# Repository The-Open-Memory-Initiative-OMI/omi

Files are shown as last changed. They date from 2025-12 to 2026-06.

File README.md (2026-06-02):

<!-- SPDX-License-Identifier: CC-BY-SA-4.0 -->

# The Open Memory Initiative (OMI)

The **Open Memory Initiative (OMI)** is a place to take memory hardware apart and rebuild it in the open - the kind of end-to-end reference work usually locked behind paywalled JEDEC raw cards and vendor NDAs. Every design decision is documented, every artifact is reproducible, and claims match reality: work is described at exactly the stage it has reached (schematic, validated, …), never more.

OMI treats memory as a *first-class architectural system*, not a black box.
The project emphasizes **documentation-first design**, explicit constraints, and reproducible validation - starting with mature PC DDR technologies.

This is an **engineering-first, correctness-oriented effort**, not a product launch.

---

## New here?

📄 **[START_HERE.md](./START_HERE.md)** — Beginner-friendly onboarding guide with contribution tracks, starter tasks, and a full repository map.

---

## Why OMI Exists

Open CPUs, SoCs, and accelerators are now common. System memory is not.

Despite being fundamental to computation, modern DRAM modules remain opaque, proprietary, and difficult to study or reproduce outside closed industrial contexts.

OMI exists to close this gap by providing:

- An open, reference-quality memory design target
- A transparent engineering methodology
- Documentation that explains *why* decisions were made, not just *what* was built

---

## Project Status

OMI v1 is a **reviewable DDR4 UDIMM reference design**: 8 GB, single rank (1R), x8 DRAM devices, non-ECC (64-bit bus). **The schematic stage is complete.**

### ✅ Schematic capture — complete, ERC-clean, and netlisted

The OMI v1 schematic is captured in KiCad and **passes Electrical Rule Check with 0 violations — no exclusions, no waivers**:

- A real **288-pin DDR4 UDIMM card-edge connector (`J1`)**, pin-mapped from the JEDEC keystone pin map. The placeholder host connectors used during early capture have been **removed** — `J1` is the genuine module edge.
- **18 / 18 real components footprinted**: `J1` (288-pad card edge), 8× DDR4 SDRAM (FBGA-78), one SPD EEPROM (UDFN-8), and 8× ZQ calibration resistors (R1–R8, 240 Ω).
- ERC reaches 0 through **real connections** — datasheet-genuine no-connect flags on truly-NC balls, VSS ties on `TEN`/`PAR`, the eight mandatory ZQ resistors, and `PWR_FLAG`s on host-supplied rails — **not** through exclusions or waivers.
- A **generated netlist** (KiCad XML + s-expression), **BOM** (CSV), and **5-page schematic PDF** are checked in under [`exports/`](./exports/), produced by an export step **gated on the clean ERC**.

**Evidence (reproducible):** [`exports/`](./exports/) holds the netlist, BOM, PDF, and `erc.json` (0 violations); [`exports/MANIFEST.txt`](./exports/MANIFEST.txt) records the source commit, `kicad-cli` version, and a SHA-256 for every artifact. The KiCad source is at [`design/power/omi_v1_power/`](./design/power/omi_v1_power/). The step-by-step engineering record is in [`docs/implementations/`](./docs/implementations/).

### What "validated" means here — and what it does not

OMI v1 is a **schematic-stage** study. At this stage, "validation" means three real, reproducible things:

- **L0 — artifact integrity:** the 288/288 edge pin map and net naming pass automated checks ([`validation/evidence/l0_summary.md`](./validation/evidence/l0_summary.md)).
- **ERC-clean:** the electrical rule check passes with 0 violations ([`exports/erc.json`](./exports/erc.json)).
- **Export provenance:** every exported artifact is hashed and traceable to a commit ([`exports/MANIFEST.txt`](./exports/MANIFEST.txt)).

**No hardware has been built, populated, or measured.** The physical bench-validation levels (**L1–L4**) are **defined as procedures but not executed** — there is no board, and there are no measurements. Any "PASS" in the bench-validation *framework* is a tooling/procedure dry-run over a blank template, **not** a hardware result (see [`validation/evidence/l1_summary.md`](./validation/evidence/l1_summary.md)).

### Scope boundary — what is *not* here (the wall)

OMI v1 stops at a complete, ERC-clean schematic. The following are **out of scope and do not exist** in this repository:

- **PCB layout, Gerbers, and stack-up** — none produced.
- **Signal-integrity / power-integrity (SI/PI) simulation** — none performed.
- **A fabricated or bench-tested board** — none built; no measurements taken.

Two caveats **scope** (they do not negate) the completed schematic:

- **`J1` models the 288 numbered pads only.** Exact JEDEC notch position, card-edge outline, and pad-mechanical geometry are a layout/mechanical concern and are **unproven** here.
- **Label-on-pin connectivity.** Global net labels are anchored directly on `J1` pins. This is ERC-clean and correct, but it is a known KiCad structural quirk (it prevented directional pin retyping) and is flagged for future cleanup.

### How the schematic was reached — documentation stages

The completed schematic above was produced through OMI's staged, documentation-first method:

- **Stage 5 — Architecture Decisions** — OMI v1 direction locked (DDR4 UDIMM baseline).
- **Stage 6 — Block Decomposition** — power, CA/CLK, DQ/DQS, SPD, and mechanical blocks documented.
- **Stage 7 — Schematic Capture — complete** — design intent (7.1 power/PDN, 7.2 CA/CLK, 7.3 DQ/DQS byte-lanes, 7.4 SPD, 7.5 288/288 edge pin map, 7.6 interface summary, 7.7 closure) **realized** as the ERC-clean, footprint-complete, netlisted KiCad design described above.
- **Stage 8 — Validation & Bring-Up Strategy — documentation complete** — the L0–L4 ladder, platform strategy, bring-up procedure, test-point/DFT plan, failure-mode catalog, and review checklists are written. **L0 and ERC are satisfied today; physical L1–L4 execution awaits a fabricated board.**

### Beyond the wall — not started

- **Stage 9 — Minimal Reference Schematic refinements** (e.g. SPD hex image / EEPROM content) and **Stage 10 — Layout & SI/PI Guidelines** (PCB layout, impedance, stack-up, signal/power integrity). These are the stages that stand between this schematic and verifiable hardware, and they are **not started**.

OMI prioritizes **structural correctness and reproducibility** over speed.

---

## Repository Navigation

OMI is organized by engineering stages:

```
design/power/omi_v1_power/            ← KiCad schematic — the actual capture (J1 edge, DRAM, SPD, ZQ),
                                          omi.kicad_sym library, and the J1 card-edge footprint
exports/                              ← Generated netlist, BOM, schematic PDF, erc.json (0 violations), MANIFEST.txt
docs/05_power_delivery_and_pdn/       ← Power delivery & PDN assumptions
docs/06_signal_topology_and_routing/  ← Signal topology: CA/CLK, DQ/DQS, routing philosophy
docs/07_schematic_capture/            ← Stage 7: schematic-level intent and design rationale
docs/08_validation_and_review/        ← Stage 8: validation framework, procedures, checklists
docs/implementations/                 ← Phase-by-phase record of how the schematic was completed
docs/v1/                              ← OMI v1 decision docs (form factor, capacity, etc.)
design/connector/                     ← 288-pin UDIMM edge connector CSV pin map
validation/evidence/                  ← L0 artifact-integrity evidence (real) + L1 framework dry-run (not measurements)
validation/runs/                      ← Bench run logs (empty until a board is fabricated)
```

If you're new: start with the engineering method doc below, then skim the Stage 5–6 design docs, then read the completed schematic and its evidence in [`exports/`](./exports/).

---

## How OMI Is Engineered

OMI follows a documentation-first, staged engineering methodology designed to preserve correctness, clarity, and reproducibility from architecture through implementation.

📄 **[How OMI Is Engineered](./docs/how_omi_is_engineered.md)** — the canonical reference for contributors. It explains the staged process, architectural constraints, validation philosophy, and what "success" means for OMI.

New contributors are strongly encouraged to read it first.

---

## Project Charter

OMI operates under a published charter that defines its purpose, scope, governance, and non-negotiable principles.

📄 **[CHARTER.md](./CHARTER.md)**

The charter protects openness, long-term maintainability, and technical integrity.

---

## Contributing

Contributions are welcome, but **discipline matters**.

Before contributing, please read:

- 📄 **[START_HERE.md](./START_HERE.md)** — onboarding, tracks, and starter tasks
- 📄 **[CHARTER.md](./CHARTER.md)** — purpose, scope, governance
- 📄 **[CONTRIBUTING.md](./CONTRIBUTING.md)** — how to participate and what is expected
- 📄 **[CODE_OF_CONDUCT.md](./CODE_OF_CONDUCT.md)** — the conduct expected of everyone who participates

Good ways to engage:

- Review Stage 5–7 documents and challenge assumptions
- Ask critical questions in GitHub Discussions
- Open issues for concrete, actionable topics (with clear acceptance criteria)
- Pick a contribution track (developer, reviewer, or tester) from [START_HERE.md](./START_HERE.md)

OMI values **careful review and precise feedback** more than rapid iteration.

---

## What OMI Is (and Is Not)

### OMI is:

- An open, community-driven engineering initiative
- Focused on real, buildable memory designs
- Documentation-heavy and charter-first
- Incremental and scope-disciplined

### OMI is not:

- A commercial product
- A vendor-specific effort
- A marketing project
- A shortcut to production hardware
- An NDA-gated or closed initiative

---

## Background & Motivation

The original motivation for OMI is described in these essays:

- [Open Memory Is Not a Luxury — Introducing the Open Memory Initiative (OMI)](https://medium.com/@mefe.sensoy/open-memory-is-not-a-luxury-introducing-the-open-memory-initiative-omi-77d189299f6d)
- [The Open Memory Initiative (OMI): Toward an Open, Reproducible DDR Memory Module](https://www.linkedin.com/pulse/open-memory-initiative-omi-toward-reproducible-ddr-module-%C5%9Fensoy-8aqee/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)

These provide historical and ecosystem context. The repository documents the engineering reality.

---

## Governance

Technical direction is guided by transparency, documentation quality, reproducibility, and long-term sustainability. Decisions are expected to be explainable and reviewable.

See [CHARTER.md](./CHARTER.md) for the full governance model.

---

## Licensing

This project uses a multi-license approach to properly cover all content types.
Each license maps to a specific part of the repository:

| Content type | Applies to | License | File |
|---|---|---|---|
| Hardware design | `design/**` — schematics, PCB layouts, connector data, design artifacts | CERN Open Hardware Licence v2 — Strongly Reciprocal (CERN-OHL-S-2.0) | [`LICENSE`](LICENSE) |
| Documentation | `docs/**` and the root prose docs — charter, scope, methodology, learning materials | Creative Commons Attribution-ShareAlike 4.0 International (CC BY-SA 4.0) | [`LICENSE-docs`](LICENSE-docs) |
| Software / code | `docs/08_validation_and_review/scripts/**` — validation scripts, test tooling, automation | Apache License 2.0 | [`LICENSE-software`](LICENSE-software) |

All contributions must comply with these licenses and with the openness and
redistribution principles defined in [CHARTER.md](CHARTER.md).

## Publications

- [OMI Enters Stage 8: Turning a DDR4 UDIMM Schematic into Verifiable Hardware](https://medium.com/@mefe.sensoy/omi-enters-stage-8-turning-a-ddr4-udimm-schematic-into-verifiable-hardware-c6d252b0e1d3)

  *Scope note:* this essay frames the project's **direction**. What this repository contains **today** is a complete, ERC-clean DDR4 UDIMM **schematic** with a generated netlist, BOM, and PDF — **not** fabricated or bench-verified hardware. Turning the schematic into *verifiable hardware* (layout, fabrication, bring-up) remains future work, beyond the current scope (see **Project Status → Scope boundary**, above).

---

## Questions & Discussion

- **[GitHub Issues](https://github.com/The-Open-Memory-Initiative-OMI/omi/issues)** → concrete, actionable topics
- **[GitHub Discussions](https://github.com/The-Open-Memory-Initiative-OMI/omi/discussions)** → open-ended or architectural conversations

Clear questions help build a clear project.

---

> OMI values careful, transparent engineering over speed.
> Correctness first. Reproducibility always.

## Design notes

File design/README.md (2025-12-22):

# Stage 5 — Design Translation

This directory contains the **design translation layer** of the Open Memory Initiative (OMI).

Stage 5 is where the knowledge built in earlier stages is translated into **explicit architectural decisions** that define the shape of the DIMM before any schematic or PCB layout work begins.

This stage exists to prevent ambiguity, rework, and hidden assumptions.

---

## What Stage 5 Is

Stage 5 is **architectural design**, not implementation.

It answers questions such as:

- What signals exist in this design?
- How are they grouped and related?
- What topologies are used, and why?
- What constraints must be respected?
- What power structure is assumed?

All answers in this stage must be:

- Explicit
- Documented
- Justified by earlier stages

---

## What Stage 5 Is NOT

Stage 5 does **not** include:

- PCB routing
- Schematic capture
- Component selection
- Performance tuning
- Vendor-specific optimizations
- Simulation or measurement results

Those belong to later stages.

If a document requires CAD tools or part numbers, it does not belong here.

---

## Why This Stage Exists

Memory systems fail when:

- Design intent is implicit
- Knowledge is scattered
- Constraints are undocumented
- Decisions are made ad hoc during layout

Stage 5 exists to:

- Lock architectural intent
- Make design decisions reviewable
- Enable reproducibility
- Support collaboration
- Reduce downstream risk

This stage is a **contract** between understanding and implementation.

---

## How This Stage Builds on Earlier Work

Stage 5 depends directly on:

- **System context**  
  What the CPU assumes and what must never fail

- **DRAM fundamentals**  
  Why margins are narrow and restoration is fragile

- **DDR protocol**  
  What commands, timings, and bursts require

- **DIMM anatomy**  
  What physical subsystems exist and why

- **Signal integrity**  
  How geometry, noise, and topology affect correctness

No design decision in this stage should contradict those foundations.

---

## Directory Structure

Stage 5 is organized by **type of decision**, not by implementation order.

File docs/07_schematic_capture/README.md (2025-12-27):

# 07 — Schematic Capture

## Purpose

This directory contains the **schematic implementation** of **OMI v1**.

Stage 7 exists to **translate the fully locked architectural intent of Stage 6 into a complete, reviewable electrical schematic**.  
No new architecture, features, or assumptions are introduced here.

This is an **execution stage**, not a design exploration stage.

---

## Entry Conditions (Hard Gate)

Work in this directory may begin **only if**:

- Stage 5 (scope locking) is complete  
- Stage 6.1–6.7 (technical decomposition) is complete  
- Stage 6 closure has been explicitly declared  
- No open architectural or scope questions remain  

If any assumption is unclear, work must pause and documentation must be updated **before continuing**.

---

## Scope

This directory covers **schematic capture only**.

### Included
- Electrical schematics implementing all Stage 6 blocks  
- Explicit connectivity for power, signals, configuration, and connector  
- Clear signal naming, grouping, and documentation  
- Reviewable schematic artifacts (native files and PDFs)  

### Explicitly Excluded
- PCB layout or routing  
- Signal integrity or power integrity simulation  
- BOM cost optimization  
- Validation execution or testing  

Those belong to later stages.

---

## Design Philosophy

Schematic capture in OMI v1 follows these principles:

- **Fidelity over creativity**  
- **Completeness over speed**  
- **Clarity over compactness**  
- **Explicit behavior over implicit assumptions**  

A schematic that "probably works" but cannot be explained is considered incorrect.

---

## Rules of Engagement (Non-Negotiable)

While working in Stage 7:

- No new features may be added  
- No topology changes may be introduced  
- No assumptions may remain undocumented  
- No "just in case" circuitry is allowed  
- No optimization for performance is permitted  

If a schematic decision requires creativity, **stop** and revisit documentation.

Stage 7 implements decisions — it does not make them.

---

## Required Schematic Structure

Schematic pages **must mirror Stage 6 blocks**.

The expected page structure is:

1. **Power & PDN**
2. **Address / Command / Clock**
3. **Data Byte-Lane (template)**
4. **Data Byte-Lane Replication**
5. **SPD & I²C**
6. **Connector / Edge Interface**
7. **Notes & References**

Mixing unrelated concerns on the same page is not allowed.

---

## Review Philosophy

Schematic review focuses on:

- Conformance to Stage 6 documentation  
- Internal consistency and completeness  
- Signal traceability end-to-end  
- Power-up and reset behavior clarity  
- Debuggability and observability  

Performance, cost, or optimization are **not** review criteria at this stage.

A schematic passes review only if a reviewer can explain its behavior **without oral context**.

---

## Change Management

Once a schematic page is reviewed and accepted:

- It is considered **frozen**
- Changes require:
  - A documented reason
  - Identification of impacted Stage 6 assumptions
  - Explicit reviewer acknowledgment

Silent fixes are not allowed.

---

## Expected Outputs

Stage 7 produces:

- Complete schematic files
- PDF exports for review
- Review notes and resolutions
- A frozen, copper-ready schematic package

These outputs authorize progression to **Stage 8 — Validation & Bring-Up Execution**.

---

## Common Failure Modes (Avoid These)

- Starting with data lanes before power is defined  
- Relying on layout to "fix" schematic ambiguity  
- Leaving pins floating without explanation  
- Assuming controller behavior without documentation  
- Treating schematics as art instead of proof  

---

## Completion Criteria

Stage 7 is complete only when:

- Every Stage 6 block is traceable in the schematic  
- No undocumented assumptions remain  
- At least one structured schematic review is passed  
- The schematic is frozen for layout  

---

## One-Sentence Anchor

> **Stage 7 is where ambiguity is eliminated, not deferred.**

---

*This directory marks the transition from architectural intent to physical reality.*

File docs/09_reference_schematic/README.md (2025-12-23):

# Stage 9 — Minimal Reference Schematic

Stage 9 defines the **Minimal Reference Schematic** for the OMI v1 DIMM design.

This schematic is:
- Intentionally minimal
- Architecturally faithful
- Correctness-first
- Fully reviewable using Stage 8 validation rules

Its purpose is not to be production-ready, but to be **unambiguously correct**.

---

## Purpose of the Minimal Reference Schematic

The Minimal Reference Schematic exists to:

- Prove that the architecture can be implemented cleanly
- Demonstrate correct signal grouping and topology
- Make all constraints visible in a real schematic
- Serve as a canonical reference for contributors

If this schematic is correct, more complex versions can be derived safely.

---

## What "Minimal" Means (Very Important)

Minimal does **not** mean incomplete.

Minimal means:
- No optional features
- No optimizations
- No speculative enhancements
- No performance-driven complexity

Everything present must exist **because the architecture requires it**, not because it might be useful later.

---

## What the Reference Schematic Includes

The Minimal Reference Schematic includes:

- One DIMM connector (conceptual or standard-aligned)
- One rank of DRAM devices
- The minimum number of byte lanes required by the chosen DDR width
- One SPD device
- Explicit power rails
- Explicit decoupling placeholders
- Explicit clock, command, and data grouping

Nothing more.

---

## What the Reference Schematic Explicitly Excludes

The schematic must **not** include:

- Multiple ranks
- Optional ECC (unless explicitly scoped)
- Register or buffer logic
- Power regulation circuitry
- Performance tuning components
- Vendor-specific enhancements

Exclusions are intentional and must remain so.

---

## Required Schematic Sheet Structure

The reference schematic must follow the Stage 7 guide exactly.

Recommended sheet set:

01_dimm_connector.sch
02_power_distribution.sch
03_dram_array_overview.sch
04_byte_lane_0.sch
05_byte_lane_1.sch
...
NN_spd_and_aux.sch

Each sheet must have a single, clear responsibility.

---

## DRAM Devices in the Reference Schematic

Rules:

- Use generic DRAM symbols
- Do not assume a specific vendor
- Show only architecturally relevant pins
- Power, ground, DQ, DQS, address, command, clock only

Unused pins must be:
- Explicitly marked
- Justified

No hidden behavior is allowed.

---

## Data Path Requirements

For each byte lane:

- Exactly one DQ bundle
- Exactly one DQS (and complement if applicable)
- Clear point-to-point connectivity
- No stubs
- No shared nets between lanes

Each lane must be independently traceable.

---

## Address, Command, and Clock Requirements

- Address and command must appear as shared buses
- Clock must appear as a shared differential pair
- Rank select must be explicit (even if only one rank)
- No local buffering or regeneration

Topology must be obvious from the schematic alone.

---

## Power and Decoupling Requirements

- VDD, VDDQ, Vref, VTT, and auxiliary rails must be separate
- Decoupling placeholders must exist per rail
- Decoupling must be rail-specific (not generic)
- Vref must not power logic
- VTT must only serve termination-related pins

Power intent must be visible, not implied.

---

## SPD and Auxiliary Logic Requirements

- SPD must be powered only from auxiliary/standby rail
- SPD must connect only to the low-speed management bus
- No DDR signals allowed on the SPD sheet
- Clear isolation from high-speed domains

SPD failure must not electrically affect DRAM operation.

---

## Validation Requirements

The reference schematic must pass **all Stage 8 validation layers**:

- Architecture compliance
- Schematic structure review
- Constraint adherence
- Power integrity sanity
- Failure containment

If any checklist item fails, the schematic is not acceptable.

---

## What Makes This a "Reference"

This schematic is a reference because:

- It is readable without tribal knowledge
- It encodes architectural intent structurally
- It can be reviewed by independent engineers
- It can be reimplemented consistently

A reference schematic teaches by example.

---

## How Contributors Should Use This Schematic

Contributors may:
- Extend it cautiously
- Optimize it knowingly
- Specialize it for platforms

But they must:
- Preserve architectural intent
- Revalidate using Stage 8
- Document deviations explicitly

The reference is a baseline, not a ceiling.

---

## Takeaway

Stage 9 turns intent into reality — carefully.

The Minimal Reference Schematic proves that:
- The architecture is implementable
- The constraints are enforceable
- The design is reviewable
- The project is real

Complexity can come later.
Correctness must come first.

---

Next stages:
- Stage 10 — Layout Guidelines
- Stage 10 — Signal Integrity Validation
- Stage 10 — Power Integrity Validation

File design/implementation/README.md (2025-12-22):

# Stage 6 — Implementation Translation

Stage 6 is where the architectural decisions defined in Stage 5 are translated into **implementation-ready artifacts**.

This stage does not yet produce a finished schematic or PCB.
It produces **structures that make correct implementation inevitable**.

The purpose of Stage 6 is to bridge the gap between design intent and physical realization without losing correctness.

---

## What Stage 6 Is

Stage 6 is about **translation**, not invention.

It takes:

- Signals
- Topology
- Constraints
- Power architecture
- Assumptions

and converts them into:

- Block-level schematic structure
- Clear interface boundaries
- Implementation-safe groupings
- Layout-ready intent

Every artifact in this stage must trace directly back to Stage 5.

---

## What Stage 6 Is NOT

Stage 6 does **not** include:

- Final schematics
- PCB routing
- Component selection
- Value tuning
- Signal simulation
- Optimization or cost reduction

If a decision introduces *new architectural behavior*, it does not belong here.

---

## Why Stage 6 Exists

Without Stage 6:

- Schematics become ambiguous
- Layout decisions encode hidden assumptions
- Constraints are interpreted inconsistently
- Reviews become subjective

Stage 6 exists to:

- Make implementation reviewable
- Preserve architectural intent
- Reduce rework
- Enable collaboration

This stage ensures that **the PCB cannot accidentally violate the design**.

---

## Inputs to Stage 6

Stage 6 depends on the following completed work:

- Signal maps (Stage 5)
- Topology decisions (Stage 5)
- Length matching and skew constraints
- Power rails and decoupling strategy
- Explicit design assumptions

No document in Stage 6 may contradict these inputs.

---

## Outputs of Stage 6

Stage 6 produces **implementation guidance**, not hardware.

Typical outputs include:

- Block-level schematic diagrams
- Functional grouping of pins and nets
- Connector interface definitions
- Power distribution structure
- Constraint translation notes

These outputs are precise enough that:

> Two independent engineers would implement **functionally equivalent designs**.

---

## Rules for Stage 6 Documents

All Stage 6 documents must:

- Reference Stage 5 decisions explicitly
- Avoid numerical tuning unless unavoidable
- Avoid layout-specific language
- Avoid vendor-specific parts
- Be readable without CAD tools

If a document requires a schematic editor to understand, it is too late-stage.

---

## How to Read Stage 6

The recommended reading order is:

1. `blocks/`  
   Understand functional partitioning

2. `interfaces/`  
   Understand boundaries and ownership

3. `pin_grouping/`  
   Understand how signals are organized physically

4. `constraint_translation.md`  
   Understand how architecture constrains implementation

Skipping steps risks misinterpretation.

---

## Design Philosophy at This Stage

Stage 6 follows these principles:

- Architecture is already decided
- Implementation must obey, not reinterpret
- Ambiguity is a bug
- Simplicity beats cleverness
- Reproducibility beats optimization

If something feels like a "design choice" here, it probably belongs in Stage 5 instead.

---

## Completion Criteria for Stage 6

Stage 6 is complete when:

- All functional blocks are defined
- All interfaces are documented
- Pin groupings reflect signal intent
- Constraints are implementation-visible
- No architectural decisions remain implicit

Only after this stage should:

- Schematic capture begin
- Layout work begin
- Component selection occur

---

## Takeaway

Stage 6 ensures that:

- Architecture survives contact with reality
- Implementation is disciplined
- Mistakes are hard to make silently

Stage 5 defined **what must be true**.  
Stage 6 ensures it **stays true**.

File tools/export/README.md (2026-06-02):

<!-- SPDX-License-Identifier: Apache-2.0 -->
# `tools/export` — OMI v1 schematic-side export pipeline

`export.ps1` regenerates the in-repo export set (`exports/`) from the schematic, **gated on a
clean ERC**. It is a Windows PowerShell (`powershell.exe`) script. This is a *usage* note; for the
design rationale see `docs/implementations/2026-06-02-phase6-exports.md`.

## What it produces

Into `exports/` (repo-relative by default):

| File | What it is |
|---|---|
| `erc.json` | ERC report (the gate's evidence; 0 violations) |
| `omi_v1.netlist.xml` | Netlist, KiCad XML format |
| `omi_v1.net` | Netlist, KiCad S-expression format |
| `omi_v1.bom.csv` | BOM (grouped by Value+Footprint), with a `Procurement_Note` column |
| `omi_v1.schematic.pdf` | Combined schematic PDF, all sheets |
| `MANIFEST.txt` | Export-provenance manifest: UTC time, git HEAD, kicad-cli version, ERC-clean confirmation, SHA-256 of every artifact above |

## The ERC-0 gate

ERC runs **first**. If the schematic has **any** ERC violation, the script prints an error and
**exits non-zero without producing any export** — exports only ever come from a verified-clean
design. A fully clean run exits `0`.

## Requirements

- **KiCad 9.0** `kicad-cli` (file format `20250114`) — **not** 10.x, which the script rejects.
  Auto-detected under `%LOCALAPPDATA%\Programs\KiCad\9.0\bin`, `Program Files\KiCad\9.0\bin`, or
  `PATH`; otherwise pass `-KicadBin`.
- `git` on `PATH` (for the manifest's HEAD; the script still runs without it, recording the HEAD
  as unavailable).

## Run

```powershell
# from the repo root
powershell.exe -ExecutionPolicy Bypass -File tools\export\export.ps1

# explicit kicad-cli path / custom output dir
powershell.exe -ExecutionPolicy Bypass -File tools\export\export.ps1 `
  -KicadBin "C:\Users\me\AppData\Local\Programs\KiCad\9.0\bin\kicad-cli.exe" `
  -OutDir exports
```

The script is **idempotent**: each run clears and regenerates the artifacts (the manifest's UTC
timestamp and hashes change accordingly).

## Scope note

The manifest is an **export-provenance** record (how/when/from-what-commit the files were
generated, and that ERC was clean) — **not** a validation, verification, bench, or hardware-test
record. OMI v1 is a schematic-stage reference-design study; PCB layout, Gerbers, and SI/PI remain
out of scope. In the BOM, **`J1` is the PCB card edge** (board copper fingers), annotated as *not a
purchased part*; the DRAM, SPD, and ZQ resistors are real, purchasable lines.

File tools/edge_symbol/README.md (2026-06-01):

# `gen_edge_symbol.py` — 288-pin DDR4 UDIMM edge-connector generator

`gen_edge_symbol.py` turns the keystone pinmap into the KiCad artifacts for the UDIMM
edge connector. It is **standard-library-only Python 3** (no pip dependencies) and is
fully deterministic: the same CSV always produces byte-identical output.

## What it reads

```
design/connector/ddr4_udimm_288_pinmap.csv     # header: pin,symbol,omi_net,group,notes
```

This CSV is the **single source of truth** and is never modified by the generator.

## What it writes

| Output | Path (default) | Notes |
| --- | --- | --- |
| Symbol library | `design/power/omi_v1_power/omi.kicad_sym` | one symbol, `DDR4_UDIMM_288_Edge`, 288 pins |
| Populated edge sheet | `design/power/omi_v1_power/udimm-edge-interface.kicad_sch` | one `J1` instance + `global_label` per non-NC pin |

The library is registered in `design/power/omi_v1_power/sym-lib-table` under the nickname
`omi`, so the symbol's `lib_id` is `omi:DDR4_UDIMM_288_Edge`.

## CSV → symbol mapping

* **pin number** ← CSV `pin`
* **pin name** ← CSV `symbol` (the JEDEC / functional name shown on the body)
* **electrical type**:
  * `no_connect` when `omi_net == "NC"` (ECC/CB lanes, 2nd-rank, reserved — kept out of the
    ERC "unconnected" tally by design);
  * `passive` otherwise — **including power/ground by default**. Power pins can be promoted to
    `power_in` with `--power-type power_in`, but that requires PWR_FLAGs to satisfy ERC and is a
    Phase-5 decision, so `passive` is the default to keep this additive phase ERC-neutral.

Net labels use **`global_label`**, the dominant label type in this design, so the `omi_net`
names merge across sheets automatically. NC pins are left unconnected (their `no_connect`
type makes that ERC-clean); they are never labelled with a signal net.

## Regenerate

```powershell
python tools\edge_symbol\gen_edge_symbol.py
```

Useful flags:

| Flag | Effect |
| --- | --- |
| `--no-sheet` | emit only the symbol library (defer placement) |
| `--power-type power_in` | type POWER-group pins `power_in` instead of `passive` (needs PWR_FLAGs; Phase 5) |
| `--verify` | re-parse `omi.kicad_sym` and assert 288 pins whose number+name+type match the CSV exactly |
| `--csv / --out-sym / --out-sheet` | override input/output paths |

## Validate (KiCad 9.0 `kicad-cli`)

```powershell
$bin = "$env:LOCALAPPDATA\Programs\KiCad\9.0\bin\kicad-cli.exe"
& $bin sym upgrade -o build\p2\omi_upgraded.kicad_sym design\power\omi_v1_power\omi.kicad_sym
& $bin sym export svg -o build\p2 design\power\omi_v1_power\omi.kicad_sym
python tools\edge_symbol\gen_edge_symbol.py --verify
& $bin sch erc --severity-all --format json -o build\p2\erc_after.json design\power\omi_v1_power\omi_v1_power.kicad_sch
& $bin sch export netlist --format kicadxml -o build\p2\netlist_after.xml design\power\omi_v1_power\omi_v1_power.kicad_sch
```

Use the **KiCad 9.0** `kicad-cli` (schematic format `20250114`), not 10.x.

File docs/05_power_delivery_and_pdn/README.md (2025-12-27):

# 05 — Power Delivery & PDN

## Purpose

This directory defines the **power delivery and power distribution network (PDN) assumptions** for **OMI v1**.

It documents **what power rails exist, how they are sourced, and what constraints apply**, before any schematic capture or layout work begins.

Power delivery is treated as a **first-class architectural block**, because mistakes or ambiguity at this level propagate into signal integrity, training behavior, validation complexity, and bring-up risk.

---

## Scope

The content in this directory focuses on **definition and intent**, not implementation.

Included:

- Required DDR4 power rails for an OMI v1 UDIMM  
- Nominal voltages and JEDEC-aligned tolerances  
- Rail sourcing assumptions (host-supplied vs on-DIMM)  
- Conceptual PDN and decoupling philosophy  
- Power-up, sequencing, and dependency assumptions  
- Observability and validation considerations  

Explicitly excluded:

- Regulator or LDO part selection  
- Capacitor values, footprints, or placement  
- PCB routing or schematic symbols  
- Performance or cost optimization  

Implementation details belong to **Stage 7 — Schematic Capture**.

---

## Files in This Directory

### `power-delivery.md`

The primary **Stage 6.1 block definition** for power delivery.

This document specifies:
- Required power rails (VDD, VDDQ, VPP, VREF, GND)  
- Voltage assumptions and tolerances  
- PDN philosophy and non-goals  
- Expected failure modes and validation observability  

All downstream design work must conform to the assumptions defined here.

---

## Relationship to Other Stages

This directory sits at the boundary between **scope locking (Stage 5)** and **schematic capture (Stage 7)**.

It directly informs:

- `06_signal_topology_and_routing` — signal integrity and routing constraints  
- `07_schematic_capture` — actual circuit implementation  
- `08_validation_and_review` — bring-up and power-related failure analysis  

No schematic or layout work should begin until the assumptions in this directory are understood and accepted.

---

## Design Philosophy

Power delivery in OMI v1 follows these principles:

- Conservative, margin-first design  
- JEDEC-compliant behavior only  
- Explicit assumptions, no implicit platform behavior  
- Failure treated as engineering data  
- Observability over optimization  

This directory exists to ensure those principles are enforced consistently.

---

## Contribution Guidelines

Contributions to this directory should:

- Improve clarity of assumptions  
- Identify risks, ambiguities, or missing constraints  
- Propose documentation improvements (not implementation shortcuts)  

Contributions that introduce schematic-level detail or vendor-specific behavior will be deferred to later stages.

---

## Status

- Stage: **6.1 — Power Delivery Block**
- Maturity: **Definition complete / implementation pending**
- Scope: **OMI v1 only**

---

*Power delivery defines the electrical floor every other block stands on.*

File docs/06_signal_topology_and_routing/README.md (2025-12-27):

# 06 — Signal Topology & Routing

## Purpose

This directory defines the **signal topology, loading assumptions, and routing philosophy** for the OMI v1 DDR4 UDIMM.

It captures **how signals are conceptually organized and expected to behave**, before any schematic capture or PCB routing begins. The intent is to eliminate hidden assumptions and ensure that all signal-related design work proceeds from a shared, documented understanding.

This directory exists to bridge **architectural intent (Stage 6)** and **implementation (Stage 7)**.

---

## Scope

The content in this directory focuses on **signal definition and topology**, not implementation.

Included:

- Address, command, and control signal definitions  
- Clocking assumptions and topology  
- Data byte-lane and DQS group concepts  
- Loading and rank assumptions  
- Conceptual termination and margin philosophy  
- Timing sensitivity and training interactions  
- Observability and validation considerations  

Explicitly excluded:

- Pin-level schematic decisions  
- Trace length targets or routing rules  
- Impedance calculations or stack-up specifics  
- Resistor values, placement, or component footprints  
- Vendor- or platform-specific tuning  

Implementation details belong to **Stage 7 — Schematic Capture** and **Stage 10 — Layout, SI & PI Guidelines**.

---

## Files in This Directory

### `address-command-clock.md`

Defines the **Address / Command / Clock (CA) block** for OMI v1.

This document specifies:
- CA and control signal groups  
- Clocking model and topology assumptions  
- Rank and loading behavior  
- Termination philosophy  
- Timing sensitivity and training interactions  
- Expected failure modes and validation observability  

This file establishes how the memory controller communicates with the DRAM devices at a conceptual level.

---

### *(Future)* `data-byte-lanes-and-dqs.md`

Will define the **data path block**, including:
- DQ, DQS, and DM signal grouping  
- Byte-lane organization for x8 devices  
- Symmetry and matching philosophy  
- Data-related timing sensitivities  
- Failure modes related to read/write training  

---

## Relationship to Other Stages

This directory directly depends on:

- `05_power_delivery_and_pdn` — rail stability and reference assumptions  

And directly informs:

- `07_schematic_capture` — pin-level and circuit implementation  
- `08_validation_and_review` — bring-up and training analysis  
- `10_layout_si_pi_guidelines` — detailed routing constraints  

No schematic or routing work should begin until the assumptions in this directory are understood and accepted.

---

## Design Philosophy

Signal topology decisions in OMI v1 are guided by:

- JEDEC-compliant behavior only  
- Single-rank simplicity  
- Margin-first assumptions  
- Explicit loading and topology documentation  
- Failure treated as engineering data  

This directory prioritizes **clarity and diagnosability** over performance optimization.

---

## Contribution Guidelines

Contributions to this directory should:

- Clarify assumptions or signal roles  
- Identify risks, ambiguities, or missing constraints  
- Improve documentation precision  

Contributions that introduce schematic-level detail, routing rules, or platform-specific tuning will be deferred to later stages.

---

## Status

- Stage: **6 — Technical Decomposition**
- Current focus: **6.2 Address / Command / Clock Block**
- Maturity: **Definition in progress**
- Scope: **OMI v1 only**

---

*Signal topology defines how intent becomes connectivity. Clarity here prevents silent failure later.*

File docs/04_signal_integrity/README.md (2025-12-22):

# Stage 4 — Signal Integrity

Stage 4 explains **why high-speed memory signals behave the way they do**, and how physical design choices translate directly into timing margins, data corruption, or reliability.

This stage is intentionally **analytical**.

It does not focus on layout rules first.
It focuses on understanding the *physics* that make those rules necessary.

---

## Why Signal Integrity Deserves Its Own Stage

At DDR speeds, signal integrity is not an optimization topic.
It is a **correctness topic**.

If signal integrity fails:

- Timing parameters are violated
- Setup and hold margins collapse
- Data is sampled incorrectly
- Errors appear silent and intermittent

No amount of protocol correctness can compensate for poor signal integrity.

---

## What Signal Integrity Actually Means

In the context of DDR memory, signal integrity means:

- Signals arrive when they are expected
- Signals settle to valid logic levels before sampling
- Noise does not cross decision thresholds
- Timing skew remains within margins
- Behavior is predictable across temperature and load

Signal integrity is not about "clean-looking waveforms".
It is about **preserving timing and voltage margins**.

---

## How This Stage Builds on Earlier Stages

Stage 4 depends directly on:

- **Stage 1 — DRAM Fundamentals**  
  (fragile sensing, destructive reads)

- **Stage 2 — DDR Protocol**  
  (tight timing contracts, burst behavior, bank groups)

- **Stage 3 — DIMM Anatomy**  
  (termination, topology, power rails, PCB effects)

Signal integrity explains *why those constraints exist physically*.

---

## Core Questions This Stage Answers

After completing Stage 4, a contributor should be able to answer:

- Why does a trace behave like a transmission line?
- Why do reflections shrink timing margins?
- Why does length mismatch cause data errors?
- Why does termination placement matter?
- Why does noise look pattern-dependent?
- Why do problems appear only at speed or under load?

If these questions feel intuitive, Stage 4 has succeeded.

---

## Documents in This Stage

The documents in Stage 4 should be read **in order**.

### 1. Transmission Lines
**`transmission_lines.md`**

Explains:

- When a wire becomes a transmission line
- Propagation delay
- Characteristic impedance
- Why "short traces" stop being short

This is the foundation of all signal integrity.

---

### 2. Reflections and Impedance Mismatch
**`reflections_and_matching.md`**

Explains:

- Why reflections occur
- How impedance mismatch creates ringing
- How reflections distort timing
- Why matching is about margins, not perfection

---

### 3. Length Matching and Skew
**`length_matching.md`**

Explains:

- How skew accumulates
- Why DDR timing windows are small
- Why byte lanes are matched
- Why address skew matters differently than data skew

---

### 4. Crosstalk and Noise Coupling
**`crosstalk_and_noise.md`**

Explains:

- Capacitive and inductive coupling
- Why adjacent signals interfere
- Why simultaneous switching noise matters
- Why activity-dependent failures occur

---

### 5. Eye Diagrams and Margins
**`eye_diagrams_and_margins.md`**

Explains:

- What an eye diagram represents
- How timing and voltage margins are visualized
- Why "passing" is not binary
- How margins disappear before failure

---

## What This Stage Does NOT Cover (Yet)

Stage 4 does not yet focus on:

- Specific PCB layout rules
- CAD tool workflows
- Vendor-specific constraints

Those come later, once intuition is built.

This stage teaches **why the rules exist**, not how to follow them blindly.

---

## Why OMI Emphasizes Signal Integrity

Many memory designs fail not because:

- The protocol was wrong
- The timings were incorrect
- The schematic was incomplete

But because:

- Physical effects were underestimated
- Margins were assumed instead of measured
- Layout choices were treated as cosmetic

OMI treats signal integrity as **core engineering knowledge**, not tribal expertise.

---

## Takeaway

At DDR speeds:

- Bits are waves
- Timing is geometry
- Noise is data-dependent
- Margins are fragile

Signal integrity is how we keep memory honest.

Stage 4 exists to make that understanding explicit.

---

Proceed to:
➡️ `transmission_lines.md`

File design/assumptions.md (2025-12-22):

# Design Assumptions and Non-Goals

This document defines the **explicit assumptions, constraints, and non-goals** for the OMI v1 DIMM design.

Its purpose is to:

- Prevent scope creep
- Make design intent unambiguous
- Clarify what the design does *not* attempt to solve
- Enable fair technical review

Any design decision must be interpreted in the context of these assumptions.

---

## Scope Definition

OMI v1 is a **reference-grade, correctness-first DIMM design**.

It is intended to:

- Demonstrate a complete, understandable DDR memory module architecture
- Prioritize correctness, margin, and reproducibility
- Serve as an educational and foundational open design

It is **not** intended to be a competitive commercial product.

---

## Assumptions About the Target System

The OMI v1 DIMM assumes:

- A standards-compliant DDR memory controller
- A single, known DDR generation (defined elsewhere)
- Controller-managed training and calibration
- Conservative operating conditions

The design does not attempt to compensate for:

- Non-compliant controllers
- Undefined platform behavior
- Broken training algorithms

Correctness is a shared contract.

---

## Performance Assumptions

OMI v1 assumes:

- JEDEC-compliant operating speeds
- No overclocking
- No aggressive timing margins
- No performance binning

The design explicitly avoids:

- Extreme frequency targets
- Margin-free operation
- Performance-driven tradeoffs

Performance is secondary to stability.

---

## Signal Integrity Assumptions

The design assumes:

- Proper PCB stack-up selection
- Continuous reference planes
- Controlled impedance routing
- Respect for documented constraints

OMI v1 does not attempt to:

- Compensate for poor layout
- Mask signal integrity violations
- Rely on calibration to fix physical mistakes

Physics is not optional.

---

## Power Integrity Assumptions

OMI v1 assumes:

- Proper external power regulation
- Adequate upstream supply stability
- Clean power delivery to the DIMM connector

The design does not attempt to:

- Fix unstable system power
- Replace platform-level regulation
- Operate under marginal power conditions

Power integrity is a system-level responsibility.

---

## Environmental Assumptions

The design assumes:

- Operation within standard temperature ranges
- Reasonable airflow and cooling
- Normal aging behavior

OMI v1 does not attempt to:

- Guarantee operation under extreme environments
- Compensate for thermal abuse
- Optimize for extended lifetime beyond standards

Environmental stress testing is out of scope.

---

## Manufacturing Assumptions

OMI v1 assumes:

- Standard PCB manufacturing tolerances
- Typical assembly quality
- No exotic fabrication techniques

The design avoids:

- Unmanufacturable geometries
- Ultra-tight tolerances
- Vendor-specific tricks

Reproducibility matters more than novelty.

---

## Validation Assumptions

OMI v1 assumes validation will include:

- Bring-up testing
- Basic functional testing
- Margin-aware evaluation

The design does not claim:

- Zero-defect operation
- Exhaustive corner-case coverage
- Field-ready qualification

OMI v1 is a **reference**, not a certified product.

---

## Explicit Non-Goals

OMI v1 explicitly does **not** attempt to:

- Maximize bandwidth
- Minimize cost
- Minimize PCB area
- Compete with commercial DIMMs
- Support every platform
- Hide design tradeoffs

These goals may exist in future versions, but not here.

---

## Why These Assumptions Matter

Without explicit assumptions:

- Designs become unreviewable
- Failures become ambiguous
- Responsibility becomes unclear

OMI documents assumptions so that:

- Success is measurable
- Failure is explainable
- Improvements are intentional

---

## Takeaway

OMI v1 is designed to be:

- Correct
- Understandable
- Reproducible
- Conservative

It is not designed to be everything.

These assumptions are not limitations.
They are **design boundaries**.

---

This document closes Stage 5.

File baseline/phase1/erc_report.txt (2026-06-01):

ERC report (2026-06-01T11:24:14+0300, Encoding UTF8)
Report includes: Errors, Warnings, Exclusions

***** Sheet /
[label_dangling]: Label not connected to anything
    ; error
    @(166.37 mm, 97.79 mm): Label 'VDDQ'
[label_dangling]: Label not connected to anything
    ; error
    @(166.37 mm, 102.87 mm): Label 'VREF'
[power_pin_not_driven]: Input Power pin not driven by any Output Power pins
    ; error
    @(171.45 mm, 105.41 mm): Symbol #PWR06 Pin 1 [Power input, Line]

***** Sheet /address-command-clock/
[pin_not_connected]: Pin not connected
    ; error
    @(31.75 mm, 29.21 mm): Symbol J_HOST Pin 40 [Pin_40, Passive, Line]
[pin_not_connected]: Pin not connected
    ; error
    @(34.29 mm, 29.21 mm): Symbol J_HOST Pin 39 [Pin_39, Passive, Line]
[pin_not_connected]: Pin not connected
    ; error
    @(36.83 mm, 29.21 mm): Symbol J_HOST Pin 38 [Pin_38, Passive, Line]
[pin_not_connected]: Pin not connected
    ; error
    @(39.37 mm, 29.21 mm): Symbol J_HOST Pin 37 [Pin_37, Passive, Line]
[pin_not_connected]: Pin not connected
    ; error
    @(41.91 mm, 29.21 mm): Symbol J_HOST Pin 36 [Pin_36, Passive, Line]
[pin_not_connected]: Pin not connected
    ; error
    @(44.45 mm, 29.21 mm): Symbol J_HOST Pin 35 [Pin_35, Passive, Line]
[pin_not_connected]: Pin not connected
    ; error
    @(46.99 mm, 29.21 mm): Symbol J_HOST Pin 34 [Pin_34, Passive, Line]
[pin_not_connected]: Pin not connected
    ; error
    @(49.53 mm, 29.21 mm): Symbol J_HOST Pin 33 [Pin_33, Passive, Line]
[pin_not_connected]: Pin not connected
    ; error
    @(52.07 mm, 29.21 mm): Symbol J_HOST Pin 32 [Pin_32, Passive, Line]
[pin_not_connected]: Pin not connected
    ; error
    @(54.61 mm, 29.21 mm): Symbol J_HOST Pin 31 [Pin_31, Passive, Line]
[pin_not_connected]: Pin not connected
    ; error
    @(57.15 mm, 29.21 mm): Symbol J_HOST Pin 30 [Pin_30, Passive, Line]
[power_pin_not_driven]: Input Power pin not driven by any Output Power pins
    ; error
    @(62.23 mm, 55.88 mm): Symbol U_DRAM0 Pin B2 [VDDQ, Power input, Line]
[power_pin_not_driven]: Input Power pin not driven by any Output Power pins
    ; error
    @(67.31 mm, 55.88 mm): Symbol #PWR03 Pin 1 [Power input, Line]
[pin_not_connected]: Pin not connected
    ; error
    @(44.45 mm, 114.30 mm): Symbol U_DRAM0 Pin N3 [PAR, Input, Line]
[pin_not_driven]: Input pin not driven by any Output pins
    ; error
    @(44.45 mm, 114.30 mm): Symbol U_DRAM0 Pin N3 [PAR, Input, Line]
[pin_not_connected]: Pin not connected
    ; error
    @(80.01 mm, 101.60 mm): Symbol U_DRAM0 Pin A3 [TDQS_c, Output, Line]
[pin_not_connected]: Pin not connected
    ; error
    @(44.45 mm, 121.92 mm): Symbol U_DRAM0 Pin F2 [NC/C2/ODT1, Passive, Line]
[pin_not_connected]: Pin not connected
    ; error
    @(44.45 mm, 127.00 mm): Symbol U_DRAM0 Pin G8 [NC/C1/~{CS1}, Passive, Line]
[pin_not_connected]: Pin not connected
    ; error
    @(80.01 mm, 111.76 mm): Symbol U_DRAM0 Pin B9 [ZQ, Passive, Line]
[pin_not_connected]: Pin not connected
    ; error
    @(44.45 mm, 132.08 mm): Symbol U_DRAM0 Pin G2 [NC/C0/CKE1, Passive, Line]
[pin_not_connected]: Pin not connected
    ; error
    @(80.01 mm, 116.84 mm): Symbol U_DRAM0 Pin L9 [~{ALERT}, Open collector, Line]
[power_pin_not_driven]: Input Power pin not driven by any Output Power pins
    ; error
    @(130.81 mm, 55.88 mm): Symbol #PWR01 Pin 1 [Power input, Line]
[pin_not_connected]: Pin not connected
    ; error
    @(44.45 mm, 144.78 mm): Symbol U_DRAM0 Pin G9 [TEN, Input, Line]
[pin_not_driven]: Input pin not driven by any Output pins
    ; error
    @(44.45 mm, 144.78 mm): Symbol U_DRAM0 Pin G9 [TEN, Input, Line]
[pin_not_connected]: Pin not connected
    ; error
    @(118.11 mm, 114.30 mm): Symbol U_DRAM1 Pin N3 [PAR, Input, Line]
[pin_not_driven]: Input pin not driven by any Output pins
    ; error
    @(118.11 mm, 114.30 mm): Symbol U_DRAM1 Pin N3 [PAR, Input, Line]
[pin_not_connected]: Pin not connected
    ; error
    @(118.11 mm, 121.92 mm): Symbol U_DRAM1 Pin F2 [NC/C2/ODT1, Passive, Line]
[pin_not_connected]: Pin not connected
    ; error
    @(118.11 mm, 127.00 mm): Symbol U_DRAM1 Pin G8 [NC/C1/~{CS1}, Passive, Line]
[pin_not_connected]: Pin not connected
    ; error
    @(118.11 mm, 132.08 mm): Symbol U_DRAM1 Pin G2 [NC/C0/CKE1, Passive, Line]
[pin_not_connected]: Pin not connected
    ; error
    @(153.67 mm, 101.60 mm): Symbol U_DRAM1 Pin A3 [TDQS_c, Output, Line]
[pin_not_connected]: Pin not connected
    ; error
    @(118.11 mm, 144.78 mm): Symbol U_DRAM1 Pin G9 [TEN, Input, Line]
[pin_not_driven]: Input pin not driven by any Output pins
    ; error
    @(118.11 mm, 144.78 mm): Symbol U_DRAM1 Pin G9 [TEN, Input, Line]
[pin_not_connected]: Pin not connected
    ; error
    @(153.67 mm, 111.76 mm): Symbol U_DRAM1 Pin B9 [ZQ, Passive, Line]
[pin_not_connected]: Pin not connected
    ; error
    @(153.67 mm, 116.84 mm): Symbol U_DRAM1 Pin L9 [~{ALERT}, Open collector, Line]
[pin_not_connected]: Pin not connected
    ; error
    @(189.23 mm, 114.30 mm): Symbol U_DRAM2 Pin N3 [PAR, Input, Line]
[pin_not_driven]: Input pin not driven by any Output pins
    ; error
    @(189.23 mm, 114.30 mm): Symbol U_DRAM2 Pin N3 [PAR, Input, Line]
[pin_not_connected]: Pin not connected
    ; error
    @(189.23 mm, 121.92 mm): Symbol U_DRAM2 Pin F2 [NC/C2/ODT1, Passive, Line]
[pin_not_connected]: Pin not connected
    ; error
    @(189.23 mm, 127.00 mm): Symbol U_DRAM2 Pin G8 [NC/C1/~{CS1}, Passive, Line]
[pin_not_connected]: Pin not connected
    ; error
    @(189.23 mm, 132.08 mm): Symbol U_DRAM2 Pin G2 [NC/C0/CKE1, Passive, Line]
[pin_not_connected]: Pin not connected
    ; error
    @(80.01 mm, 220.98 mm): Symbol U_DRAM5 Pin A3 [TDQS_c, Output, Line]
[pin_not_connected]: Pin not connected
    ; error
    @(44.45 mm, 233.68 mm): Symbol U_DRAM5 Pin N3 [PAR, Input, Line]
[pin_not_driven]: Input pin not driven by any Output pins
    ; error
    @(44.45 mm, 233.68 mm): Symbol U_DRAM5 Pin N3 [PAR, Input, Line]
[pin_not_connected]: Pin not connected
    ; error
    @(189.23 mm, 144.78 mm): Symbol U_DRAM2 Pin G9 [TEN, Input, Line]
[pin_not_driven]: Input pin not driven by any Output pins
    ; error
    @(189.23 mm, 144.78 mm): Symbol U_DRAM2 Pin G9 [TEN, Input, Line]
[pin_not_connected]: Pin not connected
    ; error
    @(80.01 mm, 231.14 mm): Symbol U_DRAM5 Pin B9 [ZQ, Passive, Line]
[pin_not_connected]: Pin not connected
    ; error
    @(44.45 mm, 241.30 mm): Symbol U_DRAM5 Pin F2 [NC/C2/ODT1, Passive, Line]
[pin_not_connected]: Pin not connected
    ; error
    @(224.79 mm, 101.60 mm): Symbol U_DRAM2 Pin A3 [TDQS_c, Output, Line]
[pin_not_connected]: Pin not connected
    ; error
    @(80.01 mm, 236.22 mm): Symbol U_DRAM5 Pin L9 [~{ALERT}, Open collector, Line]
[pin_not_connected]: Pin not connected
    ; error
    @(44.45 mm, 246.38 mm): Symbol U_DRAM5 Pin G8 [NC/C1/~{CS1}, Passive, Line]
[pin_not_connected]: Pin not connected
    ; error
    @(224.79 mm, 111.76 mm): Symbol U_DRAM2 Pin B9 [ZQ, Passive, Line]
[pin_not_connected]: Pin not connected
    ; error
    @(224.79 mm, 116.84 mm): Symbol U_DRAM2 Pin L9 [~{ALERT}, Open collector, Line]
[pin_not_connected]: Pin not connected
    ; error
    @(44.45 mm, 251.46 mm): Symbol U_DRAM5 Pin G2 [NC/C0/CKE1, Passive, Line]
[pin_not_connected]: Pin not connected
    ; error
    @(118.11 mm, 233.68 mm): Symbol U_DRAM6 Pin N3 [PAR, Input, Line]
[pin_not_driven]: Input pin not driven by any Output pins
    ; error
    @(118.11 mm, 233.68 mm): Symbol U_DRAM6 Pin N3 [PAR, Input, Line]
[pin_not_connected]: Pin not connected
    ; error
    @(44.45 mm, 264.16 mm): Symbol U_DRAM5 Pin G9 [TEN, Input, Line]
[pin_not_driven]: Input pin not driven by any Output pins
    ; error
    @(44.45 mm, 264.16 mm): Symbol U_DRAM5 Pin G9 [TEN, Input, Line]
[pin_not_connected]: Pin not connected
    ; error
    @(118.11 mm, 241.30 mm): Symbol U_DRAM6 Pin F2 [NC/C2/ODT1, Passive, Line]
[pin_not_connected]: Pin not connected
    ; error
    @(153.67 mm, 220.98 mm): Symbol U_DRAM6 Pin A3 [TDQS_c, Output, Line]
[pin_not_connected]: Pin not connected
    ; error
    @(118.11 mm, 246.38 mm): Symbol U_DRAM6 Pin G8 [NC/C1/~{CS1}, Passive, Line]
[pin_not_connected]: Pin not connected
    ; error
    @(153.67 mm, 231.14 mm): Symbol U_DRAM6 Pin B9 [ZQ, Passive, Line]
[pin_not_connected]: Pin not connected
    ; error
    @(118.11 mm, 251.46 mm): Symbol U_DRAM6 Pin G2 [NC/C0/CKE1, Passive, Line]
[pin_not_connected]: Pin not connected
    ; error
    @(153.67 mm, 236.22 mm): Symbol U_DRAM6 Pin L9 [~{ALERT}, Open collector, Line]
[pin_not_connected]: Pin not connected
    ; error
    @(259.08 mm, 114.30 mm): Symbol U_DRAM3 Pin N3 [PAR, Input, Line]
[pin_not_driven]: Input pin not driven by any Output pins
    ; error
    @(259.08 mm, 114.30 mm): Symbol U_DRAM3 Pin N3 [PAR, Input, Line]
[pin_not_connected]: Pin not connected
    ; error
    @(259.08 mm, 121.92 mm): Symbol U_DRAM3 Pin F2 [NC/C2/ODT1, Passive, Line]
[pin_not_connected]: Pin not connected
    ; error
    @(259.08 mm, 127.00 mm): Symbol U_DRAM3 Pin G8 [NC/C1/~{CS1}, Passive, Line]
[pin_not_connected]: Pin not connected
    ; error
    @(118.11 mm, 264.16 mm): Symbol U_DRAM6 Pin G9 [TEN, Input, Line]
[pin_not_driven]: Input pin not driven by any Output pins
    ; error
    @(118.11 mm, 264.16 mm): Symbol U_DRAM6 Pin G9 [TEN, Input, Line]
[pin_not_connected]: Pin not connected
    ; error
    @(259.08 mm, 132.08 mm): Symbol U_DRAM3 Pin G2 [NC/C0/CKE1, Passive, Line]
[pin_not_connected]: Pin not connected
    ; error
    @(259.08 mm, 144.78 mm): Symbol U_DRAM3 Pin G9 [TEN, Input, Line]
[pin_not_driven]: Input pin not driven by any Output pins
    ; error
    @(259.08 mm, 144.78 mm): Symbol U_DRAM3 Pin G9 [TEN, Input, Line]
[pin_not_connected]: Pin not connected
    ; error
    @(189.23 mm, 234.95 mm): Symbol U_DRAM7 Pin N3 [PAR, Input, Line]
[pin_not_driven]: Input pin not driven by any Output pins
    ; error
    @(189.23 mm, 234.95 mm): Symbol U_DRAM7 Pin N3 [PAR, Input, Line]
[pin_not_connected]: Pin not connected
    ; error
    @(189.23 mm, 242.57 mm): Symbol U_DRAM7 Pin F2 [NC/C2/ODT1, Passive, Line]
[pin_not_connected]: Pin not connected
    ; error
    @(294.64 mm, 101.60 mm): Symbol U_DRAM3 Pin A3 [TDQS_c, Output, Line]
[pin_not_connected]: Pin not connected
    ; error
    @(189.23 mm, 247.65 mm): Symbol U_DRAM7 Pin G8 [NC/C1/~{CS1}, Passive, Line]
[pin_not_connected]: Pin not connected
    ; error
    @(294.64 mm, 111.76 mm): Symbol U_DRAM3 Pin B9 [ZQ, Passive, Line]
[pin_not_connected]: Pin not connected
    ; error
    @(189.23 mm, 252.73 mm): Symbol U_DRAM7 Pin G2 [NC/C0/CKE1, Passive, Line]
[pin_not_connected]: Pin not connected
    ; error
    @(224.79 mm, 222.25 mm): Symbol U_DRAM7 Pin A3 [TDQS_c, Output, Line]
[pin_not_connected]: Pin not connected
    ; error
    @(294.64 mm, 116.84 mm): Symbol U_DRAM3 Pin L9 [~{ALERT}, Open collector, Line]
[pin_not_connected]: Pin not connected
    ; error
    @(224.79 mm, 232.41 mm): Symbol U_DRAM7 Pin B9 [ZQ, Passive, Line]
[pin_not_connected]: Pin not connected
    ; error
    @(189.23 mm, 265.43 mm): Symbol U_DRAM7 Pin G9 [TEN, Input, Line]
[pin_not_driven]: Input pin not driven by any Output pins
    ; error
    @(189.23 mm, 265.43 mm): Symbol U_DRAM7 Pin G9 [TEN, Input, Line]
[pin_not_connected]: Pin not connected
    ; error
    @(224.79 mm, 237.49 mm): Symbol U_DRAM7 Pin L9 [~{ALERT}, Open collector, Line]
[pin_not_connected]: Pin not connected
    ; error
    @(328.93 mm, 115.57 mm): Symbol U_DRAM4 Pin N3 [PAR, Input, Line]
[pin_not_driven]: Input pin not driven by any Output pins
    ; error
    @(328.93 mm, 115.57 mm): Symbol U_DRAM4 Pin N3 [PAR, Input, Line]
[pin_not_connected]: Pin not connected
    ; error
    @(328.93 mm, 123.19 mm): Symbol U_DRAM4 Pin F2 [NC/C2/ODT1, Passive, Line]
[pin_not_connected]: Pin not connected
    ; error
    @(328.93 mm, 128.27 mm): Symbol U_DRAM4 Pin G8 [NC/C1/~{CS1}, Passive, Line]
[pin_not_connected]: Pin not connected
    ; error
    @(328.93 mm, 133.35 mm): Symbol U_DRAM4 Pin G2 [NC/C0/CKE1, Passive, Line]
[pin_not_connected]: Pin not connected
    ; error
    @(328.93 mm, 146.05 mm): Symbol U_DRAM4 Pin G9 [TEN, Input, Line]
[pin_not_driven]: Input pin not driven by any Output pins
    ; error
    @(328.93 mm, 146.05 mm): Symbol U_DRAM4 Pin G9 [TEN, Input, Line]
[pin_not_connected]: Pin not connected
    ; error
    @(364.49 mm, 102.87 mm): Symbol U_DRAM4 Pin A3 [TDQS_c, Output, Line]
[pin_not_connected]: Pin not connected
    ; error
    @(364.49 mm, 113.03 mm): Symbol U_DRAM4 Pin B9 [ZQ, Passive, Line]
[pin_not_connected]: Pin not connected
    ; error
    @(364.49 mm, 118.11 mm): Symbol U_DRAM4 Pin L9 [~{ALERT}, Open collector, Line]

***** Sheet /data-byte-lanes-dqs/
[pin_not_connected]: Pin not connected
    ; error
    @(43.18 mm, 138.43 mm): Symbol J_HOST_DQ_A Pin 34 [Pin_34, Passive, Line]
[pin_not_connected]: Pin not connected
    ; error
    @(43.18 mm, 140.97 mm): Symbol J_HOST_DQ_A Pin 35 [Pin_35, Passive, Line]
[pin_not_connected]: Pin not connected
    ; error
    @(43.18 mm, 143.51 mm): Symbol J_HOST_DQ_A Pin 36 [Pin_36, Passive, Line]
[pin_not_connected]: Pin not connected
    ; error
    @(43.18 mm, 146.05 mm): Symbol J_HOST_DQ_A Pin 37 [Pin_37, Passive, Line]
[pin_not_connected]: Pin not connected
    ; error
    @(43.18 mm, 148.59 mm): Symbol J_HOST_DQ_A Pin 38 [Pin_38, Passive, Line]
[pin_not_connected]: Pin not connected
    ; error
    @(43.18 mm, 151.13 mm): Symbol J_HOST_DQ_A Pin 39 [Pin_39, Passive, Line]
[pin_not_connected]: Pin not connected
    ; error
    @(43.18 mm, 153.67 mm): Symbol J_HOST_DQ_A Pin 40 [Pin_40, Passive, Line]
[pin_not_connected]: Pin not connected
    ; error
    @(109.22 mm, 138.43 mm): Symbol J_HOST_DQ_B Pin 34 [Pin_34, Passive, Line]
[pin_not_connected]: Pin not connected
    ; error
    @(109.22 mm, 140.97 mm): Symbol J_HOST_DQ_B Pin 35 [Pin_35, Passive, Line]
[pin_not_connected]: Pin not connected
    ; error
    @(109.22 mm, 143.51 mm): Symbol J_HOST_DQ_B Pin 36 [Pin_36, Passive, Line]
[pin_not_connected]: Pin not connected
    ; error
    @(109.22 mm, 146.05 mm): Symbol J_HOST_DQ_B Pin 37 [Pin_37, Passive, Line]
[pin_not_connected]: Pin not connected
    ; error
    @(109.22 mm, 148.59 mm): Symbol J_HOST_DQ_B Pin 38 [Pin_38, Passive, Line]
[pin_not_connected]: Pin not connected
    ; error
    @(109.22 mm, 151.13 mm): Symbol J_HOST_DQ_B Pin 39 [Pin_39, Passive, Line]
[pin_not_connected]: Pin not connected
    ; error
    @(109.22 mm, 153.67 mm): Symbol J_HOST_DQ_B Pin 40 [Pin_40, Passive, Line]
[pin_not_connected]: Pin not connected
    ; error
    @(173.99 mm, 110.49 mm): Symbol J_HOST_DQ_C Pin 23 [Pin_23, Passive, Line]
[pin_not_connected]: Pin not connected
    ; error
    @(173.99 mm, 113.03 mm): Symbol J_HOST_DQ_C Pin 24 [Pin_24, Passive, Line]
[pin_not_connected]: Pin not connected
    ; error
    @(173.99 mm, 115.57 mm): Symbol J_HOST_DQ_C Pin 25 [Pin_25, Passive, Line]
[pin_not_connected]: Pin not connected
    ; error
    @(173.99 mm, 118.11 mm): Symbol J_HOST_DQ_C Pin 26 [Pin_26, Passive, Line]
[pin_not_connected]: Pin not connected
    ; error
    @(173.99 mm, 120.65 mm): Symbol J_HOST_DQ_C Pin 27 [Pin_27, Passive, Line]
[pin_not_connected]: Pin not connected
    ; error
    @(173.99 mm, 123.19 mm): Symbol J_HOST_DQ_C Pin 28 [Pin_28, Passive, Line]
[pin_not_connected]: Pin not connected
    ; error
    @(173.99 mm, 125.73 mm): Symbol J_HOST_DQ_C Pin 29 [Pin_29, Passive, Line]
[pin_not_connected]: Pin not connected
    ; error
    @(173.99 mm, 128.27 mm): Symbol J_HOST_DQ_C Pin 30 [Pin_30, Passive, Line]
[pin_not_connected]: Pin not connected
    ; error
    @(173.99 mm, 130.81 mm): Symbol J_HOST_DQ_C Pin 31 [Pin_31, Passive, Line]
[pin_not_connected]: Pin not connected
    ; error
    @(173.99 mm, 133.35 mm): Symbol J_HOST_DQ_C Pin 32 [Pin_32, Passive, Line]
[pin_not_connected]: Pin not connected
    ; error
    @(173.99 mm, 135.89 mm): Symbol J_HOST_DQ_C Pin 33 [Pin_33, Passive, Line]
[pin_not_connected]: Pin not connected
    ; error
    @(173.99 mm, 138.43 mm): Symbol J_HOST_DQ_C Pin 34 [Pin_34, Passive, Line]
[pin_not_connected]: Pin not connected
    ; error
    @(173.99 mm, 140.97 mm): Symbol J_HOST_DQ_C Pin 35 [Pin_35, Passive, Line]
[pin_not_connected]: Pin not connected
    ; error
    @(173.99 mm, 143.51 mm): Symbol J_HOST_DQ_C Pin 36 [Pin_36, Passive, Line]
[pin_not_connected]: Pin not connected
    ; error
    @(173.99 mm, 146.05 mm): Symbol J_HOST_DQ_C Pin 37 [Pin_37, Passive, Line]
[pin_not_connected]: Pin not connected
    ; error
    @(173.99 mm, 148.59 mm): Symbol J_HOST_DQ_C Pin 38 [Pin_38, Passive, Line]
[pin_not_connected]: Pin not connected
    ; error
    @(173.99 mm, 151.13 mm): Symbol J_HOST_DQ_C Pin 39 [Pin_39, Passive, Line]
[pin_not_connected]: Pin not connected
    ; error
    @(173.99 mm, 153.67 mm): Symbol J_HOST_DQ_C Pin 40 [Pin_40, Passive, Line]

***** Sheet /spd-and-configuration/
[pin_not_connected]: Pin not connected
    ; error
    @(81.28 mm, 109.22 mm): Symbol J_HOST_SPD Pin 8 [Pin_8, Passive, Line]
[power_pin_not_driven]: Input Power pin not driven by any Output Power pins
    ; error
    @(168.91 mm, 88.90 mm): Symbol U_SPD0 Pin 8 [VCC, Power input, Line]

***** Sheet /udimm-edge-interface/

 ** ERC messages: 131  Errors 131  Warnings 0

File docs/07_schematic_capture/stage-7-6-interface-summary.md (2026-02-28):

# Stage 7.6 — Block Interface Summary (OMI v1)

## Project
Open Memory Initiative (OMI) — OMI v1 DDR4 UDIMM

## Status
Draft (Ready for review)

## Purpose
Stage 7.6 provides a single, authoritative summary of how Stage 7 schematic blocks interface:
- which nets exist
- which sheet owns each net group
- cross-sheet naming/linking rules
- connector mapping authority (Stage 7.5 CSV)

This document is the "glue" between Stage 7 schematic capture and Stage 8 validation/bring-up planning.

---

## 1. Authoritative Sources

The following artifacts are authoritative:

- Net manifest (source of truth):
  - `docs/07_schematic_capture/stage-7-5-net-manifest.md`
- UDIMM edge pin map (source of truth for connector pins):
  - `design/connector/ddr4_udimm_288_pinmap.csv`
- Edge pin map reference:
  - `docs/07_schematic_capture/stage-7-5-edge-pinmap-final.md`

Stage 7.6 does not redefine nets. It summarizes and cross-references.

---

## 2. Sheet Ownership Model

OMI v1 uses "sheet ownership" to keep the design reviewable.

| Sheet | File | Owns |
|---|---|---|
| Power & PDN | (Stage 7.1 sheet) | power rails, sourcing model, DRAM power pins, VREF policy |
| Address/Command/Clock | `address-command-clock.kicad_sch` | CA/CLK/control connectivity (schematic topology = simplified star) |
| Data (DQ/DQS) | `data-byte-lanes-dqs.kicad_sch` | DQ/DQS lane naming + grouping; host-side anchors; endpoint labeling |
| SPD & Configuration | `spd-and-configuration.kicad_sch` | SPD EEPROM connectivity + assumptions (host pull-ups, WP tied low) |
| UDIMM Edge Interface | `udimm-edge-interface.kicad_sch` (or CSV-only) | connector mapping is authoritative via Stage 7.5 CSV |

Notes:
- Placeholder host connectors are allowed for labeling/anchoring during Stage 7.
- Pin-accurate connector mapping is controlled by the CSV (Stage 7.5).

---

## 3. Cross-Sheet Connectivity Rule

### Rule (OMI v1)
All cross-sheet connectivity uses **global net naming consistency**:
- If two pins on different sheets share the same net name, they are intended to be connected.
- Stage 7.5 CSV is the authority when mapping those nets to edge pins.

### Allowed labeling mechanisms
- Global labels for nets that must exist across sheets (preferred for v1 simplicity)
- No implicit connectivity by proximity
- No duplicate net naming conventions (avoid aliases)

---

## 4. Interface Groups

### 4.1 Power Rails
| Net | Description | Notes |
|-----|---|---|
| VDD | DDR4 core rail | host supplied |
| VDDQ | DDR4 I/O rail | host supplied |
| VPP | wordline boost rail | host supplied |
| VREF | reference rail | maps to VREFCA edge pins; host supplied (Option A) |
| VTT | termination rail | connector-level rail; host supplied |
| VDDSPD | SPD supply rail | connector-level rail; host supplied |
| GND | ground | maps from VSS/VSSQ in symbols |

Policy:
- Option A for VREF is locked (host-provided; DIMM distributes; no local generation).

---

### 4.2 CA / CLK / Control
Topology:
- **Simplified star representation in schematic**
- **Fly-by enforcement deferred to layout constraints** (Stage 8/Stage 10)

Nets (rank 0):
- CK_t, CK_c
- A0..A17 (density-dependent; some may be NC in the chosen module pin table)
- BA0, BA1, BG0, BG1
- ACT_n, CS0_n, CKE0, ODT0, RESET_n
- PARITY, ALERT_n (wired; feature enable is platform/config dependent)

Rank-1 connector pins:
- present in connector mapping, set to NC for single-rank OMI v1

---

### 4.3 DQ / DQS / DM/DBI (x64 non-ECC)
Naming rule (locked):
- Per-DRAM prefix prevents shorts between chips

For lane `i ∈ {0..7}`:
- Di_DQ0..Di_DQ7
- Di_DQS_t, Di_DQS_c
- Di_DM_DBI_n

Notes:
- ECC/CB lane pins are NC in OMI v1 (x64 non-ECC).
- Whether DBI is enabled is a host/controller configuration decision; OMI v1 does not assume DBI enabled.

---

### 4.4 SPD / Configuration
Nets:
- SPD_SCL, SPD_SDA
- SA0, SA1, SA2

Policies (locked for v1):
- Host provides SMBus pull-ups (no on-DIMM pull-ups assumed)
- SPD EEPROM WP is tied low (writes enabled)

---

## 5. Connector Mapping Authority

All mapping from nets → UDIMM edge pins is controlled by:

- `design/connector/ddr4_udimm_288_pinmap.csv`

Rules:
- `symbol` column matches the primary source pin table naming
- `omi_net` maps each pin to an OMI net, NC, or explicit tie-off
- CSV integrity checks must pass (288/288, no duplicates, no missing)

---

## 6. Review Checklist (Stage 7.6)

- [ ] Each net group (POWER, CA_CLK, DQ_DQS, SPD) has a defined owner sheet
- [ ] Cross-sheet naming policy is consistent and documented
- [ ] Connector mapping authority is unambiguous (CSV is the source of truth)
- [ ] Locked decisions referenced (VREF Option A; CA/CLK topology; per-lane DQ naming; SPD WP)
- [ ] Density-dependent pins (e.g., A17) are clearly documented as mapped per Table 4
- [ ] Rank-1 pins policy is explicit (NC for v1)

---

## 7. Next
➡ Stage 7.7 — Stage 7 Closure (final checklist + artifact index + handoff to Stage 8 validation)

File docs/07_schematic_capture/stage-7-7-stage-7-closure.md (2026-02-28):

# Stage 7.7 — Stage 7 Closure (OMI v1)

## Project
Open Memory Initiative (OMI) — OMI v1 DDR4 UDIMM

## Status
✅ Frozen (Final)

## Purpose
Stage 7 closure certifies that the OMI v1 schematic capture is:
- complete at the intended abstraction level
- internally consistent across sheets
- decision-traceable and reviewable
- ready to hand off to Stage 8 (Validation & Bring-Up Strategy)

---

## 1. Scope Completed in Stage 7

Stage 7 delivered schematic-level intent for:

- Power rails and sourcing model (host-supplied rails)
- CA/CLK/control connectivity (schematic topology representation locked)
- DQ/DQS/DM byte-lane connectivity with per-DRAM naming to prevent shorts
- SPD EEPROM connectivity and configuration assumptions (host pull-ups; WP tied low)
- UDIMM edge connector pin mapping based on a locked public pin table source

Stage 7 does NOT include:
- PCB layout or routing
- signal integrity / power integrity analysis
- length matching or topology enforcement in copper
- termination networks beyond what is required to express intent
- validation execution (Stage 8+)

---

## 2. Locked Decisions (Referenced)

- VREF strategy: **Option A (host-provided VREF)** — DIMM distributes; no local generation
- CA/CLK topology representation: **simplified star in schematic**; fly-by enforced at layout/constraints
- DQ/DQS naming: **per-DRAM lane prefix (D0..D7)** to prevent accidental shorts
- SPD policy: **host provides SMBus pull-ups; WP tied low** for OMI v1 development
- Pinout source: locked public reference (Micron Table 4 pin assignment table) used for CSV mapping

---

## 3. Final Artifact Index

### Stage 7.1 — Power & PDN (Final)
- Docs: `docs/07_schematic_capture/stage-7-1-power-final.md`
- PDF: `omi_v1_power_pdn_stage7_1_final.pdf` (see repo exports folder)

### Stage 7.2 — Address/Command/Clock (Final)
- Docs: `docs/07_schematic_capture/stage-7-2-ca-clk-final.md`
- PDF: `omi_v1_ca_clk_stage7_2_final.pdf`

### Stage 7.3 — Data (DQ/DQS) (Final)
- Docs: `docs/07_schematic_capture/stage-7-3-dq-dqs-final.md`
- PDFs:
  - `omi_v1_stage7_3_dq_dqs_host_final.pdf`
  - `omi_v1_stage7_3_dq_dqs_endpoints_final.pdf`

### Stage 7.4 — SPD & Configuration (Final)
- Docs: `docs/07_schematic_capture/stage-7-4-spd-final.md`
- PDF: `omi_v1_stage7_4_spd_final.pdf`

### Stage 7.5 — UDIMM Edge Pin Map (Final)
- Docs:
  - `docs/07_schematic_capture/stage-7-5-edge-pinmap-final.md`
  - `docs/07_schematic_capture/stage-7-5-pinout-source-decision.md`
  - `docs/07_schematic_capture/stage-7-5-net-manifest.md`
- CSV:
  - `design/connector/ddr4_udimm_288_pinmap.csv` (288/288 pins, no duplicates, no missing)

### Stage 7.6 — Interface Summary
- Docs: `docs/07_schematic_capture/stage-7-6-interface-summary.md`

---

## 4. Quality Gates (Pass/Fail)

✅ Passed:
- No duplicated physical components across sheets
- Net naming consistency maintained across blocks (POWER / CA_CLK / DQ_DQS / SPD)
- Edge pin map complete (288/288) with explicit NC/tie-off policy
- Stage decisions documented with rationale and locked status
- Artifacts exported for review (PDFs) and linked via docs/README navigation

---

## 5. Known Deferred Work (Explicit)

The following are intentionally deferred beyond Stage 7:
- Pin-accurate replacement of placeholder connectors in schematics (CSV remains authoritative)
- Termination network decisions (VTT usage in practice, ODT usage strategies)
- Detailed timing + SI constraints (fly-by enforcement, length matching)
- Platform-specific validation behavior (training, SPD programming workflow)
- Layout capture and manufacturing outputs (BOM, gerbers, assembly)

---

## 6. Handoff to Stage 8

Stage 7 is complete and frozen.

Next stage:
➡ **Stage 8 — Validation & Bring-Up Strategy**
- select validation platforms
- define bring-up procedure
- define what "working" means (logs/measurements)
- document failure modes and debug hooks

---

*End of Stage 7*

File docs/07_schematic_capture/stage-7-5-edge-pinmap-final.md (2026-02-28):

# Stage 7.5 — Edge Pin Map (Final Reference)

## Project
Open Memory Initiative (OMI) — OMI v1 DDR4 UDIMM

## Status
✅ Frozen (Final)

---

## 1. Primary Source

| Field | Value |
|---|---|
| Title | *8GB (x64, SR x8) 288-Pin DDR4 UDIMM* |
| Publisher | Micron Technology Inc. (Crucial brand) |
| Revision | CTL0226.fm — Rev. 12/04/15 |
| Table used  | **Table 4: Pin Assignments — 288-Pin DDR4 UDIMM Front/Back** |
| URL | <https://docs.rs-online.com/6ecf/0900766b81641250.pdf> |

Pin numbers and symbols are taken verbatim from Table 4.
No other pinout source was used. If a conflict arises, Table 4 wins.

---

## 2. Related Files

| Artifact | Path |
|---|---|
| Net manifest (source of truth) | `docs/07_schematic_capture/stage-7-5-net-manifest.md` |
| Pin map CSV | `design/connector/ddr4_udimm_288_pinmap.csv` |
| Pinout source decision | `docs/07_schematic_capture/stage-7-5-pinout-source-decision.md` |

---

## 3. CSV Column Definitions

| Column | Meaning |
|---|---|
| `pin` | Edge contact number (1–288) from Table 4 |
| `symbol`  | Exact symbol string from Table 4 |
| `omi_net` | OMI schematic net name (from net manifest); `NC` if unused |
| `group` | `POWER`, `CA_CLK`, `DQ_DQS`, `SPD`, `OTHER` |
| `notes` | Rationale, source annotation, or tie-off decision |

---

## 4. Net Mapping Rules Applied

### Power rails
| Table 4 symbol | `omi_net` |
|---|---|
| VDD | VDD |
| VSS | GND |
| VPP | VPP |
| VREFCA | VREF |
| VTT | VTT |
| VDDSPD | VDDSPD |

### Data bus (formula)
```
DQn        →  lane = n // 8 ; bit = n % 8  →  D{lane}_DQ{bit}
DQSx_t/c  →  D{x}_DQS_t / D{x}_DQS_c
DMx_n      →  D{x}_DM_DBI_n
```

### CA / CLK
- Multiplexed symbols (e.g., `RAS_n/A16`) — `omi_net` uses the address name (`A16`).
- `CK0_t` / `CK0_c` → `CK_t` / `CK_c` (rank 0 rename).

### SPD
| Symbol | `omi_net` |
|---|---|
| SCL | SPD_SCL |
| SDA | SPD_SDA |
| SA0 / SA1 / SA2 | SA0 / SA1 / SA2 |

---

## 5. Tie-off Policy

| Category | Rule |
|---|---|
| **NC (no connect)** | `omi_net = NC`; edge pin left unconnected. |
| **NF (not fitted)** | `omi_net = NC`; `notes = "NF in Table 4"`. Only pin 78 (`EVENT_n`) has this designation in Table 4. |
| **Rank-1 unused** | `omi_net = NC`; `notes = "single-rank v1: unused"`. Applies to: `CK1_t`, `CK1_c`, `CS1_n`, `CKE1`, `ODT1`. These edge pins are present in the connector but not driven. |
| **DM/DBI on x64** | DM/DBI pins exist on x64. Mapped to `D{x}_DM_DBI_n`. Whether DBI is enabled is a host/controller configuration choice; OMI v1 maps pins electrically but does not assume DBI enabled. |
| **ECC / CB lane** | Pins `CB0–CB7`, `DQS8_t/c`, `DM8_n/DBI8_n` — all `NC` on this x64 non-ECC module. |
| **A17 (density-dependent)** | `omi_net = NC`; `notes = "density-dependent; NC for 8Gb-class devices"`. A17 is only used for ≥16Gb density DRAMs. Pin 230 is NC in this module's Table 4. Net manifest retains A17 as optional. |

---

## 6. Locked Policies (v1)

| Signal | Status | Policy |
|---|---|---|
| `ALERT_n` (pin 208) | **Routed** — `omi_net = ALERT_n` | Host pull-up assumed; no on-DIMM pull-up required by OMI v1. |
| `PARITY` (pin 222) | **Routed** — `omi_net = PARITY` | OMI v1 does not enable parity; signal wiring preserved for compatibility. |
| `VTT` (pins 77, 221) | **Routed** — `omi_net = VTT` | Rail supplied by host platform. OMI module does not generate VTT. |
| `WP` (SPD EEPROM) | **Not a connector pin** — tied to GND on EEPROM | Remains GND for v1 development. |

---

## 7. Coverage

| Group | Rows |
|---|---|
| POWER (VDD/VSS/VPP/VREF/VTT/VDDSPD) | 129 |
| DQ\_DQS (DQ0–63, DQS0–7, DM0–7) | 88 |
| CA\_CLK (address, bank, clk, control) | 35 |
| OTHER (NC/NF/ECC/CB/reserved) | 31 |
| SPD (SCL/SDA/SA0–SA2) | 5 |
| **Total connector pins** | **288** |

---

## 8. CSV Integrity Checks (required before Frozen)

| Check | Expected | Actual |
|---|---|---|
| `row_count` | 288 | **288** ✅ |
| `unique(pin)` | 288 | **288** ✅ |
| `pins covered` | {1..288} | **{1..288}** ✅ |
| No duplicate pins | 0 | **0** ✅ |

Integrity verified 2026-02-28. All 288 edge contacts mapped with no gaps or duplicates.

---

*End of Stage 7.5 edge pin map reference.*

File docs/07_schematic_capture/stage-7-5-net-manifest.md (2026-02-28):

# Stage 7.5 — Net Manifest (Source of Truth)

## Project
Open Memory Initiative (OMI) — OMI v1 DDR4 UDIMM

## Purpose
This manifest lists every named net defined across Stages 7.1–7.4.
It is the authoritative reference for edge-pin mapping in Stage 7.5.

---

## 1. Power Rails
*(Stages 7.1 + 7.4)*

| Net | Description |
|---|---|
| `VDD` | Core supply (1.2 V nominal, DDR4) |
| `VDDQ` | I/O supply (DDR4 interface I/O rail) |
| `VPP` | DRAM activating power supply (2.5 V) |
| `VREF` | Reference voltage (maps to VREFCA pins) |
| `VDDSPD` | SPD EEPROM supply (2.2–3.6 V, NOM — per primary source Table 4) |
| `VTT` | Termination rail (appears in Table 4; supplied by host) |
| `GND` | Ground |

---

## 2. CA / CLK Bus
*(Stage 7.2)*

| Net | Description |
|---|---|
| `CK_t` | Differential clock — true |
| `CK_c` | Differential clock — complement |
| `A0` | Address bit 0 |
| `A1` | Address bit 1 |
| `A2` | Address bit 2 |
| `A3` | Address bit 3 |
| `A4` | Address bit 4 |
| `A5` | Address bit 5 |
| `A6` | Address bit 6 |
| `A7` | Address bit 7 |
| `A8` | Address bit 8 |
| `A9` | Address bit 9 |
| `A10` | Address bit 10 |
| `A11` | Address bit 11 |
| `A12` | Address bit 12 |
| `A13` | Address bit 13 |
| `A14` | Address bit 14 |
| `A15` | Address bit 15 |
| `A16` | Address bit 16 |
| `A17` | Address bit 17 |
| `BA0` | Bank address 0 |
| `BA1` | Bank address 1 |
| `BG0` | Bank group 0 |
| `BG1` | Bank group 1 |
| `ACT_n` | Activate command (active low) |
| `CS0_n` | Chip select 0 (active low) |
| `CKE0` | Clock enable 0 |
| `ODT0` | On-die termination 0 |
| `RESET_n` | DRAM reset (active low) |
| `PAR` | Command/address parity input (optional/system-dependent) |
| `PARITY`  | Pin symbol in Table 4 for command/address parity (maps to `PAR` net) |
| `ALERT_n` | Alert output — CRC/parity error or other events (optional/system-dependent) |
| `EVENT_n` | Event output (listed as NF in Table 4; connector pin present, OMI v1 NC) |

---

## 3. DQ / DQS Bus
*(Stage 7.3)*

### Byte Lane 0 — D0
| Net | Description |
|---|---|
| `D0_DQ0` | Data bit 0 |
| `D0_DQ1` | Data bit 1 |
| `D0_DQ2` | Data bit 2 |
| `D0_DQ3` | Data bit 3 |
| `D0_DQ4` | Data bit 4 |
| `D0_DQ5` | Data bit 5 |
| `D0_DQ6` | Data bit 6 |
| `D0_DQ7` | Data bit 7 |
| `D0_DQS_t` | Data strobe — true |
| `D0_DQS_c` | Data strobe — complement |
| `D0_DM_DBI_n` | Data mask / data bus inversion |

### Byte Lane 1 — D1
| Net | Description |
|---|---|
| `D1_DQ0`–`D1_DQ7` | Data bits 0–7 |
| `D1_DQS_t` | Data strobe — true |
| `D1_DQS_c` | Data strobe — complement |
| `D1_DM_DBI_n` | Data mask / data bus inversion |

### Byte Lane 2 — D2
| Net | Description |
|---|---|
| `D2_DQ0`–`D2_DQ7` | Data bits 0–7 |
| `D2_DQS_t` | Data strobe — true |
| `D2_DQS_c` | Data strobe — complement |
| `D2_DM_DBI_n` | Data mask / data bus inversion |

### Byte Lane 3 — D3
| Net | Description |
|---|---|
| `D3_DQ0`–`D3_DQ7` | Data bits 0–7 |
| `D3_DQS_t` | Data strobe — true |
| `D3_DQS_c` | Data strobe — complement |
| `D3_DM_DBI_n` | Data mask / data bus inversion |

### Byte Lane 4 — D4
| Net | Description |
|---|---|
| `D4_DQ0`–`D4_DQ7` | Data bits 0–7 |
| `D4_DQS_t` | Data strobe — true |
| `D4_DQS_c` | Data strobe — complement |
| `D4_DM_DBI_n` | Data mask / data bus inversion |

### Byte Lane 5 — D5
| Net | Description |
|---|---|
| `D5_DQ0`–`D5_DQ7` | Data bits 0–7 |
| `D5_DQS_t` | Data strobe — true |
| `D5_DQS_c` | Data strobe — complement |
| `D5_DM_DBI_n` | Data mask / data bus inversion |

### Byte Lane 6 — D6
| Net | Description |
|---|---|
| `D6_DQ0`–`D6_DQ7` | Data bits 0–7 |
| `D6_DQS_t` | Data strobe — true |
| `D6_DQS_c` | Data strobe — complement |
| `D6_DM_DBI_n` | Data mask / data bus inversion |

### Byte Lane 7 — D7
| Net | Description |
|---|---|
| `D7_DQ0`–`D7_DQ7` | Data bits 0–7 |
| `D7_DQS_t` | Data strobe — true |
| `D7_DQS_c` | Data strobe — complement |
| `D7_DM_DBI_n` | Data mask / data bus inversion |

---

## 4. SPD / Configuration Bus
*(Stage 7.4)*

| Net | Description |
|---|---|
| `SPD_SCL` | SMBus/I²C clock (pull-ups on host side) |
| `SPD_SDA` | SMBus/I²C data (pull-ups on host side) |
| `SA0` | SPD address strap 0 (host-controlled) |
| `SA1` | SPD address strap 1 (host-controlled) |
| `SA2` | SPD address strap 2 (host-controlled) |

> **Note:** `WP` is tied to `GND` (writes enabled for OMI v1). No dedicated WP net is needed.

---

## 5. Connector-Level Nets — Present on Edge, Unused in OMI v1

These signals exist in the DDR4 UDIMM pin table and must be mapped at the edge connector (as NC or tied per spec). They are not driven in OMI v1's single-rank design.

| Net | Description |
|---|---|
| `CK1_t`  | Differential clock true — rank 1 (unused in v1) |
| `CK1_c`  | Differential clock complement — rank 1 (unused in v1) |
| `CKE1` | Clock enable — rank 1 (unused in v1) |
| `ODT1` | On-die termination — rank 1 (unused in v1) |
| `CS1_n`  | Chip select — rank 1 (unused in v1) |

---

## Summary Count

| Group | Net Count |
|---|---|
| Power rails | 7 (incl. `VTT`) |
| CA / CLK bus | 33 (incl. `PAR`, `PARITY`, `ALERT_n`, `EVENT_n`)  |
| DQ / DQS bus | 88 (11 × 8 lanes) |
| SPD bus | 5 |
| Connector-present / unused | 5 (incl. `CK1_t`, `CK1_c`) |
| **Total** | **138** |

---

*This manifest is the input to Stage 7.5 edge-pin mapping.*

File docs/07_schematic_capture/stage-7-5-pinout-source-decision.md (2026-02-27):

# Stage 7.5 — Pinout Source Decision (UDIMM Edge Mapping)

## Status
Locked

## Date
2026-02-27

## Primary Source (Authoritative pin assignments)
- Title: **8GB (x64, SR x8) 288-Pin DDR4 UDIMM** (Micron Technology Inc.)
- Revision: CTL0226.fm — Rev. 12/04/15
- Why this source: Contains **Table 4: Pin Assignments** for **288-Pin DDR4 UDIMM Front/Back**, used as the authoritative mapping table.

Primary PDF:
https://docs.rs-online.com/6ecf/0900766b81641250.pdf

## What is authoritative from the Primary Source
- Edge contact pin numbers and their **Pin Symbol** naming (Table 4).
- Presence of connector-level rails/signals such as **VTT**, **VDDSPD**, **EVENT_n**, **PARITY**, **ALERT_n**, etc., as listed in Table 4.

## Notes (mechanical reference)
The primary source references the UDIMM outline **MO-309** (Figure 1), and is used as the public mechanical compatibility anchor for OMI v1.

## Conflict Policy
- If a pin symbol name differs from OMI internal net naming:
  - **Pin map CSV uses the Primary Source symbol name**
  - `omi_net` field maps to the closest OMI net (no silent renaming)
- If additional connector-level pins exist but OMI v1 does not use them:
  - They are still mapped in CSV as `NC` or explicit tie-off (with notes).

Why this doc matters: it prevents "random pinout images" or mixed sources from creeping in later.

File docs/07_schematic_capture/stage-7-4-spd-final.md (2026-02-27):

# Stage 7.4 — SPD & Configuration (Final)

## Project
Open Memory Initiative (OMI) — OMI v1 DDR4 UDIMM

## Status
✅ Frozen (Final)

## Scope
This stage defines SPD EEPROM connectivity for OMI v1:
- SPD EEPROM power
- SMBus/I²C bus signals (SCL/SDA)
- Address strap pins (SA0/SA1/SA2)
- Write-protect behavior

This stage does NOT include:
- Temperature sensor / TS-on-DIMM device
- Pin-accurate UDIMM edge connector mapping
- Any firmware/SPD content programming workflow

---

## Nets (Locked)
- `VDDSPD`, `GND`
- `SPD_SCL`, `SPD_SDA`
- `SA0`, `SA1`, `SA2`

---

## Components
- `J_HOST_SPD` — host SMBus/SPD placeholder connector (architectural anchor)
- `U_SPD0` — DDR4 SPD EEPROM symbol (I²C)

---

## Connectivity (Final)
- `U_SPD0.VCC` → `VDDSPD`
- `U_SPD0.VSS` → `GND`
- `U_SPD0.SCL` → `SPD_SCL`
- `U_SPD0.SDA` → `SPD_SDA`
- `U_SPD0.A0/A1/A2` → `SA0/SA1/SA2`

### Write Protect (Decision Locked)
- `U_SPD0.WP` → `GND` (writes enabled)

Rationale:
- OMI v1 prioritizes learning, reproducibility, and bring-up friendliness.
- Hardware write-protect is deferred to future revisions if needed.

---

## System Assumptions (Explicit)
- SMBus pull-ups for `SPD_SCL` and `SPD_SDA` are provided by the host platform.
- `SA0/SA1/SA2` are slot/address straps controlled host-side.

---

## Verification
- Net highlight confirms correct endpoint connectivity.
- ERC: no duplicate references; SPD power and bus nets resolve cleanly.

---

## Artifact
- `omi_v1_stage7_4_spd_final.pdf`

---

## Next
➡ Stage 7.5 — Pin-accurate connector mapping (UDIMM edge interface) and mechanical integration, then Stage 7 closure.

*End of Stage 7.4*

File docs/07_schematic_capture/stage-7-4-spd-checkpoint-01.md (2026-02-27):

# Stage 7.4 — SPD & Configuration (Checkpoint 01)

## Status
Checkpoint (not final)

## Scope
Defines SPD EEPROM connectivity for OMI v1:
- SPD EEPROM power
- SMBus/I²C signals (SCL/SDA)
- Address strap pins (SA0/SA1/SA2)
- Write-protect behavior

No temperature sensor, no pin-accurate UDIMM mapping, and no firmware content are included.

---

## Implemented

### Nets
- `VDDSPD`, `GND`
- `SPD_SCL`, `SPD_SDA`
- `SA0`, `SA1`, `SA2`

### Components
- `J_HOST_SPD` — host SMBus/SPD placeholder connector
- `U_SPD0` — DDR4 SPD EEPROM symbol (I²C)

### Connections
- `U_SPD0.VCC` → `VDDSPD`
- `U_SPD0.VSS` → `GND`
- `U_SPD0.SCL` → `SPD_SCL`
- `U_SPD0.SDA` → `SPD_SDA`
- `U_SPD0.A0/A1/A2` → `SA0/SA1/SA2`
- `U_SPD0.WP` → `GND` (writes enabled for development)

### Assumptions
- SMBus pull-ups for `SPD_SCL`/`SPD_SDA` provided by host platform.
- SA pins are slot/address straps (host-side).

---

## Verification
- Net highlight confirms endpoint connectivity.
- ERC: no duplicate references; SPD power and bus nets resolve.

---

## Artifact
- `omi_v1_stage7_4_spd_checkpoint_01.pdf`

---

## Next
- Decide whether SPD write-protect should remain tied low for v1 final, or be strap-selectable.
- Optional: add thermal sensor (TSE2004-class) as a separate, explicitly-scoped v1.x enhancement.

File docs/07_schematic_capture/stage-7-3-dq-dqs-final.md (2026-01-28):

# Stage 7.3 — Data (DQ/DQS) Byte-Lanes (Final)

## Project
Open Memory Initiative (OMI) — OMI v1 DDR4 UDIMM

## Status
✅ Frozen (Final)

## Scope
Defines data-plane net naming and connectivity for:
- DQ[7:0]
- DQS differential strobe pair
- DM/DBI_n (DDR4 shared function pin)

This stage does NOT include:
- Termination networks
- SI/length matching
- ECC
- SPD/I²C
- Any routing/ordering constraints

---

## Topology Representation
**Simplified star** representation in schematic:
- Connectivity is declared via labels
- Physical routing/topology is enforced at layout/constraints stage

---

## Naming Convention (Locked)

Per-DRAM prefix is used to prevent accidental shorts between devices:

For DRAM index `i ∈ {0..7}`:

- `Di_DQ0` … `Di_DQ7`
- `Di_DQS_t`, `Di_DQS_c`
- `Di_DM_DBI_n`

Mapping intent:
- `D0_*` ↔ `U_DRAM0`
- `D1_*` ↔ `U_DRAM1`
- …
- `D7_*` ↔ `U_DRAM7`

---

## Implementation Summary

### Host-side anchoring
Host-side placeholder connectors are used only to anchor labels (not pin-accurate UDIMM mapping).

- One or more host placeholder connectors (e.g., `J_HOST_DQ`, or `J_HOST_DQ_A/B/C`) provide enough pins to anchor all nets.
- All data nets are implemented as **Global Labels** to allow cross-sheet visibility.

### DRAM endpoints
Each DRAM `U_DRAM0..U_DRAM7` has:
- `DQ0..DQ7` labeled with `Di_DQ0..Di_DQ7`
- `DQS_t/DQS_c` labeled with `Di_DQS_t/Di_DQS_c`
- DM/DBI pin labeled with `Di_DM_DBI_n`

No data signals are shared across DRAMs.

---

## Verification
- ERC: no duplicate references
- Collision checks performed on representative nets:
  - `D0_DQ0`, `D3_DQS_t`, `D7_DM_DBI_n`
  ensuring each net appears only on the correct host anchor and the corresponding DRAM

---

## Artifacts
- `omi_v1_stage7_3_dq_dqs_host_final.pdf`
- `omi_v1_stage7_3_dq_dqs_endpoints_final.pdf`

---

## Next
➡ Stage 7.4 — SPD & Configuration (I²C/SA) sheet setup and net naming (no firmware behavior assumptions yet)

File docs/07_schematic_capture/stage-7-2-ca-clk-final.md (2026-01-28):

# Stage 7.2 — Address / Command / Clock (Final)

## Project
Open Memory Initiative (OMI) — OMI v1 DDR4 UDIMM

## Status
✅ Frozen (Final)

## Topology (Locked)
**Simplified star representation in schematic.**  
JEDEC fly-by behavior is deferred to layout/SI constraints.

## Scope
This stage defines CA/CLK/control connectivity only:
- CK_t/CK_c
- A0..A17
- BA0/BA1, BG0/BG1
- ACT_n
- CS0_n
- CKE0
- ODT0
- RESET_n

No DQ/DQS, SPD, or termination networks are included here.

## Implementation Summary
- `address-command-clock.kicad_sch` created and populated
- Host CA/CLK source represented by placeholder connector `J_HOST` (Conn_01x40)
- DRAM devices U_DRAM0..U_DRAM7 present exactly once in the project (no duplicated components)
- CA/CLK nets are consistently named and replicated across all DRAMs
- Stage 7.1 remains rails/entry only; DRAM placement moved to avoid duplication

## Verification
- ERC: no duplicate references
- Representative hover checks: CK_t, RESET_n, A0 consistent across DRAMs
- Power nets preserved: VDD, VDDQ, VPP, VREF, GND

## Artifacts
- `omi_v1_ca_clk_stage7_2_final.pdf`

## Next
➡ Stage 7.3 — Data (DQ/DQS) sheet creation and net naming (no routing, no SI tuning)

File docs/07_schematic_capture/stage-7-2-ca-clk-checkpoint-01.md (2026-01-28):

# Stage 7.2 — CA/CLK Checkpoint 01

## Status
Checkpoint (not final)

## Completed
- Stage 7.2 topology decision locked: simplified star (schematic)
- Stage 7.2 sheet created: `address-command-clock.kicad_sch`
- Host placeholder `J_HOST` resized to `Conn_01x40` to anchor CA/CLK nets
- DRAM symbols moved off the Stage 7.1 power page to avoid duplicate components
- Stage 7.1 page now acts as rails/entry only (power-only intent preserved)
- CA/CLK net naming applied: CK_t/CK_c, RESET_n, CS0_n, CKE0, ACT_n, ODT0, BA0/BA1, BG0/BG1, A0..A17
- Power nets preserved after refactor: VDD, VDDQ, VPP, VREF, GND

## Verification
- ERC: no duplicate references (expected unconnected signal warnings remain)
- Spot-checked nets: VDD/VDDQ/VPP/VREF/GND and representative CA signals

## Next
- Ensure CA/CLK labels are replicated across U_DRAM0..U_DRAM7 (if not already)
- Freeze a "Stage 7.2 Final" after replication is complete
- Proceed to Stage 7.3 (Data DQ/DQS) only after Stage 7.2 is frozen

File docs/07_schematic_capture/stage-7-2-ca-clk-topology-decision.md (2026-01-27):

# Stage 7.2 — Address / Command / Clock Topology Decision

## Project
Open Memory Initiative (OMI) — OMI v1 DDR4 UDIMM

## Status
✅ Locked

## Date
2026-01-27

---

## Decision Summary

For **Stage 7.2 (Address / Command / Clock schematic capture)**, the CA/CLK topology is represented as a:

> **Simplified Star (Logical Point-to-Point) Topology**

This decision applies **only to the schematic representation**.

JEDEC fly-by behavior is **explicitly deferred** to later stages (layout and signal-integrity constraints).

---

## Scope of This Decision

This decision governs:
- How CA/CLK nets are **drawn and connected in the schematic**
- How signal intent is communicated at **Stage 7 (Schematic Capture)**

This decision does **not** govern:
- Physical routing order
- Trace length matching
- Termination placement
- Signal integrity optimization

Those are handled in later stages.

---

## Options Considered

### Option A — JEDEC Fly-By Topology (Schematic-Level)

**Description**  
CA/CLK signals are daisy-chained from DRAM to DRAM, with termination at the end of the chain.

**Advantages**
- Matches JEDEC physical routing recommendations
- Reflects production-grade DDR implementations

**Disadvantages**
- Introduces schematic-level ordering constraints prematurely
- Increases complexity for early-stage learning and review
- Couples schematic intent tightly to layout decisions
- Harder to reason about and maintain in an open, educational project

---

### Option B — Simplified Star / Logical Point-to-Point (Chosen)

**Description**  
Each CA/CLK signal is represented as a single net connecting:
- The host interface
- All DRAM devices

No daisy-chain ordering is implied in the schematic.

**Advantages**
- Clear and readable schematic intent
- Easier review and onboarding for new contributors
- Decouples schematic correctness from physical routing
- Preserves flexibility for enforcing fly-by later
- Common practice in early-stage and educational designs

**Disadvantages**
- Does not visually encode JEDEC fly-by behavior
- Requires later documentation to avoid misinterpretation

---

## Rationale for Selection

The Open Memory Initiative prioritizes:
- Learning clarity
- Architectural transparency
- Incremental complexity

At Stage 7:
- The schematic's role is to define **connectivity and intent**
- Physical topology is better enforced at:
  - Stage 8 — Validation & Review
  - Stage 10 — Layout & SI/PI Guidelines

Representing fly-by at the schematic level would:
- Increase cognitive load
- Obscure functional understanding
- Encourage cargo-cult implementation without context

Therefore, **Option B** is the correct choice for OMI v1.

---

## Explicit Constraint (Important)

> **This schematic representation does NOT imply star routing on the PCB.**

JEDEC fly-by requirements for CA/CLK signals **must be enforced during PCB layout and signal-integrity analysis**, regardless of schematic topology.

This requirement will be addressed in:
- Stage 8 — Validation & Bring-Up Strategy
- Stage 10 — Layout SI/PI Guidelines

---

## Implementation Guidance for Stage 7.2

- Each CA/CLK signal is drawn as a **single named net**
- The net connects to:
  - Host connector CA/CLK pin
  - Corresponding pins on all DRAM devices
- No daisy-chain wiring is drawn in the schematic
- No termination networks are placed at this stage

---

## Lock Statement

This decision is **locked** for OMI v1.

Any change to CA/CLK topology representation must:
- Open a new design decision record
- Clearly justify the educational and architectural impact

---

*End of decision document*

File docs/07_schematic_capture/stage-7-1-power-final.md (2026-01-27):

# Stage 7.1 — Power & PDN (Final)

## Project
Open Memory Initiative (OMI) — OMI v1 DDR4 UDIMM

## Status
✅ Frozen (Final)

## Scope
This document captures the **final, reviewed state** of Stage 7.1 within Stage 7 (Schematic Capture).

Stage 7.1 focuses **exclusively** on:
- Power rails
- Power sourcing
- DRAM power consumption
- Reference voltage (VREF) strategy

No signal connectivity is included at this stage.

---

## Architectural Decisions (Locked)

### Memory Type
- DDR4
- UDIMM
- x8 DRAM devices
- Single-rank baseline assumption

### VREF Strategy
- **Option A — Host-provided VREF**
  - VREF is supplied by the host platform via the UDIMM connector
  - The DIMM does not generate VREF locally
  - The DIMM distributes VREF to DRAM devices
  - No resistor dividers, buffers, or regulators are present at this stage

This decision is locked for OMI v1.

---

## Power Rails Defined

The following global power nets are declared:

- `VDD`   — DRAM core supply
- `VDDQ`  — DRAM I/O supply
- `VPP`   — DRAM wordline boost supply
- `VREF`  — Reference voltage (host-provided)
- `GND`   — Common ground (VSS / VSSQ)

No voltage values are encoded in net names.

---

## Host Power Entry

- A placeholder connector (`UDIMM_HOST_POWER`) represents power sourced from the host motherboard.
- The connector provides:
  - `VDD`
  - `VDDQ`
  - `VPP`
  - `VREF`
  - `GND`

This connector is **architectural**, not pin-accurate, and will be refined later.

---

## DRAM Devices

### Devices Placed
Eight DDR4 x8 DRAM devices are instantiated:

```
U_DRAM0
U_DRAM1
U_DRAM2
U_DRAM3
U_DRAM4
U_DRAM5
U_DRAM6
U_DRAM7
```

### Connections (Power Only)

For **all DRAM devices**, the following connections are made:

- `VDD`     → `VDD`
- `VDDQ`    → `VDDQ`
- `VPP`     → `VPP`
- All `VSS` / `VSSQ` pins → `GND`
- `VREFCA`  → `VREF`

No other pins are connected.

---

## Explicit Exclusions

The following are **intentionally not included** in Stage 7.1:

- Address / Command / Clock connectivity
- Data (DQ/DQS) connectivity
- SPD / I²C connectivity
- Decoupling capacitors
- Bulk capacitance
- Power sequencing logic
- Voltage regulators
- Layout or routing considerations

All of the above are deferred to later stages.

---

## Verification

- Net hover test confirms all DRAM power pins share common rails
- No unintended local nets exist
- ERC warnings are limited to expected unconnected signal pins

---

## Artifacts

- **Schematic PDF**  
  `design/power/exports/omi_v1_power_pdn_stage7_1_final.pdf`

---

## Completion Statement

Stage 7.1 is complete and frozen.

All DRAM devices are powered consistently, reference voltage strategy is locked, and no functional signal connectivity has begun.

The project may now safely proceed to:

➡ **Stage 7.2 — Address / Command / Clock Schematic Page**

---

*End of Stage 7.1*

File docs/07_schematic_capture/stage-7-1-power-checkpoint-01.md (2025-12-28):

# Stage 7.1 — Power & PDN Checkpoint 01 (OMI v1)

## Status
Frozen (Checkpoint)

## Date
2025-12-29

## Scope
This checkpoint captures the current Stage 7.1 state for the **Power & PDN** schematic page only.

---

## What is included

- Power rails declared: `VDD`, `VDDQ`, `VPP`, `VREF`, `GND`
- Host power entry represented via connector placeholder (`UDIMM_HOST_POWER`)
- `U_DRAM0` placed as a template DRAM device symbol (DDR4 x8)
- `U_DRAM0` connections:
  - `VDD` connected to `VDD`
  - `VDDQ` connected to `VDDQ`
  - `VPP` connected to `VPP`
  - All `VSS*` pins connected to `GND`
  - `VREFCA` connected to `VREF`

No other pins on `U_DRAM0` are connected.

---

## VREF Strategy (Locked)

- **Option A (Host-provided VREF)** is in effect:
  - VREF is supplied by the host platform via the UDIMM connector
  - The DIMM does not generate VREF locally
  - Only distribution and local decoupling are permitted (decoupling not yet implemented)

Reference: `docs/07_schematic_capture/stage-7-1-vref-decision.md`

---

## What is explicitly NOT included

- No CA / address / command / clock connectivity
- No DQ / DQS / data-lane connectivity
- No SPD / I²C connectivity
- No decoupling capacitor selection or placement decisions
- No regulators or rail generation circuits
- No layout or routing considerations

---

## Artifact

- Power page PDF export (recommended location):
  - `design/power/exports/omi_v1_power_pdn_stage7_1_checkpoint.pdf`

---

## Next planned step (not executed)

- Replicate DRAM device power pins for all devices (power-only), OR
- Proceed to decoupling intent representation after confirming replication approach

---

*End of checkpoint*

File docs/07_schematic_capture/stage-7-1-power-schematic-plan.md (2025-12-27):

# Stage 7.1 — Power Schematic Plan (OMI v1 DDR4 UDIMM)

## Status
Draft

## Purpose
Define the **exact power-rail intent** for the Stage 7 schematic capture, so the Power & PDN page can be implemented without introducing new architectural assumptions.

This plan is **pre-schematic**: it specifies *what must be shown* and *what must be true*, not part numbers or capacitor values.

---

## Inputs (Locked Constraints)
- Technology: DDR4
- Form Factor: UDIMM
- Organization: 8 GB, 1R, x8, non-ECC
- Stage 6.1 Power Delivery assumptions are authoritative
- JEDEC-aligned, conservative behavior only

---

## 1. Rail Inventory (Must Appear on the Power Page)

The Power schematic page MUST explicitly include and name the following rails:

### Primary Rails
- **VDD (1.20 V nominal)** — DRAM core/array power  
- **VDDQ (1.20 V nominal)** — DRAM I/O power (DQ/DQS/CA interfaces)  
- **VPP (2.50 V nominal)** — wordline boost supply  
- **GND** — return reference for all rails and signals

### Reference Rails
- **VREF** — reference for input comparators  
  - Nominal assumption: approximately 0.5 × VDDQ  
  - Must be treated as noise-sensitive and locally stabilized

Notes:
- Exact tolerances are JEDEC-defined and referenced by DDR4 public specs.
- Any additional "helper" rails are out of scope unless required by public DDR4 UDIMM behavior.

---

## 2. Sourcing Model (What the Host Provides vs What the DIMM Does)

### Host-Supplied (via UDIMM edge connector)
For OMI v1, the default assumption is that the host platform supplies:
- VDD
- VDDQ
- VPP
- GND

### VREF Handling
VREF must be explicitly represented.
The schematic must state one of the following (choose during schematic capture and document it clearly on the page notes):
- **Option A:** VREF is provided by the host platform and distributed on-DIMM with local decoupling  
- **Option B:** VREF is derived on-DIMM (from VDDQ) and distributed with local decoupling

Regardless of option, VREF must be:
- explicitly named
- locally decoupled
- treated as a noise-sensitive reference, not a general-purpose rail

Non-assumptions:
- No on-DIMM regulation is assumed for VDD/VDDQ/VPP in OMI v1.
- No vendor-specific "power conditioning magic" is assumed.

---

## 3. Power Consumers (What Each Rail Powers)

The Power schematic must make clear the rail-to-consumer mapping:

- **VDD →** DRAM device VDD pins (all x8 devices)
- **VDDQ →** DRAM device VDDQ pins (all x8 devices), plus SPD/I²C pull-ups if they share this rail (must be explicit)
- **VPP →** DRAM device VPP pins (all x8 devices)
- **VREF →** DRAM device VREF-related pins (as applicable), distributed carefully
- **GND →** all device grounds and reference returns

The schematic must not leave any powered pins implied.

---

## 4. Decoupling & PDN Representation (Conceptual)

The Power page must show **decoupling intent**, without committing to final placement:

- Bulk decoupling presence per major rail (symbolic)
- Local decoupling presence at DRAM devices (symbolic)
- Clear separation of:
  - bulk (low-frequency stability)
  - local (high-frequency transients)

Rules:
- No aggressive or exotic PDN techniques in v1.
- Exact capacitor values and placement are deferred to Stage 10 (layout guidelines) unless required for schematic completeness.

---

## 5. Observability Requirements (Bring-Up Friendly)

The Power page must support the Stage 6.6 validation philosophy by ensuring rails are observable:

- Rails must be named consistently for probing and reporting:
  - VDD, VDDQ, VPP, VREF
- The plan assumes the builder can measure rails with basic equipment.
- If test points are used, they are allowed only if they do not introduce new features or mechanical conflicts.

(Implementation detail of testpoints can be deferred, but **observability must be considered now**.)

---

## 6. Page-Level Notes (Must Appear on the Power Page)

Add a small notes box on the Power page stating:

- OMI v1 is JEDEC-only, margin-first
- Host supplies VDD/VDDQ/VPP by default (UDIMM standard assumption)
- VREF is noise-sensitive and must be locally stabilized
- No on-DIMM regulators are assumed for v1

This prevents future readers from inferring hidden design intent.

---

## 7. Review Checklist (Power Page Gate)

Before moving to CA or data pages, reviewers must be able to answer:

- Can every rail be traced from connector to every consumer?
- Is VREF explicitly handled and not left vague?
- Are there any floating power pins?
- Is the sourcing model stated clearly (host vs on-DIMM)?
- Does anything on the page contradict Stage 6.1?

If any answer is "unclear," the power page is not review-clean.

---

## 8. Completion Criteria (Stage 7.1 Done)

Stage 7.1 is complete when:

- The Power & PDN schematic page exists
- Rail names match this plan
- VREF option (A or B) is explicitly chosen and documented on-page
- The page passes one structured review
- The page is considered frozen before proceeding

---

*End of plan*

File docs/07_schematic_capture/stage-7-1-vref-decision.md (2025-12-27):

# Stage 7.1 — VREF Strategy Decision (OMI v1)

## Status
Locked

## Date
2025-12-27

## Scope
Applies to **OMI v1 DDR4 UDIMM** schematic capture and all downstream implementation stages.

---

## 1. Context

During Stage 7.1 (Power & PDN schematic preparation), a decision was required regarding **VREF sourcing strategy** for the DDR4 UDIMM.

VREF is a noise-sensitive reference voltage used by DRAM input comparators to determine logic thresholds for data, strobe, and command/address signals.  
It is **not a power rail**, but a reference used for signal interpretation.

Incorrect handling of VREF can lead to intermittent or non-deterministic memory failures.

---

## 2. Considered Options

### Option A — Host-Provided VREF
- VREF is generated by the host platform (motherboard or memory controller environment)
- VREF is supplied to the DIMM via the UDIMM edge connector
- The DIMM is responsible only for **distribution and local decoupling**

### Option B — DIMM-Generated VREF
- VREF is generated locally on the DIMM (typically derived from VDDQ)
- The DIMM assumes responsibility for reference generation quality and stability

Both options are valid in DDR4 systems and are permitted by JEDEC specifications.

---

## 3. Decision

### ✅ **Option A — Host-Provided VREF is selected for OMI v1**

This decision is **locked** for OMI v1.

---

## 4. Rationale

Option A was selected based on the following considerations:

- **Lower schematic and system complexity**
- **Fewer analog failure modes** in a first-generation design
- **Clearer debug and validation behavior** during bring-up
- **Better alignment with conservative, JEDEC-aligned UDIMM implementations**
- **Improved educational clarity** for an open, reference-oriented project

The goal of OMI v1 is correctness, reproducibility, and clarity rather than maximal autonomy or optimization.

---

## 5. Architectural Implications

With Option A selected:

- The DIMM **shall not** generate VREF locally
- No resistor dividers, buffers, or regulators may be used to create VREF on-DIMM
- VREF must be treated as:
  - noise-sensitive
  - locally decoupled
  - distributed carefully to DRAM devices
- VREF sourcing responsibility is explicitly assigned to the host platform

Any deviation from these constraints requires reopening this decision and revisiting Stage 6/7 assumptions.

---

## 6. Schematic Impact (Stage 7)

On the **Power & PDN schematic page**:

- VREF must appear as a named rail
- VREF must connect to the UDIMM edge connector
- Only local decoupling elements are permitted
- No VREF generation circuitry may appear

This document is the authoritative reference for VREF handling in Stage 7.

---

## 7. Forward Compatibility

Alternative VREF strategies (including DIMM-generated VREF) may be explored in future revisions (e.g., OMI v2), but are **explicitly out of scope** for OMI v1.

---

## 8. Decision Lock

This decision is considered **final** for OMI v1 unless explicitly reopened through a documented architectural change process.

---

*End of document*

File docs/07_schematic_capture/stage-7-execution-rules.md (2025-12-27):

# Stage 7 — Schematic Capture Execution Rules (OMI v1)

## Status
Locked for OMI v1

## Scope
Applies to **Stage 7 — Schematic Capture only**

## Authority
OMI Maintainers

---

## 1. Purpose

This document defines the **execution rules** for Stage 7 — Schematic Capture.

Its purpose is to:
- Prevent scope creep
- Eliminate ambiguity
- Enforce review discipline
- Ensure that schematic work is a **faithful implementation** of Stage 6

This document is **procedural**, not architectural.  
It does not introduce design decisions — it governs *how* decisions are implemented.

---

## 2. Preconditions (Hard Gate)

Stage 7 work may proceed **only if**:

- Stage 5 (Scope Locking) is complete
- Stage 6.1–6.7 (Technical Decomposition) is complete
- Stage 6 closure has been explicitly declared
- No open architectural questions remain

If any assumption is unclear, schematic work must stop and documentation must be updated **before continuing**.

---

## 3. Schematic Page Structure (Locked)

The schematic MUST be organized into the following pages, in this order:

1. **Power & PDN**
   - All power rails, references, grounding, decoupling intent
2. **Address / Command / Clock**
   - CA signals, CK/CK#, CKE, CS#, RESET#, ODT
3. **Data Byte-Lane — Template**
   - One complete x8 DRAM device
4. **Data Byte-Lane — Replication**
   - Replicated lanes only, no unique logic
5. **SPD & I²C**
   - SPD EEPROM, pull-ups, addressing
6. **Connector / Edge Interface**
   - UDIMM edge fingers, external connectivity
7. **Notes & References**
   - JEDEC notes, assumptions, cross-references

### Rules
- No page may mix unrelated concerns
- Power signals must not be defined on non-power pages
- Replicated pages must explicitly state that they are replicated
- New pages may not be added without review

---

## 4. Naming Conventions (Locked)

### 4.1 Power Nets

JEDEC-standard names must be used exactly:

- `VDD`
- `VDDQ`
- `VPP`
- `VREF`
- `GND`

Rules:
- No aliases or local variants without justification
- All power consumers must connect to one of these named rails
- No implied power connections

---

### 4.2 Address / Command / Clock Signals

Use JEDEC naming conventions:

- Address: `A[ ]`
- Bank: `BA[ ]`, `BG[ ]`
- Commands: `RAS#`, `CAS#`, `WE#`
- Clock: `CK`, `CK#`
- Control: `CS#`, `CKE`, `RESET#`, `ODT`

Rules:
- Active-low signals must include `#`
- No renaming for convenience
- All signals must be explicitly connected or explicitly unused

---

### 4.3 Data Byte-Lanes

Lane-based naming is mandatory:

- `DQ0[0..7]`, `DQS0`, `DQS0#`
- `DQ1[0..7]`, `DQS1`, `DQS1#`
- …
- `DM0`, `DM1`, etc., if applicable

Rules:
- No data signal may exist outside a byte-lane context
- All lanes must be logically equivalent
- Any asymmetry is a bug unless documented

---

### 4.4 Page Naming

- Page names reflect **function**, not author preference
- Replicated pages must clearly indicate replication
- Notes pages must not introduce new connectivity

---

## 5. Review Cadence (Locked)

Stage 7 uses **page-gated reviews**.

| Page | Review Required Before Proceeding |
|----|---|
| Power & PDN | **Yes (hard gate)** |
| Address / Command / Clock | Yes |
| Data Byte-Lane — Template | **Yes (hard gate)** |
| Data Byte-Lane — Replication | Spot-check |
| SPD & I²C | Yes |
| Connector / Edge Interface | Yes |
| Notes & References | Optional |

### Review Rules
- Downstream pages may not begin until upstream pages are approved
- Approval means:
  - No undocumented assumptions
  - No floating pins
  - Behavior explainable without oral context
- Approved pages are considered **frozen**

---

## 6. Change Management

Once a schematic page is approved:

- It is considered frozen
- Changes require:
  - A documented reason
  - Identification of impacted assumptions
  - Explicit reviewer acknowledgment

Silent fixes are not permitted.

---

## 7. Prohibited Behaviors

The following are explicitly prohibited during Stage 7:

- Adding features or options
- Changing topology
- Introducing "just in case" circuitry
- Relying on layout to resolve ambiguity
- Assuming controller or BIOS behavior without documentation

If a decision feels creative, Stage 7 has already been violated.

---

## 8. Completion Criteria for Stage 7

Stage 7 is considered complete only when:

- A full, reviewable schematic exists
- Every Stage 6 block is traceable in the schematic
- No undocumented assumptions remain
- At least one structured schematic review has passed
- The schematic is explicitly frozen

Only then may the project proceed to **Stage 8 — Validation & Bring-Up Execution**.

---

## 9. One-Sentence Anchor

> **Stage 7 execution exists to eliminate ambiguity, not to invent solutions.**

---

*End of document*

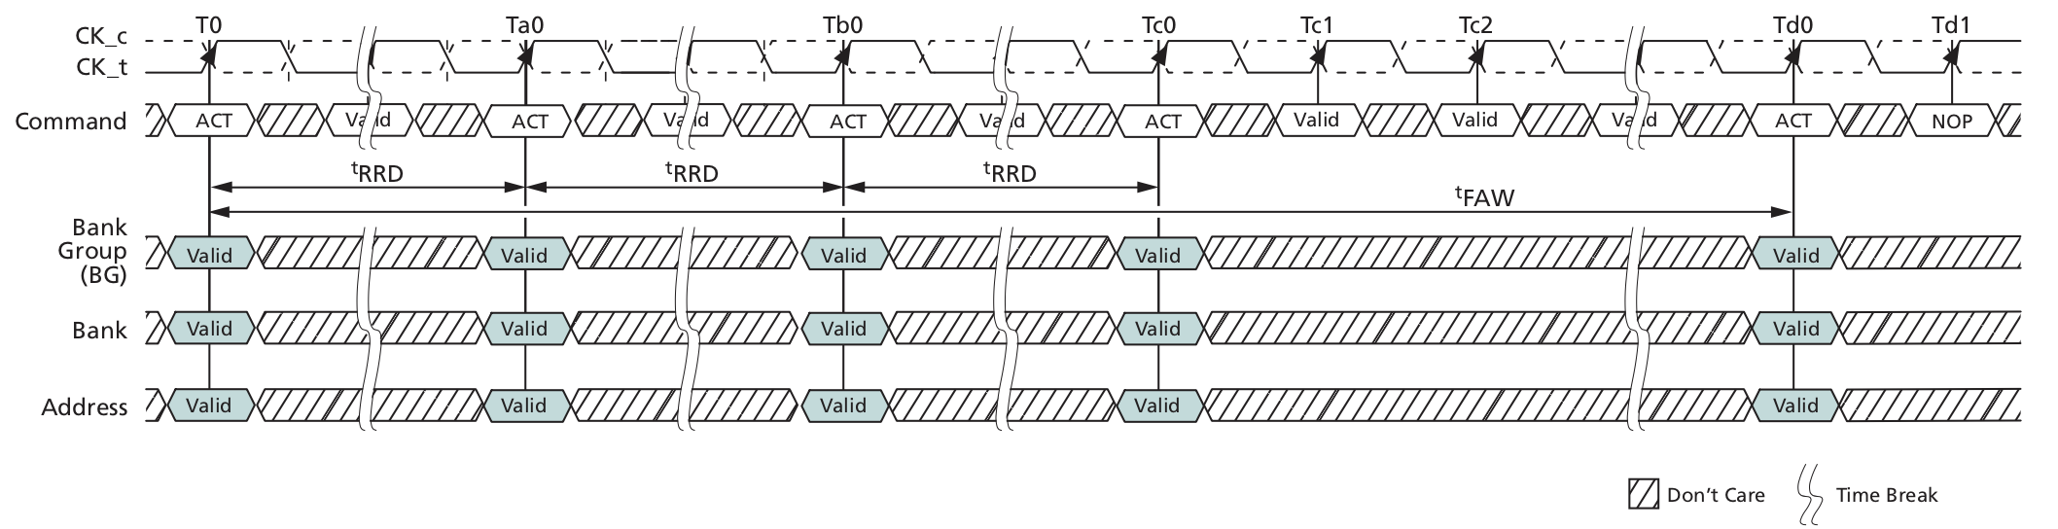
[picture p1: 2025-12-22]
docs/02_ddr_protocol/ddr4-timing-activate-tfaw.png

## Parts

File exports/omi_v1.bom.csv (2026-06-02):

Reference | Value | Footprint | Qty | DNP | Manufacturer | MPN | Procurement_Note
J1 | DDR4_UDIMM_288_Edge | omi:DDR4_UDIMM_288_Edge | 1 |  |  |  | PCB card edge (board copper feature) - NOT a purchased part; exclude from procurement
R1-R8 | 240 | Resistor_SMD:R_0402_1005Metric | 8
U_DRAM0-U_DRAM7 | H5AN8G8NAFR-UHC | Package_BGA:FBGA-78_7.5x11mm_Layout2x3x13_P0.8mm | 8
U_SPD0 | DDR4_SPD_EEPROM | Package_DFN_QFN:DFN-8-1EP_3x2mm_P0.5mm_EP1.3x1.5mm | 1

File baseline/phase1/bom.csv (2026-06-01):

Refs | Value | Footprint | Qty | DNP
J_HOST? | HOST_CA_CLK (placeholder) |  | 1
J_HOST_DQ_A? | HOST_DQ_DQS (placeholder) |  | 1
J_HOST_DQ_B? | HOST_DQ_DQS (placeholder) |  | 1
J_HOST_DQ_C? | HOST_DQ_DQS (placeholder) |  | 1
J_HOST_SPD? | HOST_SMBUS_SPD (placeholder) |  | 1
J_PWR? | UDIMM_HOST_POWER |  | 1
U_DRAM0 | H5AN8G8NAFR-UHC | Package_BGA:FBGA-78_7.5x11mm_Layout2x3x13_P0.8mm | 1
U_DRAM1 | H5AN8G8NAFR-UHC | Package_BGA:FBGA-78_7.5x11mm_Layout2x3x13_P0.8mm | 1
U_DRAM2 | H5AN8G8NAFR-UHC | Package_BGA:FBGA-78_7.5x11mm_Layout2x3x13_P0.8mm | 1
U_DRAM3 | H5AN8G8NAFR-UHC | Package_BGA:FBGA-78_7.5x11mm_Layout2x3x13_P0.8mm | 1
U_DRAM4 | H5AN8G8NAFR-UHC | Package_BGA:FBGA-78_7.5x11mm_Layout2x3x13_P0.8mm | 1
U_DRAM5 | H5AN8G8NAFR-UHC | Package_BGA:FBGA-78_7.5x11mm_Layout2x3x13_P0.8mm | 1
U_DRAM6 | H5AN8G8NAFR-UHC | Package_BGA:FBGA-78_7.5x11mm_Layout2x3x13_P0.8mm | 1
U_DRAM7 | H5AN8G8NAFR-UHC | Package_BGA:FBGA-78_7.5x11mm_Layout2x3x13_P0.8mm | 1
U_SPD0 | DDR4_SPD_EEPROM | Package_DFN_QFN:DFN-8-1EP_3x2mm_P0.5mm_EP1.3x1.5mm | 1

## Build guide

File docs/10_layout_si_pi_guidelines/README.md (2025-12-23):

# Stage 10 — Layout & SI/PI Guidelines

Stage 10 defines **layout, signal integrity (SI), and power integrity (PI) guidelines** for the OMI v1 DIMM design.

This stage does not provide routing recipes or numeric constraints.
It defines **physical design intent** so that layout decisions remain consistent with earlier architectural stages.

Stage 10 answers one question:
> How must the PCB be laid out so the design we already defined can actually work?

---

## Purpose of Stage 10

Stage 10 exists to:

- Translate architectural intent into physical behavior expectations
- Prevent layout from silently redefining the design
- Make SI/PI review possible before fabrication
- Ensure margin preservation across manufacturing and environment

Layout is not where architecture is decided.
Layout is where architecture either survives—or dies quietly.

---

## Scope and Non-Goals

### In Scope

- Routing intent
- Reference plane strategy
- Signal return behavior
- Crosstalk control philosophy
- Power distribution intent
- Decoupling placement philosophy
- Review criteria for SI/PI readiness

### Explicitly Out of Scope

- Numeric impedance targets
- Trace width / spacing values
- Stack-up specification
- Vendor-specific layout rules
- Simulation results

Those belong to execution and validation stages.

---

## Foundational Physical Assumptions

The following are assumed throughout Stage 10:

- Continuous reference planes exist
- Controlled impedance routing is available
- PCB manufacturing is standard, not exotic
- Layout engineer has authority to adjust geometry within intent

If these assumptions are not met, the design is not eligible for implementation.

---

## Signal Integrity (SI) Guidelines

### 1. Reference Plane Continuity

All high-speed signals must:
- Have a continuous reference plane
- Avoid crossing plane splits
- Avoid reference transitions without return paths

Broken return paths are timing errors in disguise.

---

### 2. Data (DQ/DQS) Routing Intent

Each byte lane must be treated as:
- An independent timing domain
- A tightly coupled signal group

Guidelines:
- Keep DQ signals of a lane physically close
- Keep DQS adjacent to its DQ group
- Avoid stubs and branching
- Preserve point-to-point topology strictly

If a DQ signal branches, the lane is already broken.

---

### 3. Lane-to-Lane Isolation

Byte lanes must be:
- Physically separable
- Not interwoven unnecessarily
- Protected from aggressive coupling

Guidelines:
- Avoid long parallel runs between different lanes
- Avoid serpentine interleaving across lanes
- Preserve visual and physical separation

Lane isolation supports both SI and failure containment.

---

### 4. Address and Command Routing Intent

Address and command signals are:
- Shared
- Unidirectional
- Fly-by distributed

Guidelines:
- Preserve monotonic routing order
- Avoid star or tree replication
- Maintain consistent relative spacing

Predictability matters more than symmetry.

---

### 5. Clock Routing Intent

Clock signals are:
- Global
- Differential
- Timing-critical for the entire system

Guidelines:
- Keep differential pairs tightly coupled
- Match within-pair lengths
- Minimize exposure to aggressor signals
- Route clocks with priority over other signals

Clock integrity defines global margin.

---

### 6. Crosstalk Management Philosophy

Crosstalk is managed by:
- Spacing
- Reference planes
- Routing order
- Avoiding unnecessary parallelism

Guidelines:
- Do not rely on simulation alone to justify risky adjacency
- Treat DQS and clock as sensitive victims
- Treat wide, fast buses as aggressors

If two signals must be close, they must be friends.

---

## Power Integrity (PI) Guidelines

### 7. Power Plane Strategy

Each power rail must:
- Have a low-impedance distribution path
- Remain isolated from other rails
- Be referenced to a stable ground system

Planes are preferred over long traces for high-current rails.

---

### 8. Decoupling Placement Philosophy

Decoupling exists to:
- Shorten current loops
- Localize transient demand
- Prevent noise propagation

Guidelines:
- Place high-frequency decoupling close to consumers
- Place bulk decoupling to support regional stability
- Do not treat all decoupling as interchangeable

Decoupling placement is part of timing correctness.

---

### 9. Vref Treatment

Vref must be treated as:
- An analog reference
- A noise-sensitive node
- A non-power rail

Guidelines:
- Isolate from switching currents
- Avoid adjacency to aggressor signals
- Filter and stabilize aggressively

Vref noise directly reduces voltage margin.

---

### 10. VTT Treatment

VTT must be treated as:
- A dynamic termination rail
- Capable of sourcing and sinking current

Guidelines:
- Provide low-inductance paths
- Avoid sharing impedance with logic supplies
- Keep termination return paths short

Termination instability shows up as ringing, not obvious power failure.

---

## Ground and Return Path Guidelines

Ground is not a single thing.

Guidelines:
- Maintain continuous ground reference
- Avoid narrow necks in ground paths
- Ensure return paths exist for all high-speed signals
- Treat ground vias as signal integrity components

Poor ground design invalidates good routing.

---

## Layout Review Checklist (SI/PI)

Before layout is considered acceptable:

### Signal Integrity

- [ ] No high-speed signal crosses a plane split
- [ ] Byte lanes are isolated and intact
- [ ] DQS is adjacent to its DQ group
- [ ] Clock routing is clear and protected
- [ ] No unintended stubs exist

### Power Integrity

- [ ] All rails are clearly separated
- [ ] Decoupling intent is visible and rational
- [ ] Vref is isolated and quiet
- [ ] VTT paths are short and well-defined
- [ ] Ground reference is continuous

If any answer is "unclear," layout is not ready.

---

## Relationship to Validation (Stage 8)

Stage 10 guidelines are validated by:
- Visual inspection
- Constraint consistency
- Power and signal sanity review

They are prerequisites for:
- SI simulation
- PI analysis
- Fabrication readiness

Simulation without discipline is false confidence.

---

## Takeaway

Stage 10 ensures that:
- Physics respects architecture
- Layout does not invent new behavior
- Margins are preserved intentionally
- Failures are not mysterious

Good layout does not make a bad design work.
But bad layout will absolutely break a good one.

---

Next possible stages:
- Stage 11 — SI Simulation Framework
- Stage 11 — PI Analysis Framework
- Stage 11 — Fabrication & Bring-Up Checklist

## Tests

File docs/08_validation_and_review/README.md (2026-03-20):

# Stage 8 — Validation & Review Playbook (OMI v1)

Stage 8 defines **how OMI v1 is validated and reviewed** before, during, and after schematic and layout work.

Its purpose is to:

- Detect architectural violations early
- Prevent silent margin erosion
- Make failures explainable instead of mysterious
- Enable disciplined, repeatable review by multiple engineers

This stage validates *correctness*, not performance.

---

## Why Validation Comes Before Build Claims

Memory systems rarely fail because of one large mistake.
They fail because of **many small, individually "acceptable" violations**.

Stage 8 exists to ensure:

> **Every important rule has a place where it is checked — and produces artifacts.**

Validation without artifacts is opinion, not engineering.

(Testing/measurement contributions must include platform details, tools, procedures, and results incl. failures.)

---

## Validation Philosophy

OMI validation follows four principles:

1. **Structural correctness first**
2. **Timing margin preservation**
3. **Power integrity visibility**
4. **Failure must be explainable**

If a design fails and you cannot point to *which rule was violated*, validation failed.

---

## Validation Ladder (Evidence Levels)

Stage 8 is not a single event. Evidence accumulates in levels:

- **L0 — Artifact Integrity:** ERC sanity, pin map integrity (288/288), naming consistency
- **L1 — Bench Electrical:** continuity, rail presence/behavior, SPD bus read
- **L2 — Host Enumeration:** SPD read in a host, BIOS reports plausible config
- **L3 — Training + Boot:** training completes, OS boots and uses RAM
- **L4 — Stress + Soak:** long memory tests, repeatability, documented failures

---

## Layer 0 — Artifact Integrity Review (Hard Gate)

### Objective

Ensure artifacts are internally consistent and reviewable.

### Checklist

- [ ] Pin map CSV is complete (288/288), no duplicate pins, no missing pins
- [ ] Net manifest matches schematic net names (no aliases)
- [ ] Decisions are referenced where relevant (VREF Option A, CA/CLK schematic topology, DQ naming, SPD WP policy)
- [ ] If something is uncertain, it is stated explicitly

### Failure indicators

- Missing/duplicated pin numbers in CSV
- Hidden renames ("same net with different names")
- Undocumented tie-offs or "magic" assumptions

Hard stop until fixed.

---

## Layer 1 — Architecture Compliance Review

### Objective

Ensure no artifact violates Stage 5 architecture.

### Checklist

- [ ] **DQ naming is per-lane/per-DRAM (D0..D7)** and prevents shared DQ nets
- [ ] CA/CLK nets are shared across DRAMs (connectivity correct)
- [ ] Clocks are differential and unambiguous
- [ ] Rank boundaries and unused rank-1 connector pins are explicitly handled (NC + notes)
- [ ] No undocumented architectural behavior exists

### Failure indicators

- Shared DQ nets across multiple lanes/devices
- Cross-lane connections
- Local clock buffering / multiple clock domains (without justification)

Hard stop.

---

## Layer 2 — Schematic Structure Review

### Objective

Ensure schematics encode intent structurally, not implicitly.

### Checklist

- [ ] Lane boundaries are explicit (D0..D7 naming; no cross-lane ambiguity)
- [ ] DQS is adjacent/clearly associated with its DQ bundle (by naming and grouping)
- [ ] CA/CLK/control signals are not duplicated as separate drivers
- [ ] Power nets are explicit and not "hidden by assumption"
- [ ] Notes exist where the schematic uses abstraction (e.g., simplified star representation)

### Failure indicators

- Ambiguous or inconsistent net naming
- "We'll fix it in layout" used to justify unclear connectivity
- Hidden coupling paths not obvious in schematic

---

## Layer 3 — Constraint Adherence Review

### Objective

Ensure Stage 5 constraints survive implementation.

### Timing constraints (schematic-level intent)

- [ ] DQ within a lane is treated as a group (lane-based naming)
- [ ] DQS-to-DQ association is one-to-one per lane
- [ ] No artificial lane-to-lane matching constructs appear

### CA/CLK topology (important clarification)

- [ ] **Schematic may use simplified star representation**
- [ ] **Fly-by ordering is enforced at layout/constraints stage**, not by schematic wiring

### Power constraints

- [ ] VDD, VDDQ, VREF, VTT are never merged
- [ ] VREF is not used as a supply
- [ ] VTT is only used for termination-related functions (connector-level rail)

---

## Layer 4 — Power Integrity Review (Split)

### 4A — Schematic PI sanity

- [ ] Rails are defined and not merged
- [ ] VREF treated as noise-sensitive reference (not a "power rail")
- [ ] SPD supply is isolated from DRAM rails (VDDSPD exists and is mapped)

### 4B — Layout readiness gate (before layout begins)

- [ ] A decoupling plan exists per rail (rail-specific intent)
- [ ] Measurement points / debug hooks are planned (where feasible)

---

## Layer 5 — Failure Containment Review

### Objective

Ensure failures are localized and diagnosable.

### Checklist

- [ ] Byte-lane failures do not electrically affect other lanes
- [ ] SPD failures do not electrically affect DRAM operation
- [ ] Power rail instability is traceable to a domain
- [ ] No single-point failure silently breaks the entire system

---

## Validation Artifacts (Required)

Every validation pass produces:

- Completed checklist + pass/fail notes
- Annotated schematic screenshots (as needed)
- Explicit waivers (if any), with justification
- If testing/measurement is involved: platform details, tools, procedures, results incl failures

---

## Review Roles (Recommended)

- Architect reviewer (architecture compliance)
- Implementation reviewer (schematic clarity)
- Power/PI reviewer (rail correctness / PI readiness)

---

## Stage 8 Document Index

### Foundational Reference Documents

These define the validation framework — platform taxonomy, ladder levels, test categories, reporting format, and failure signatures.

| Document | Purpose |
|---|---|
| [08-1_validation_platforms.md](./08-1_validation_platforms.md) | Platform class taxonomy (Class A/B/C), minimum requirements, evidence capabilities |
| [08-2_bringup_ladder.md](./08-2_bringup_ladder.md) | Validation ladder (L0–L4) with pass/fail criteria and stop conditions |
| [08-3_test_matrix.md](./08-3_test_matrix.md) | Test categories (T1–T7), minimum durations, failure taxonomy |
| [08-4_reporting_template.md](./08-4_reporting_template.md) | Standardized validation report format, Run ID scheme, artifact naming |
| [08-5_failure_signatures.md](./08-5_failure_signatures.md) | Six failure signatures (FS-01 through FS-06) with symptom-to-cause mappings |

### Operational Documents

These operationalize the framework — specific test points, platform recommendations, step-by-step procedures, consolidated criteria, checklists, and closure definitions.

| Document | Purpose |
|---|---|
| [08_01_test_point_and_dft_plan.md](./08_01_test_point_and_dft_plan.md) | Test point locations, DFT philosophy, probe access requirements for layout |
| [08_02_validation_platform_strategy.md](./08_02_validation_platform_strategy.md) | Specific platform recommendations, cost estimates, phased strategy, risk register |
| [08_03_bringup_procedure.md](./08_03_bringup_procedure.md) | Step-by-step bring-up from bare PCB to OS boot |
| [08_04_success_criteria_and_failure_modes.md](./08_04_success_criteria_and_failure_modes.md) | Consolidated success criteria, failure catalog, diagnostic decision trees, honest unknowns |
| [08_05_review_checklists.md](./08_05_review_checklists.md) | Pre-fabrication (26 items) and post-fabrication (17 items) checklists, quick-report template |
| [08_06_stage8_closure_criteria.md](./08_06_stage8_closure_criteria.md) | Stage 8 exit criteria, what's not required, handoff to Stage 9 |

### Playbooks and Detailed Procedures

| Document | Purpose |
|---|---|
| [OMI Stage 8 L0 Playbook Development.md](<./OMI Stage 8 L0 Playbook Development.md>) | Comprehensive L0 playbook with 5 execution sessions and risk register |
| [OMI Stage 8 L1 Validation Guide.md](<./OMI Stage 8 L1 Validation Guide.md>) | Comprehensive L1 playbook with 3 bench sessions and equipment requirements |

### Supporting Artifacts

| Directory | Contents |
|---|---|
| [L0_artifact_integrity/](./L0_artifact_integrity/) | L0 naming rules, README |
| [L1_bench_electrical/](./L1_bench_electrical/) | L1 measurement procedures, probe sequence CSV, measurement log template |
| [scripts/](./scripts/) | Automated validation scripts (l0_runner.py, l1_runner.py, verify_pinmap.py, etc.) |
| [templates/](./templates/) | L0/L1 report templates, peer review checklists, PR templates |

---

## Next

Stage 8 closure criteria are defined in [08_06_stage8_closure_criteria.md](./08_06_stage8_closure_criteria.md). When all exit criteria are met:

- Stage 9 — Minimal Reference Schematic (Correctness-First)

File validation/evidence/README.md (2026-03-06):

# Validation Evidence Directory

## Purpose

This directory stores evidence artifacts generated during L0 validation runs.
Each run of `l0_runner.py` produces output files here.

## Expected Contents After L0 Execution

| File | Generated By | Description |
|---|---|---|
| `pinmap_report.json` | `verify_pinmap.py` | Pin map verification results (288/288) |
| `naming_report.json` | `verify_naming.py` | Naming consistency audit results |
| `lane_matrix.csv` | `verify_naming.py` | Byte-lane-to-pin mapping matrix |
| `l0_summary.json` | `l0_runner.py` | Unified L0 summary with hashes |
| `l0_summary.md` | `l0_runner.py` | Human-readable L0 summary |

## Generating Evidence

From the repository root:

```bash
python docs/08_validation_and_review/scripts/l0_runner.py \
  --reference design/connector/ddr4_udimm_288_pinmap.csv \
  --output-dir validation/evidence
```

## Hash Verification

Every evidence file includes a SHA-256 hash in `l0_summary.json`.
To verify independently:

```bash
# Linux / macOS
sha256sum validation/evidence/*.json validation/evidence/*.csv

# Windows (PowerShell)
Get-FileHash validation/evidence/*.json,validation/evidence/*.csv -Algorithm SHA256
```

## Storage Convention

For formal L0 submissions, copy evidence into a run-specific directory:

```
validation/results/RUN-YYYYMMDD-LOCAL-L0-001/
```

See `docs/08_validation_and_review/08-4_reporting_template.md` for naming rules.

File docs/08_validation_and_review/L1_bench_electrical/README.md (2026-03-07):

# L1 — Bench Electrical

## Purpose

L1 is the first physical validation level in the OMI Validation Ladder.
It proves that the manufactured module has correct electrical connectivity
before any active host platform is used.

L1 validates three domains:

1. **Continuity** — all 288 edge connector pins reach their mapped nets
2. **Power Rail Isolation** — VDD, VPP, VREF, VDDSPD, VTT are isolated
3. **SPD Bus Integrity** — I2C bus can reach the SPD EEPROM

## Prerequisites

- **L0 must be PASSED** before starting L1.
- **Hardware:** manufactured OMI v1 DDR4 UDIMM prototype board.
- **Equipment:** DMM with continuity mode, bench power supply, oscilloscope
  or logic analyzer, DDR4 UDIMM test socket (Class C jig).
- **Software:** Python 3.8+ (for running validation scripts).

## Quick Start

```bash
# From the repository root:

# 1. Generate the probe sequence (what to measure and where)
python docs/08_validation_and_review/scripts/generate_probe_sequence.py \
  --reference design/connector/ddr4_udimm_288_pinmap.csv \
  --output validation/evidence/probe_sequence.csv

# 2. Generate a printable checklist for the bench
python docs/08_validation_and_review/scripts/generate_probe_sequence.py \
  --reference design/connector/ddr4_udimm_288_pinmap.csv \
  --format markdown \
  --output validation/evidence/probe_checklist.md

# 3. After completing measurements, validate your log
python docs/08_validation_and_review/scripts/validate_continuity_log.py \
  --reference design/connector/ddr4_udimm_288_pinmap.csv \
  --measurements path/to/your_measurement_log.csv

# 4. Run the full L1 suite with evidence generation
python docs/08_validation_and_review/scripts/l1_runner.py \
  --reference design/connector/ddr4_udimm_288_pinmap.csv \
  --measurements path/to/your_measurement_log.csv \
  --output-dir validation/evidence
```

## Directory Contents

| File | Purpose |
|---|---|
| `measurement_procedures.md` | Step-by-step bench procedures for all 3 sessions |
| `measurement_log_template.csv` | Blank CSV template for recording measurements |
| `probe_sequence_reference.csv` | Pre-generated probe sequence for reference |

## Related Files

| File | Location |
|---|---|
| L1 scripts | `docs/08_validation_and_review/scripts/` |
| Report templates | `docs/08_validation_and_review/templates/` |
| Canonical pin map CSV | `design/connector/ddr4_udimm_288_pinmap.csv` |
| Bringup ladder | `docs/08_validation_and_review/08-2_bringup_ladder.md` |
| Failure signatures | `docs/08_validation_and_review/08-5_failure_signatures.md` |

## L1 Pass/Fail Criteria

(From `08-2_bringup_ladder.md`)

### Pass
- All 288 edge contacts show continuity to their mapped net
- No shorts between adjacent pins (≥1 MΩ between non-connected nets)
- VDD, VDDQ, VPP, VREF, VTT, VDDSPD rails are isolated from each other
- GND contact resistance ≤1 Ω across all VSS pins

### Fail
- Any open circuit on a functional signal net (DQ, DQS, DM, CA, CLK, control)
- Any short between two distinct signal nets
- Rail-to-rail resistance <10 kΩ on rails that must be isolated

### Stop Condition
**Halt and open issue** if any short or open is detected on a functional net.
Document exact pin numbers and measured values.
Do not proceed to L2 until L1 is fully passed.

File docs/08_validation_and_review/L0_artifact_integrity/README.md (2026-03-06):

# L0 — Artifact Integrity

## Purpose

L0 is the foundational level of the OMI Validation Ladder.
It proves that the frozen Stage 7 schematic artifacts are internally consistent
before any physical manufacturing or bench validation occurs.

L0 demands machine-verifiable evidence across three pillars:

1. **ERC Sanity** — zero unintended electrical rule violations
2. **Pin Map Integrity (288/288)** — all edge connector pins correctly mapped
3. **Naming Consistency** — byte-lane isolation and per-device net naming verified

## Quick Start

**Prerequisites:** Python 3.8+, access to the frozen pin map CSV.

```bash
# From the repository root:

# Run pin map verification
python docs/08_validation_and_review/scripts/verify_pinmap.py \
  --reference design/connector/ddr4_udimm_288_pinmap.csv

# Run naming consistency audit
python docs/08_validation_and_review/scripts/verify_naming.py \
  --reference design/connector/ddr4_udimm_288_pinmap.csv

# Run the full L0 suite with evidence generation
python docs/08_validation_and_review/scripts/l0_runner.py \
  --reference design/connector/ddr4_udimm_288_pinmap.csv \
  --output-dir validation/evidence
```

## Directory Contents

| File | Purpose |
|---|---|
| `naming_rules.md` | Regex patterns and naming conventions for all net groups |

## Related Files

| File | Location |
|---|---|
| Verification scripts | `docs/08_validation_and_review/scripts/` |
| Report templates | `docs/08_validation_and_review/templates/` |
| Canonical pin map CSV | `design/connector/ddr4_udimm_288_pinmap.csv` |
| Net manifest | `docs/07_schematic_capture/stage-7-5-net-manifest.md` |
| Full L0 playbook | `docs/08_validation_and_review/OMI Stage 8 L0 Playbook Development.md` |
| Bringup ladder | `docs/08_validation_and_review/08-2_bringup_ladder.md` |

## "Credible L0" Standard

L0 is only achieved when the evidence package includes:

1. The specific Git commit SHA of the frozen schematic
2. The SHA-256 hash of the input CSV
3. The exact script used and its version
4. The raw output log

An independent engineer must be able to reproduce the exact same results
by checking out the same commit and running the same scripts.

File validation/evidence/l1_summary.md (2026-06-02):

# OMI L1 Bench Electrical — FRAMEWORK DRY-RUN (NOT a bench measurement)

> ⚠️ **HONESTY NOTICE — read first.** This is **not** a record of a hardware test.
> No board was fabricated, populated, powered, or probed, and **no physical
> measurements were taken.** This file is the output of running the L1 *tooling*
> (`l1_runner.py`) over a **blank measurement template**
> (`measurement_log_template.csv`). The "PASS" lines below mean only that the
> **scripts executed and the template was structurally well-formed** — a
> framework/procedure dry-run, **not** bench validation.
>
> For genuine, reproducible electrical evidence at the schematic stage, see the
> ERC result [`../../exports/erc.json`](../../exports/erc.json) (0 violations) and
> the L0 artifact-integrity summary [`l0_summary.md`](./l0_summary.md). Physical
> L1–L4 bench validation **awaits a fabricated board** and has not been performed.

**Framework status:** scripts ran successfully over a blank template — no hardware, no measurements.

| Field | Value |
|---|---|
| Timestamp | 2026-03-07T10:36:56.426411+00:00 |
| Git Commit | `d7353012e0933e62ad5f45de10181e43ac5dd40b` |
| Reference CSV | `design\connector\ddr4_udimm_288_pinmap.csv` |
| CSV SHA-256 | `5b30e30d37293d0ea1f65ad08f4a162f285a102fb0955541aa9b5fee47714c14` |
| Measurements | `docs\08_validation_and_review\L1_bench_electrical\measurement_log_template.csv` **(BLANK TEMPLATE — no data)** |
| Meas SHA-256 | `27c1ccfd60e391d8bd8586f4636bdbeaaca30e0949e35d63af6fbd19a2213480` |

## Framework Checks (tooling only — not measurements)

The results below reflect that the **scripts ran** over the blank template — **not**
that any quantity was physically measured:

| Framework check | Result |
|---|---|
| Probe Sequence Generation (script produced a probe plan) | ran OK |
| Continuity Log Validation (template structurally complete: 288 rows/fields) | ran OK |

> `continuity_report.json` in this directory is likewise a **template-structure**
> check, not a continuity measurement: it confirms the blank log has the expected
> 288 rows and fields. Its per-rail "PASS" lines describe the *template*, not a
> probed board.

## Evidence Files

- `continuity_report.json` — SHA-256: `347bda448a1afd8ceec546b164ba2a5dc9b4d83804b8303a4c3e3bbee7fc9b3c`
- `l0_summary.json` — SHA-256: `bcc64a4899952cf0561c537b12aa71308e3c8749edb93b92880ef7e8120061e4`
- `l0_summary.md` — SHA-256: `94d4d103f7441b54b5f65bc81f2503e5350098aa0949a3d6ede62706d1b5e303`
- `lane_matrix.csv` — SHA-256: `455f3ea799b749e850407a4fcdac7d9d1a8c056b6708f5515906198dbbe395fe`
- `naming_report.json` — SHA-256: `8748380dbf069249ea4579e80e2f044fbd2a3486f395f21f137b79c4177fa44b`
- `pinmap_report.json` — SHA-256: `35dc90b159bc2032b1f7f1f16fa9335f78ea0efbd6a5a64439dd808c6e375546`
- `probe_checklist.md` — SHA-256: `0c7954406fe1bddce47dc0d0c9d827560e716d8e0e57b4b0383b456faf781428`
- `probe_sequence.csv` — SHA-256: `4ee4e8f6bc371c00a7c916ddaaa290a2a54437437af81c76dc857d48ab6530f8`
- `README.md` — SHA-256: `c454f21cdf7c802b4c8f39fe8a7491f29d3864959eaa939f35f06dadbf54ff18`

---

*Generated by l1_runner.py v1.0.0*

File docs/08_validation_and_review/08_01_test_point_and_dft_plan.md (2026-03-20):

# Stage 8.01 — Test Point & Design-for-Test Plan (OMI v1)

## Project
Open Memory Initiative (OMI) — OMI v1 DDR4 UDIMM

## Status
Draft

## Purpose
Define which nets require physical test points on the PCB layout, what measurements each enables, and what probe access geometry is needed. This document feeds directly into Stage 9/10 layout decisions — if test points are not planned now, there will be no room for probe access on the fabricated board.

> **Scope:** This plan covers OMI v1 first-article prototypes only. Production DFT, boundary scan, and automated test interfaces are explicitly out of scope.

---

## 1. DFT Philosophy for OMI v1

OMI v1 is a reference design, not a production module. The primary goal is **debug accessibility**, not signal integrity optimization or production testability.

**What this means in practice:**

- Test points may introduce trace stubs that degrade signal integrity at higher frequencies. This is an acceptable tradeoff for a DDR4-2400 reference design operating well within JEDEC timing margins.
- Test point pads consume PCB area that would otherwise be available for routing. This constrains layout but is necessary for first-article validation.
- Every domain boundary (power, clock, data, configuration) must have at least one observable point. An unobservable failure is an unexplainable failure, and unexplainable failures violate OMI's validation philosophy.

**Why this matters:**

Without test points, the only debug path for a non-functional module is to insert it into a host and interpret cryptic BIOS error codes. Test points allow direct measurement of power rails, clock quality, and signal presence — turning "it doesn't work" into "VDD is 0.8V instead of 1.2V" or "CK has no transitions."

> See [08-5_failure_signatures.md](./08-5_failure_signatures.md) — every failure signature (FS-01 through FS-06) requires probe access to at least one net listed in this plan.

---

## 2. Power Rail Test Points

Power rail observability is the single highest-priority DFT requirement. If rails are wrong, nothing else matters.

| Rail | Net Name | Edge Pin(s) | Board-Level TP? | Why It's Needed | What to Measure | Recommended Pad |
|---|---|---|---|---|---|---|
| Core supply | `VDD` | Pin 64 | Yes | Primary DRAM supply; most common root cause of training failures (FS-02) | DC voltage (1.2V ± 5%), ripple under load (< 50 mV pk-pk) | 50 mil round pad |
| I/O supply | `VDDQ` | — (internal) | **Yes (board-level only)** | DRAM I/O driver supply; not present on edge connector; must be probed on-board near DRAM | DC voltage (1.2V ± 5%), ripple during DQ switching | 50 mil round pad |
| Wordline boost | `VPP` | Pin 142 | Yes | DRAM internal wordline voltage; absence prevents DRAM operation entirely | DC voltage (2.5V ± 5%) | 50 mil round pad |
| Ground reference | `GND` | Pin 2 (and many others) | Yes | Scope ground clip attachment point; required for all differential measurements | Ground reference continuity | 100 mil round pad or loop |
| SPD supply | `VDDSPD` | Pin 284 | Yes | SPD EEPROM will not respond without this rail; first thing to check for FS-01 | DC voltage (2.2–3.6V range, host-dependent) | 50 mil round pad |
| Termination | `VTT` | Pin 77, 221 | Nice-to-have | On-die termination reference; absence causes training failure but harder to diagnose | DC voltage (~0.6V, VDD/2) | 20 mil pad |
| Reference | `VREF` | Pin 146 | Nice-to-have | CA bus reference voltage; marginal VREF causes FS-06 | DC voltage (~0.6V, VDDQ/2), noise | 20 mil pad |

**Note on VDDQ:** The JEDEC DDR4 UDIMM connector does not have a dedicated VDDQ pin — VDDQ is generated or distributed on the module itself. The test point must be placed on the PCB trace between the edge connector power input and the DRAM VDDQ balls. This is the only test point in this plan that cannot be probed at the edge connector.

---

## 3. Signal Integrity Test Points — Byte Lane 0

### Why one byte lane is sufficient for v1

All 8 byte lanes (D0–D7) are architecturally identical: same DRAM device type, same trace topology intent, same termination scheme. For a first-article reference design, measuring one representative lane confirms that the design intent is correct. If lane 0 shows clean eye diagrams and correct timing, the other lanes will behave similarly (layout-dependent variations are a Stage 10 concern).

Lane 0 is chosen because:
- It has the lowest pin numbers on the edge connector, making it easiest to locate
- It is typically routed first in layout, making it the most likely to have clean routing
- Failure signature FS-04 (stuck bit) provides a lane-identification formula that starts with lane 0

### Test points for byte lane 0

| Net Name | Edge Pin | Signal Type | What to Measure | Probe Requirements |
|---|---|---|---|---|
| `D0_DQ0` | Pin 5 | Single-ended data | Eye diagram at DDR4-2400 (833 MHz effective); rise/fall time; voltage swing | High-Z passive probe, ≥ 1 GHz BW; 20 mil pad near DRAM |
| `D0_DQS_t` | Pin 153 | Differential strobe (true) | Differential eye with D0_DQS_c; duty cycle; jitter | Differential probe pair, ≥ 1 GHz BW; paired 20 mil pads |
| `D0_DQS_c` | Pin 152 | Differential strobe (complement) | (Paired with D0_DQS_t above) | (Paired with D0_DQS_t above) |
| `D0_DM_DBI_n` | Pin 7 | Data mask / bus inversion | Verify toggle during writes; confirm not stuck | High-Z passive probe; 20 mil pad |

**Measurement objectives:**
1. **Eye diagram:** Confirm the DQ eye opening meets JEDEC DDR4-2400 minimum (setup/hold time > 55 ps per JESD79-4). This proves the schematic connectivity and basic SI are functional.
2. **DQS-to-DQ timing:** Confirm DQS transitions are centered in the DQ eye. Gross misalignment indicates a connectivity or topology error.
3. **Voltage swing:** Confirm DQ swings between VOL (< 0.2V) and VOH (> 0.8 × VDDQ). Reduced swing indicates termination or driver issues.

> **v2 consideration:** If v1 validation reveals lane-to-lane variation, v2 should add test points on lane 4 (mid-bus) and lane 7 (end-of-bus) for comparison.

---

## 4. Clock Test Points

The differential clock pair is the heartbeat of the DDR4 interface. If CK is absent or degraded, no training or data transfer is possible.

| Net Name | Edge Pin | What to Measure | Probe Requirements |
|---|---|---|---|
| `CK_t` | Pin 74 | Differential clock with CK_c; frequency (1200 MHz for DDR4-2400); jitter (< 50 ps pk-pk per JEDEC); duty cycle (47–53%) | Differential probe, ≥ 2 GHz BW; paired 20 mil pads with controlled spacing |
| `CK_c` | Pin 75 | (Paired with CK_t above) | (Paired with CK_t above) |

**Why clock measurements matter:**
- **Jitter:** Excessive clock jitter reduces the timing margin for every DQ bit on every lane. Clock jitter is the single largest contributor to timing margin erosion in DDR4.
- **Duty cycle:** DDR4 uses both rising and falling clock edges. Duty cycle distortion (DCD) asymmetrically reduces setup/hold time on one edge, potentially causing intermittent failures (FS-05).
- **Probe access geometry:** The CK test points must be a closely-spaced differential pair (< 1 mm center-to-center) to minimize common-mode noise pickup during measurement. Consider a 2-pin 0.050" header footprint or SMA-compatible pad pair if board area permits.

> See [08-5_failure_signatures.md](./08-5_failure_signatures.md) FS-02 and FS-06 for clock-related failure diagnostics.

---

## 5. SPD Bus Test Points

The SPD I²C bus is the module's first interaction with any host. If SPD fails, the host cannot identify the module, and all subsequent validation is blocked.

| Net Name | Edge Pin | What to Measure | Probe Requirements |
|---|---|---|---|
| `SPD_SCL` | Pin 141 | I²C clock: frequency (~100 kHz standard mode), pull-up voltage level (should reach VDDSPD), waveform quality (clean transitions, no bus contention) | Passive probe, any bandwidth; 50 mil pad |
| `SPD_SDA` | Pin 285 | I²C data: ACK/NACK response from EEPROM, data integrity, bus contention check | Passive probe, any bandwidth; 50 mil pad |

**Why I²C visibility is critical:**
- FS-01 (SPD not detected) is the most common first-power-up failure mode. Without SCL/SDA test points, diagnosing FS-01 requires guessing between 6 possible root causes.
- With test points, a single scope capture shows: (a) whether SCL is toggling (host is trying), (b) whether SDA shows ACK (EEPROM is responding), and (c) whether pull-ups are functional (signals reach VDDSPD level).
- I²C is low-speed (~100 kHz), so test point stubs have zero impact on signal integrity. There is no reason to omit SPD test points.

---

## 6. Address/Command Bus Test Points

The CA bus has 33+ signals. Providing test points for all of them is impractical on a UDIMM form factor. One representative signal is sufficient for v1 to confirm that the CA bus is electrically active during training.

### Selected signal: CS0_n (Chip Select, rank 0)

| Net Name | Edge Pin | What to Measure | Probe Requirements |
|---|---|---|---|
| `CS0_n` | Pin 84 | Active-low chip select: confirm host asserts CS0_n during training; verify voltage levels (VOL < 0.2V when active, VOH > 0.8 × VDD when inactive); timing relative to CK | Passive probe, ≥ 500 MHz BW; 20 mil pad |

**Why CS0_n:**
- CS0_n is the most diagnostic single signal on the CA bus. If CS0_n is not asserted, the DRAM device ignores all commands — making it the first signal to check when training fails (FS-02).
- Unlike address bits (which require specific command sequences to observe), CS0_n toggles on every command, making it easy to capture on a scope without triggering complexity.
- FS-02 diagnostic step 5 specifically calls for probing CS0_n (pin 84).

**Secondary CA test point (nice-to-have):** `RESET_n` (pin 58) — confirms the DRAM reset sequence completes. RESET_n should transition from LOW to HIGH during power-up. If it stays LOW, the DRAM never exits reset.

---

## 7. Test Point Summary Table

| Net Name | Edge Pin | Signal Domain | Purpose | Priority | Probe Type |
|---|---|---|---|---|---|
| `VDD` | 64 | Power | Core supply verification | P1 — Must-have | 50 mil pad |
| `VDDQ` | — (board) | Power | I/O supply verification | P1 — Must-have | 50 mil pad (board-level) |
| `VPP` | 142 | Power | Wordline boost verification | P1 — Must-have | 50 mil pad |
| `GND` | 2 | Power | Scope ground reference | P1 — Must-have | 100 mil pad/loop |
| `VDDSPD` | 284 | Power | SPD supply verification (FS-01) | P1 — Must-have | 50 mil pad |
| `SPD_SCL` | 141 | Configuration | I²C clock observability (FS-01) | P1 — Must-have | 50 mil pad |
| `SPD_SDA` | 285 | Configuration | I²C data observability (FS-01) | P1 — Must-have | 50 mil pad |
| `CK_t` | 74 | Clock | Differential clock true (FS-02/06) | P1 — Must-have | 20 mil differential pair |
| `CK_c` | 75 | Clock | Differential clock complement | P1 — Must-have | 20 mil differential pair |
| `CS0_n` | 84 | Command | Chip select observability (FS-02) | P1 — Must-have | 20 mil pad |
| `D0_DQ0` | 5 | Data | Representative DQ eye diagram | P2 — Needed for L3+ | 20 mil pad |
| `D0_DQS_t` | 153 | Data | Strobe true (differential pair) | P2 — Needed for L3+ | 20 mil differential pair |
| `D0_DQS_c` | 152 | Data | Strobe complement | P2 — Needed for L3+ | 20 mil differential pair |
| `D0_DM_DBI_n` | 7 | Data | Data mask verification | P3 — Nice-to-have | 20 mil pad |
| `VTT` | 77 | Power | Termination rail check | P3 — Nice-to-have | 20 mil pad |
| `VREF` | 146 | Power | Reference voltage check (FS-06) | P3 — Nice-to-have | 20 mil pad |
| `RESET_n` | 58 | Command | Reset sequence verification (FS-02) | P3 — Nice-to-have | 20 mil pad |

**Total test points:** 17 (10 must-have, 3 needed-for-L3+, 4 nice-to-have)

---

## 8. Scope Boundaries — What v1 Does NOT Include

The following DFT features are explicitly **out of scope** for OMI v1:

| Excluded Feature | Why Excluded | When It Might Be Added |
|---|---|---|
| JTAG / boundary scan | Requires JTAG TAP controller on module; UDIMMs do not have JTAG infrastructure | Not applicable to UDIMM form factor |
| Production ICT (in-circuit test) pads | Designed for automated factory testing with bed-of-nails fixtures; irrelevant for a reference design | Only if OMI targets volume production |
| BGA-side probing pads | Requires access to the underside of BGA DRAM packages; not feasible without specialized equipment | v2 if flip-chip debug is needed |
| Eye diagram compliance test points | JEDEC-compliant eye measurement requires specific load and probe fixtures defined in JESD79-4 | v2 with proper SI test methodology |
| All-lane DQ test points | 64 DQ bits × 2 (pad + ground) = 128 additional pads; not feasible on UDIMM form factor | v2 if lane-to-lane variation is observed in v1 |
| Thermal sensor test points | DDR4 DRAM devices have internal thermal sensors accessible via MRS commands, not external pins | Use host-side thermal monitoring instead |
| Power sequencing debug headers | Would require multi-pin headers for VPP/VDD/VDDQ sequencing capture | v2 if sequencing issues are observed |

---

## Cross-References

- [08-5_failure_signatures.md](./08-5_failure_signatures.md) — Every failure signature requires probe access to nets in this plan
- [L1_bench_electrical/measurement_procedures.md](./L1_bench_electrical/measurement_procedures.md) — L1 bench procedures reference these test point locations
- [ddr4_udimm_288_pinmap.csv](../../design/connector/ddr4_udimm_288_pinmap.csv) — Authoritative pin-to-net mapping; all pin numbers in this document are sourced from this CSV
- [08-2_bringup_ladder.md](./08-2_bringup_ladder.md) — Test points enable measurements required at each ladder level

---

*This document defines where to probe. For what to measure at each step, see [08_03_bringup_procedure.md](./08_03_bringup_procedure.md). For pass/fail criteria, see [08-2_bringup_ladder.md](./08-2_bringup_ladder.md).*

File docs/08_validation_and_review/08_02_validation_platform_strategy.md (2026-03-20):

# Stage 8.02 — Validation Platform Strategy (OMI v1)

## Project
Open Memory Initiative (OMI) — OMI v1 DDR4 UDIMM

## Status
Draft

## Purpose
Define specific host platforms for OMI v1 validation, with concrete board recommendations, cost estimates, a phased deployment strategy, and an honest assessment of platform risks. This document operationalizes the platform taxonomy defined in [08-1_validation_platforms.md](./08-1_validation_platforms.md).

---

## Relationship to Existing Documents

This document **extends** the following:

- [08-1_validation_platforms.md](./08-1_validation_platforms.md) — Defines the Class A / B / C platform taxonomy, minimum requirements per class, evidence capabilities, and ladder-level mapping. **Read that document first.** This document does not repeat those definitions.
- [08-4_reporting_template.md](./08-4_reporting_template.md) — Defines the Run ID scheme and report format used for all platform results.

**What this document adds:** specific board recommendations, approximate costs, a phased strategy for which platform to use when, a platform documentation template, and a risk register.

---

## 1. Detailed Platform Requirements

Any platform used for OMI v1 validation must meet these requirements beyond the Class minimums in [08-1](./08-1_validation_platforms.md):

### 1.1 Hardware Requirements

| Requirement | Why It Matters |
|---|---|
| At least one DDR4 UDIMM slot (288-pin, no adapter) | Adapters introduce contact resistance and signal integrity unknowns that confound debugging |
| Rated for DDR4-2400 or faster | OMI v1 targets DDR4-2400; the platform must support this speed natively |
| Single-DIMM operation supported | Some platforms require matched pairs; OMI v1 must be testable in isolation |
| Physical access to DIMM slot for probe attachment | Slots buried under heatsinks or shrouds prevent L1 bench measurements |

### 1.2 Firmware/BIOS Requirements

| Requirement | Why It Matters |
|---|---|
| SPD readout visible in BIOS setup | Confirms L2 (SPD read) without requiring OS boot |
| Memory speed configurable (auto + manual) | If training fails at DDR4-2400, ability to force DDR4-2133 helps isolate whether speed or connectivity is the issue |
| Memory training error reporting | Platforms that silently skip a failed DIMM provide no diagnostic value |
| BIOS version documented and reproducible | Training behavior can change between BIOS updates; results must be tied to a specific version |

### 1.3 Software Requirements

| Requirement | Why It Matters |
|---|---|
| Bootable from USB (Linux live environment) | Eliminates OS installation as a variable; enables `i2cdetect`, `decode-dimms`, `memtest86+` |
| I²C/SMBus access from OS | Required for L2 SPD verification using `i2c-tools` |
| `dmidecode` or equivalent available | Required for L3 OS-level memory reporting |

---

## 2. Option A — Consumer Motherboard (Class A)

### Why consumer boards are the primary v1 platform

Consumer motherboards are cheap, widely available, and represent the most common host environment for DDR4 UDIMMs. If the OMI v1 module works in a consumer board, it works in the real world. This is the most meaningful validation for an open reference design.

### Recommended board families

| Board Family | Chipset | Socket | DDR4 Slot Count | Approx. Cost (Used) | Notes |
|---|---|---|---|---|---|
| **Intel B660 / H670** | Intel 600-series | LGA 1700 | 2–4 UDIMM | $60–$120 | 12th gen Intel; widely available; well-documented BIOS behavior; DDR4 variants common |
| **Intel B560 / H570** | Intel 500-series | LGA 1200 | 2–4 UDIMM | $50–$100 | 10th/11th gen Intel; very common on used market; stable BIOS ecosystem |
| **AMD B550 / B450** | AMD 500/400-series | AM4 | 2–4 UDIMM | $50–$100 | Ryzen 3000/5000 series; strong community BIOS support; DDR4 native |

### Pros

- **Low cost:** $50–$120 for a used board; add $30–$80 for a compatible CPU (e.g., Celeron G6900 for LGA 1700, Athlon 3000G for AM4). Total platform cost under $200.
- **Real-world host behavior:** Proves the module works with actual memory controllers and training algorithms that end users will encounter.
- **Wide availability:** Easy for community contributors to replicate results on similar hardware.
- **Fast iteration:** Insert module, power on, observe. No FPGA bitstream compilation or IP licensing.

### Cons

- **Closed firmware:** BIOS training algorithms are proprietary. If training fails, the BIOS error code may be cryptic or undocumented.
- **Limited debug visibility:** No access to internal training state, read leveling results, or write leveling margins.
- **Platform-specific quirks:** Intel and AMD memory controllers train differently. A module that trains on Intel may fail on AMD (or vice versa). This is not an OMI design flaw — it is a platform constraint that must be documented.
- **BIOS updates change behavior:** A BIOS update on the test platform can change training results. Pin validation to a specific BIOS version.

### Recommended v1 configurations

**Primary (Intel):**
- Board: Any Intel B660 with 2+ DDR4 UDIMM slots (e.g., MSI PRO B660M-A DDR4, ASUS PRIME B660M-A D4)
- CPU: Intel Celeron G6900 or Pentium Gold G7400 (cheapest LGA 1700 DDR4 option)
- Estimated total: ~$100–$150 used

**Secondary (AMD):**
- Board: Any AMD B550 with DDR4 UDIMM slots (e.g., MSI B550M PRO-VDH, Gigabyte B550M DS3H)
- CPU: AMD Athlon 3000G or Ryzen 3 3100 (cheapest AM4 option)
- Estimated total: ~$80–$130 used

> **Why two platforms?** Testing on both Intel and AMD confirms the module works with fundamentally different memory controller implementations. If the module works on both, platform-specific training is not a concern. If it works on one but not the other, the failure is documented and informs v2.

---

## 3. Option B — FPGA-Based Validation (Class B)

### Why FPGA validation exists as an option

FPGA-based DDR4 controllers provide full visibility into the training process: read leveling delays, write leveling results, per-lane error counts, and frequency sweeping. This is invaluable for deep characterization but comes at significant cost and complexity.

### Available platforms

| Platform | FPGA | DDR4 Interface | UDIMM Slot? | Approx. Cost | Open-Source Controller? |
|---|---|---|---|---|---|
| **Xilinx VCU118** | Virtex UltraScale+ | DDR4 DIMM | Yes (full-size) | $5,000+ | No (Xilinx MIG IP, licensed) |
| **Xilinx ZCU104** | Zynq UltraScale+ | DDR4 component | **No** (BGA pads only) | $1,000+ | No (Xilinx MIG IP) |
| **LiteDRAM on Arty A7** | Artix-7 | DDR3 only | No (SO-DIMM) | $130 | **Yes** (LiteDRAM, open-source) |
| **Antmicro DDR4 Tester** | Xilinx K7/KU | DDR4 RDIMM | **No** (RDIMM, not UDIMM) | Custom fab | **Yes** (open-source KiCad design) |
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

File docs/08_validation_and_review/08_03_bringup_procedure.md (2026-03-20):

# Stage 8.03 — Bring-Up Procedure (OMI v1)

## Project
Open Memory Initiative (OMI) — OMI v1 DDR4 UDIMM

## Status
Draft

## Purpose
Provide a step-by-step bring-up procedure from bare fabricated PCB to OS boot. Written so another engineer can follow it independently without oral instructions. This is the operational counterpart to the validation ladder defined in [08-2_bringup_ladder.md](./08-2_bringup_ladder.md).
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

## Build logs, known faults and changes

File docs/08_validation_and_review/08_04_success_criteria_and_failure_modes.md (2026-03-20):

# Stage 8.04 — Success Criteria & Failure Modes (OMI v1)

## Project
Open Memory Initiative (OMI) — OMI v1 DDR4 UDIMM

## Status
Draft

## Purpose
Consolidate pass/fail definitions across all validation levels into a single reference, extend the existing failure signature catalog with diagnostic decision trees, and document honest unknowns that cannot be resolved until hardware exists.

---

## Relationship to Existing Documents

This document **consolidates and extends** three existing references:

- [08-2_bringup_ladder.md](./08-2_bringup_ladder.md) — Authoritative pass/fail criteria per level (L0–L4). This document summarizes but does not replace those definitions.
- [08-3_test_matrix.md](./08-3_test_matrix.md) — Test categories (T1–T7), durations, and failure taxonomy (deterministic/intermittent/environment).
- [08-5_failure_signatures.md](./08-5_failure_signatures.md) — Six failure signatures (FS-01 through FS-06) with symptom-to-cause mappings.

**What this document adds:**
1. A consolidated success criteria summary table for quick reference
2. A failure mode catalog organized by validation level (not by signature number)
3. Diagnostic decision trees for each level
4. A failure reporting template
5. An honest unknowns register

---

## 1. Consolidated Success Criteria

This table provides a quick-reference summary. For full pass/fail criteria and required artifacts, see [08-2_bringup_ladder.md](./08-2_bringup_ladder.md).

| Level | Gate | One-Line Success Criterion | Key Evidence | Ref |
|---|---|---|---|-----|
| **L0** | Artifact Integrity | All 288 pins mapped, net names consistent, no TBDs in frozen artifacts | CSV integrity output, naming audit log | [08-2 §L0](./08-2_bringup_ladder.md) |
| **L1** | Bench Electrical | All functional nets have continuity, all power rails isolated, no shorts | Continuity log, rail isolation measurements | [08-2 §L1](./08-2_bringup_ladder.md) |
| **L2** | Host Enumeration | SPD EEPROM readable, returns correct DDR4 configuration, host recognizes module | Raw SPD hex dump, BIOS POST screenshot | [08-2 §L2](./08-2_bringup_ladder.md) |
| **L3** | Training + Boot | Host trains at DDR4-2400, OS boots, correct capacity reported, short memtest passes | BIOS training log, OS memory report, memtest screenshot | [08-2 §L3](./08-2_bringup_ladder.md) |
| **L4** | Stress + Soak | Zero errors in extended memtest (≥2 passes), stable under sustained load for ≥1 hour | memtest86+ result, stress log, thermal data | [08-2 §L4](./08-2_bringup_ladder.md) |

### What "PASS" means at each level

- **L0 PASS:** Automated scripts (`verify_pinmap.py`, `verify_naming.py`) return zero errors. Peer review checklist completed with no unresolved findings.
- **L1 PASS:** All 288 pins probed per [measurement_procedures.md](./L1_bench_electrical/measurement_procedures.md). Zero opens on functional nets, zero shorts between distinct nets, all rails isolated.
- **L2 PASS:** SPD read completes on at least one Class A platform. Key SPD fields match expected values: DDR4, 8 GB, 1Rx8, DDR4-2400, non-ECC.
- **L3 PASS:** Training completes, OS boots, `dmidecode` reports correct capacity, memtest runs ≥10 minutes with zero errors.
- **L4 PASS:** memtest86+ runs ≥2 full passes with zero errors. System stable under memory stress for ≥1 hour. No thermal anomalies.

### What "FAIL" means

A failure at any level is a **hard stop**. Do not proceed to the next level. A failure is also a **valid engineering result** — it narrows the problem space and informs the design. Failures must be documented with the same rigor as passes.

---

## 2. Expected Failure Mode Catalog

This catalog organizes failure modes by the validation level where they are most likely to surface. For detailed symptom-to-cause mappings, see [08-5_failure_signatures.md](./08-5_failure_signatures.md).

### L1 Failures — Bench Electrical

| Failure Mode | Symptoms | Likely Root Cause | Diagnostic Steps | Severity |
|---|---|---|---|---|
| Power rail short (VDD-to-GND) | DVM reads < 1 Ω between VDD and GND | Solder bridge on DRAM power pins; shorted decoupling capacitor | Visual inspection under magnification; isolate by removing components | **Critical** — do not power on |
| Power rail cross-contamination | DVM reads < 10 kΩ between VDD and VPP (or other rail pair) | PCB manufacturing defect; solder bridge between adjacent power vias | Measure all rail pairs per [measurement_procedures.md](./L1_bench_electrical/measurement_procedures.md) Session 2 | **Critical** — do not power on |
| Open circuit on functional net | DVM shows no continuity from edge pin to DRAM pad | Missing solder joint; PCB trace break; component not placed | Probe at intermediate points along the trace to localize the break | **Critical** — L1 blocker |
| I²C bus pull-up missing | SDA/SCL measure 0V or float (no pull-up to VDDSPD) | Pull-ups are host-side in OMI v1; check if host provides pull-ups. If testing with Class C jig, external pull-ups are required | Measure resistance from SDA (pin 285) to VDDSPD (pin 284); expect 2.2–4.7 kΩ if pull-up present | **High** — L2 will fail |

### L1/L2 Failures — SPD

| Failure Mode | Symptoms | Likely Root Cause | Diagnostic Steps | Severity |
|---|---|---|---|---|
| SPD EEPROM not responding | `i2cdetect` shows no device at 0x50; BIOS skips DIMM slot | See [FS-01](./08-5_failure_signatures.md) — VDDSPD missing, SA address wrong, SDA/SCL open, pull-ups missing, EEPROM blank | Follow FS-01 diagnostic sequence: probe VDDSPD → check SA pins → check SDA/SCL continuity | **Critical** — L2 blocker |
| SPD returns garbage data | SPD bytes are all-0x00 or all-0xFF; or random-looking data | EEPROM not programmed (blank chip); SDA noise; I²C bus contention from other devices | Dump raw 256 bytes; check if pattern is uniform (blank) or random (noise); scope SDA waveform | **Critical** — L2 blocker |
| SPD reports incorrect configuration | SPD reads successfully but reports wrong capacity, speed, or type | SPD content programming error; wrong hex image burned to EEPROM | Compare SPD bytes against expected values per JEDEC DDR4 SPD spec (JESD21C); reprogram if wrong | **High** — L3 will fail |

### L3 Failures — Training and Boot

| Failure Mode | Symptoms | Likely Root Cause | Diagnostic Steps | Severity |
|---|---|---|---|---|
| Host refuses to train module | Boot loop; BIOS error code; system hangs during POST | See [FS-02](./08-5_failure_signatures.md) — VDD/VDDQ marginal, RESET_n stuck, CKE not asserting, CK absent, CS0_n not asserted | Follow FS-02 sequence: probe VDD → RESET_n → CKE0 → CK_t/CK_c → CS0_n | **Critical** — L3 blocker |
| Training succeeds but wrong capacity | BIOS reports 4 GB instead of 8 GB | See [FS-03](./08-5_failure_signatures.md) — DQ lane open, address bit open, SPD capacity field wrong | Identify which half of memory is missing; check corresponding DQ lanes or address bits | **Critical** — L3 blocker |
| SPD OK but training fails | BIOS reads SPD correctly, then fails during training | See [FS-06](./08-5_failure_signatures.md) — SPD timing bytes incorrect, CK marginal, platform doesn't support programmed speed, VREF marginal | Force DDR4-2133 in BIOS; if training passes, SPD speed profile needs adjustment | **Critical** — L3 blocker |
| Module works on one platform but not another | Trains on Intel, fails on AMD (or vice versa) | Different memory controller training algorithms; different impedance calibration ranges; different timing tolerance | **This is not necessarily an OMI design flaw.** Document both results with full platform details. Compare SPD timing values against both vendors' supported ranges. | **High** — investigate, do not assume OMI fault |

### L3/L4 Failures — Data Integrity

| Failure Mode | Symptoms | Likely Root Cause | Diagnostic Steps | Severity |
|---|---|---|---|---|
| Deterministic bit errors (same address every run) | memtest reports stuck bit at fixed address | See [FS-04](./08-5_failure_signatures.md) — DQ pin open/shorted, DQS not reaching DRAM, DM pin fault, per-device VDD marginal | Identify failing lane: `lane = error_bit // 8`; check continuity on that DQ pin | **Critical** — L4 blocker |
| Intermittent bit errors under stress | Errors appear after extended soak; may be thermally correlated | See [FS-05](./08-5_failure_signatures.md) — marginal solder joint, VDD droop under load, SI marginal at temperature | Record error onset time and temperature; scope VDD ripple under load; test with active cooling | **High** — do not waive |
| Thermal issues under sustained load | DRAM device temperature exceeds 85°C (DDR4 max operating); errors increase with temperature | Insufficient airflow; excessive power dissipation; PCB thermal design issue | Measure DRAM case temperature with IR thermometer; add active cooling; retest | **High** — L4 blocker |

---

## 3. Diagnostic Decision Trees

These text-based decision trees guide first-response diagnostics. They complement (not replace) the detailed tables in [08-5_failure_signatures.md](./08-5_failure_signatures.md).

### L1 Decision Tree: Module fails continuity checks

```
START: Continuity check fails on one or more nets
  │
  ├─ Is the failure on a POWER net (VDD, VDDQ, VPP, GND)?
  │   ├─ YES → Is it a SHORT (< 1 Ω between distinct rails)?
  │   │         ├─ YES → DO NOT POWER ON. Visual inspection for solder bridges.
  │   │         │         Remove decoupling caps one at a time to isolate.
  │   │         └─ NO → Is it an OPEN (no continuity to DRAM)?
  │   │                   └─ Check intermediate via/trace points. Likely PCB defect.
  │   └─ NO → Is the failure on a DQ/DQS net?
  │             ├─ YES → Check specific DRAM device solder joints.
  │             │         This will cause partial capacity at L3 (FS-03).
  │             └─ NO → Is it a CA/CLK net?
  │                       └─ Check DRAM-side solder; this will cause training failure at L3 (FS-02).
```

### L2 Decision Tree: SPD read fails

```
START: Host does not detect module on I²C bus
  │
  ├─ Probe VDDSPD (pin 284): Is voltage 2.2–3.6V?
  │   ├─ NO → Host is not supplying VDDSPD. Check host board SPD power.
  │   │         If using Class C jig, provide external 3.3V to VDDSPD.
  │   └─ YES → Probe SDA (pin 285) and SCL (pin 141): Are pull-ups present?
  │               ├─ NO → Pull-ups are host-side. Verify host provides them.
  │               │         If Class C jig, add 4.7 kΩ pull-ups to VDDSPD.
  │               └─ YES → Check SA0 (pin 139), SA1 (pin 140), SA2 (pin 238):
  │                          What address are they selecting?
  │                          ├─ Wrong address → Fix SA strap resistors.
  │                          └─ Correct address (0x50) → Check EEPROM orientation.
  │                                                       Probe EEPROM VCC, GND, WP.
  │                                                       If all OK → EEPROM may be defective or blank.
```

### L3 Decision Tree: Training fails

```
START: BIOS enters boot loop or shows memory error
  │
  ├─ Did L2 pass (SPD read OK)?
  │   ├─ NO → Go back to L2 decision tree. Do not skip levels.
  │   └─ YES → Probe VDD (pin 64) and VDDQ: Are voltages correct under load?
  │               ├─ NO → Power delivery issue. Check host VRM and decoupling.
  │               └─ YES → Probe CK_t (pin 74) / CK_c (pin 75): Is clock present?
  │                          ├─ NO → Clock not reaching module. Check host clock driver.
  │                          └─ YES → Probe RESET_n (pin 58): Does it deassert (go HIGH)?
  │                                     ├─ NO → RESET stuck low. Check RESET trace continuity.
  │                                     └─ YES → Force DDR4-2133 in BIOS:
  │                                                ├─ Training passes → SPD speed profile issue (FS-06)
  │                                                └─ Training still fails → Check CS0_n (pin 84),
  │                                                    CKE0 (pin 60); if both active, suspect
  │                                                    DQ lane issue → probe D0_DQ0 (pin 5)
```

---

## 4. Failure Reporting Template

Use this template for every failure encountered during OMI v1 validation. Submit as a markdown file in the validation run directory and open a corresponding GitHub issue.

```markdown
## Failure Report: [SHORT DESCRIPTIVE TITLE]

**Run ID:** [Per 08-4_reporting_template.md scheme]
**Date:** [YYYY-MM-DD]
**Platform:** [Platform ID from platform documentation template]
**Validation Level:** L1 / L2 / L3 / L4
**Failure Category:** DETERMINISTIC / INTERMITTENT / ENVIRONMENT
  (per 08-3_test_matrix.md §3 taxonomy)

### Symptom
[Exact observed behavior. Be specific: "BIOS shows error code 55 and reboots"
not "training failed".]

### Environment
| Field | Value |
|-------|-------|
| BIOS version | |
| OS version | |
| Ambient temperature | |
| Other DIMMs present | |
| BIOS memory settings | |

### Evidence
- [ ] Photo/screenshot: [filename]
- [ ] Measurement log: [filename]
- [ ] Scope capture: [filename]
- [ ] SPD dump: [filename]
[All evidence stored in validation/results/<RunID>/]

### Hypotheses (ranked by likelihood)
1. [Most likely cause — with reasoning]
2. [Second most likely — with reasoning]
3. [Third most likely — with reasoning]

### Diagnostic Steps Taken
1. [What you measured/checked]
2. [Result of that measurement]
3. [Next measurement based on result]

### Resolution
[If known: what fixed the issue. If unknown: state "Unresolved — further
investigation required" and list the next diagnostic steps to try.]

### GitHub Issue
[Link to opened issue, or "Pending — will open after peer review"]
```

---

## 5. Honest Unknowns

These are things the OMI project does not know and **cannot know** until fabricated hardware exists and is tested. They are not failures of planning — they are engineering realities that must be acknowledged honestly.

| Unknown | Why We Don't Know Yet | What Evidence Resolves It | At Which Level |
|---|---|---|---|
| **Actual VDD/VDDQ current draw under training** | No hardware to measure; DRAM datasheet gives typical/max but actual depends on PCB and host | Measure supply current at test points during L3 training; compare against datasheet IDD values | L3 |
| **Signal integrity eye quality at DDR4-2400** | No SI simulation has been performed (OMI v1 has no simulation infrastructure); eye quality depends on PCB stackup, trace geometry, and termination — all layout-stage decisions | Oscilloscope eye diagram measurement at D0_DQ0 test point; compare against JEDEC minimum eye opening | L3/L4 |
| **Platform-specific training sensitivity** | Intel and AMD memory controllers use different training algorithms with different tolerance ranges; behavior cannot be predicted without testing | Test on both Intel and AMD Class A platforms; document pass/fail per platform with full BIOS settings | L3 |
| **DRAM device-to-device timing variation** | Timing margins depend on the specific lot of DRAM devices populated; lot-to-lot variation is a manufacturing reality | If intermittent errors appear, test multiple modules built with different DRAM lots (requires multiple fabrication runs) | L4 |
| **Thermal behavior under sustained load** | No thermal modeling has been done; DRAM self-heating depends on data patterns, refresh rate, ambient conditions, and airflow | Measure DRAM case temperature during L4 soak testing with thermal camera or contact thermometer | L4 |
| **Whether conservative JEDEC timings will train reliably on consumer boards** | Some consumer board BIOSes are optimized for XMP profiles and may behave unexpectedly with strict JEDEC base timings | Attempt training with SPD programmed for JEDEC DDR4-2400 base profile (CL17-17-17-39); document result | L3 |
| **SPD vendor ID acceptance** | Some BIOSes may check the SPD manufacturer ID byte against a known-vendor list and refuse to train unknown vendors | Program SPD with the chosen vendor ID and test; if rejected, try alternative IDs and document findings | L2/L3 |
| **VPP power-up sequencing tolerance** | JEDEC specifies VPP must be present before VDD, but consumer boards may not enforce strict sequencing; the actual tolerance is host-dependent | Monitor VPP and VDD at test points during cold boot with a dual-channel scope; check sequencing compliance | L1/L3 |

> **Policy:** An unknown is not a defect. It is an engineering question that has a defined resolution path. Every unknown in this table has a specific measurement that will resolve it. The project commits to performing these measurements when hardware is available and documenting the results — including results that reveal problems.

---

## Cross-References

- [08-2_bringup_ladder.md](./08-2_bringup_ladder.md) — Authoritative pass/fail criteria per level
- [08-3_test_matrix.md](./08-3_test_matrix.md) — Test categories, durations, and failure taxonomy
- [08-5_failure_signatures.md](./08-5_failure_signatures.md) — Detailed failure signatures FS-01 through FS-06
- [08_01_test_point_and_dft_plan.md](./08_01_test_point_and_dft_plan.md) — Test point locations referenced in diagnostic steps
- [08_03_bringup_procedure.md](./08_03_bringup_procedure.md) — Step-by-step procedure where these failures may surface

---

*This document defines what success and failure look like. For how to perform validation, see [08_03_bringup_procedure.md](./08_03_bringup_procedure.md). For where to probe, see [08_01_test_point_and_dft_plan.md](./08_01_test_point_and_dft_plan.md).*

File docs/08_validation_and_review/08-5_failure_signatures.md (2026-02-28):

# Stage 8.5 — Failure Signatures (OMI v1)

## Project
Open Memory Initiative (OMI) — OMI v1 DDR4 UDIMM

## Status
Draft

## Purpose
Catalog common DDR4 failure patterns with symptom → likely cause mappings and recommended next measurements. This makes failures explainable rather than mysterious.

> Use this reference when a bring-up test fails. Match the symptom, read the likely causes, take the recommended measurements before opening an issue.

---

## FS-01 — SPD Not Detected / I²C NACK

**Symptom:**
- BIOS skips the DIMM slot silently
- `i2cdump` returns NACK or all-0xFF
- `decode-dimms` outputs no module found
- SMBus transaction times out

**Likely causes (in order of probability):**

| Priority | Cause | How to distinguish |
|---|---|---|
| 1 | VDDSPD rail missing or < 2.2 V | Probe VDDSPD on edge connector (pin 284) with DVM |
| 2 | SA0/SA1/SA2 address bits wrong | Check device address: default is 0x50 (SA=000); probe pins 139/140/238 |
| 3 | SDA or SCL open circuit | Continuity from pin 141 (SCL) and 285 (SDA) to EEPROM |
| 4 | No host pull-up on SDA/SCL | Pull-ups are host-side in OMI v1; confirm host board has them |
| 5 | EEPROM WP held high | WP tied to GND in OMI v1 design — verify |
| 6 | EEPROM unprogrammed | Dump raw bytes; all-0x00 or all-0xFF means blank chip |

**Recommended measurements:**
1. DVM: VDDSPD pin 284 → GND — expect 2.2–3.6 V with host powered
2. DVM: continuity SCL (141) → EEPROM SCL pad
3. DVM: continuity SDA (285) → EEPROM SDA pad
4. Logic analyzer / scope on SCL/SDA — confirm pull-up waveform shape (should not be floating/square-wave-only)

---

## FS-02 — Memory Training Failure (Boot Loop / No POST)

**Symptom:**
- System reboots repeatedly during POST
- BIOS shows memory error code / beep code
- System posts but hangs before OS
- BIOS shows 0 MB or wrong capacity

**Likely causes:**

| Priority | Cause | How to distinguish |
|---|---|---|
| 1 | VDD or VDDQ rail missing / marginal | Probe VDD (e.g., pin 64) and VDDQ on known-good supply; check voltage under load |
| 2 | RESET_n not releasing (stuck low) | Probe pin 58 — should go HIGH (≥ 0.8 × VDD) during POST |
| 3 | CKE0 not asserting | Probe pin 60 — should toggle during training sequence |
| 4 | CK_t / CK_c not reaching module | Probe pins 74/75 for differential clock signal |
| 5 | CS0_n not asserted | Probe pin 84 |
| 6 | DQ lane(s) open | See FS-04 — wrong capacity often accompanies training |
| 7 | Termination rail VTT absent | Probe pins 77/221; should be VDD/2 |
| 8 | VREF absent or wrong level | Probe pin 146 (VREFCA); should be ~VDD/2 |

**Recommended measurements:**
1. DVM: VDD and VDDQ under load — expect 1.2 V ± 5%
2. Scope: RESET_n (pin 58) during cold power-on — confirm deassert after DRAM power-up sequence
3. Scope: CK_t/CK_c (pins 74/75) — confirm differential clock, no missing transitions
4. Scope: CKE0 (pin 60) — confirm it toggles during POST

---

## FS-03 — Module Detected but Wrong Capacity

**Symptom:**
- BIOS shows 4 GB instead of 8 GB (or similar fraction)
- OS reports less RAM than expected
- memtest tests a smaller region than installed capacity

**Likely causes:**

| Priority | Cause | How to distinguish |
|---|---|---|
| 1 | One or more DQ byte lanes open | Wrong capacity appears as 50%/25% of expected; lane-level |
| 2 | Address bit open (A0–A13) | Causes mirrored/aliased address space |
| 3 | BA0/BA1/BG0/BG1 open | Reduces accessible bank count |
| 4 | SPD capacity field wrong | Compare SPD byte 0x04/0x06 against JEDEC DDR4 SPD spec |

**Recommended measurements:**
1. FPGA/Class B: isolate individual DQ lanes with BIST — identify which lane is open
2. Continuity: check each DQ lane from edge connector pin → DRAM ball
3. SPD dump: verify capacity bytes (0x04: bank/row/col; 0x06: primary bus width)

---

## FS-04 — Random Single-Bit Errors (Deterministic Address)

**Symptom:**
- memtest reports error at the same address every run
- Stuck bit — always 0 or always 1
- Error pattern is address-independent within one lane

**Likely causes:**

| Priority | Cause | How to distinguish |
|---|---|---|
| 1 | DQ pin open or shorted to neighbour | Continuity test on that specific DQ pin |
| 2 | DQS not reaching the DRAM for that lane | Probe DQS_t/DQS_c for the failing lane |
| 3 | DM/DBI pin shorted to a DQ pin in the lane | Check DM pin continuity; DM stuck low masks all writes |
| 4 | VDD marginal to that DRAM device | Check per-device decoupling; probe VDD at the DRAM |

**How to identify failing lane from error address:**
- Lane assignment: `lane = error_bit // 8`
- Bit within lane: `bit = error_bit % 8`
- Map to connector pin via `ddr4_udimm_288_pinmap.csv` → `omi_net = D{lane}_DQ{bit}`

**Recommended measurements:**
1. Look up the failing DQ net in the CSV
2. Continuity: front-side edge pin → DRAM pad
3. Scope: DQS_t/c for the failing lane during write burst
4. Scope: DQ signal eye quality on the failing bit

---

## FS-05 — Intermittent / Thermally-Triggered Errors

**Symptom:**
- memtest passes in cold run; fails after warm soak
- Errors appear after 4+ hours of stress, then the system stabilizes
- Error count increases monotonically over time

**Likely causes:**

| Priority | Cause | How to distinguish |
|---|---|---|
| 1 | Marginal solder joint expanding with temperature | Errors worsen when heated; clear when cooled — reflow suspect joint |
| 2 | VDD/VDDQ droops under sustained load | Scope VDD with memory benchmark running; measure ripple |
| 3 | Signal integrity marginal at operating temperature | Errors in specific lane, correlated with DRAM temp |
| 4 | DRAM self-heating beyond operating range | Check DRAM junction temperature; add airflow |

**Recommended measurements:**
1. Record error onset time and ambient temperature
2. Scope VDD ripple under load vs. idle
3. Thermal camera or IR thermometer on DRAM devices at failure time
4. Repeat test with active cooling — if errors disappear, thermal root cause confirmed

---

## FS-06 — SPD Read Succeeds, Training Fails

**Symptom:**
- BIOS detects the DIMM and reads SPD correctly
- Training fails on first or subsequent boot
- BIOS reports unsupported speed or timing

**Likely causes:**

| Priority | Cause | How to distinguish |
|---|---|---|
| 1 | SPD timing bytes incorrect for actual module | Compare SPD tCL/tRCD/tRP/tRAS to DRAM datasheet spec |
| 2 | Clock signal marginal (jitter / levelissue) | Scope CK_t/CK_c; check eye opening |
| 3 | Platform does not support the programmed speed | Try lower speed profile in BIOS (force DDR4-2133) |
| 4 | VREF marginal | Probe pin 146 (VREFCA) during training |

**Recommended measurements:**
1. SPD dump: compare timing bytes against JEDEC DDR4 SPD spec table
2. Force BIOS to DDR4-2133 (minimum JEDEC baseline) — if training passes, SPD speed profile is wrong
3. Scope CK differential eye at edge connector

---

## Quick Reference: Symptom → Signature Map

| Symptom | First signature to check |
|---|---|
| DIMM slot not detected | FS-01 (VDDSPD / SPD) |
| Boot loop at POST | FS-02 (VDD/RESET_n/CKE) |
| Wrong capacity shown | FS-03 (DQ lane open) |
| Same address fails every run | FS-04 (stuck DQ bit) |
| Errors after hours of soak | FS-05 (thermal / margin) |
| SPD OK but training fails | FS-06 (timing / clock) |

---

*See also: `08-2_bringup_ladder.md` (stop conditions), `08-3_test_matrix.md` (failure taxonomy).*

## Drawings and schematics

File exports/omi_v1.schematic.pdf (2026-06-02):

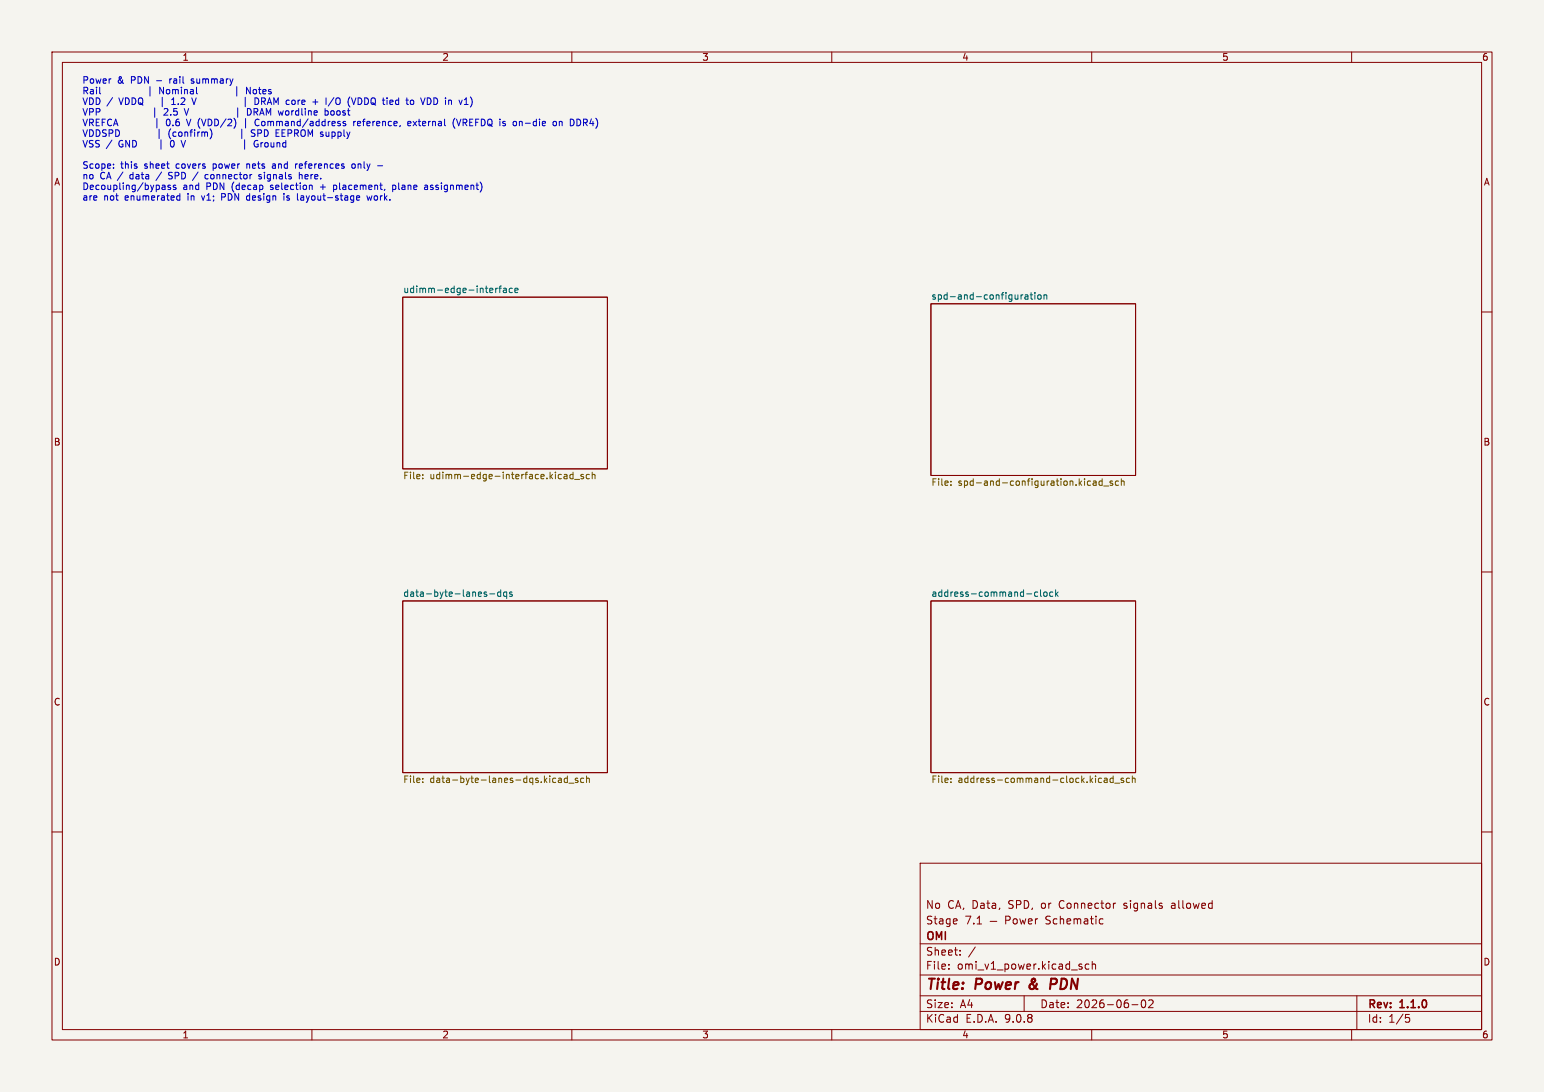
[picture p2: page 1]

udimm-edge-interface File: udimm-edge-interface.kicad_sch

spd-and-configuration File: spd-and-configuration.kicad_sch

data-byte-lanes-dqs File: data-byte-lanes-dqs.kicad_sch

address-command-clock File: address-command-clock.kicad_sch

Id: 1/5 Title: Power & PDN

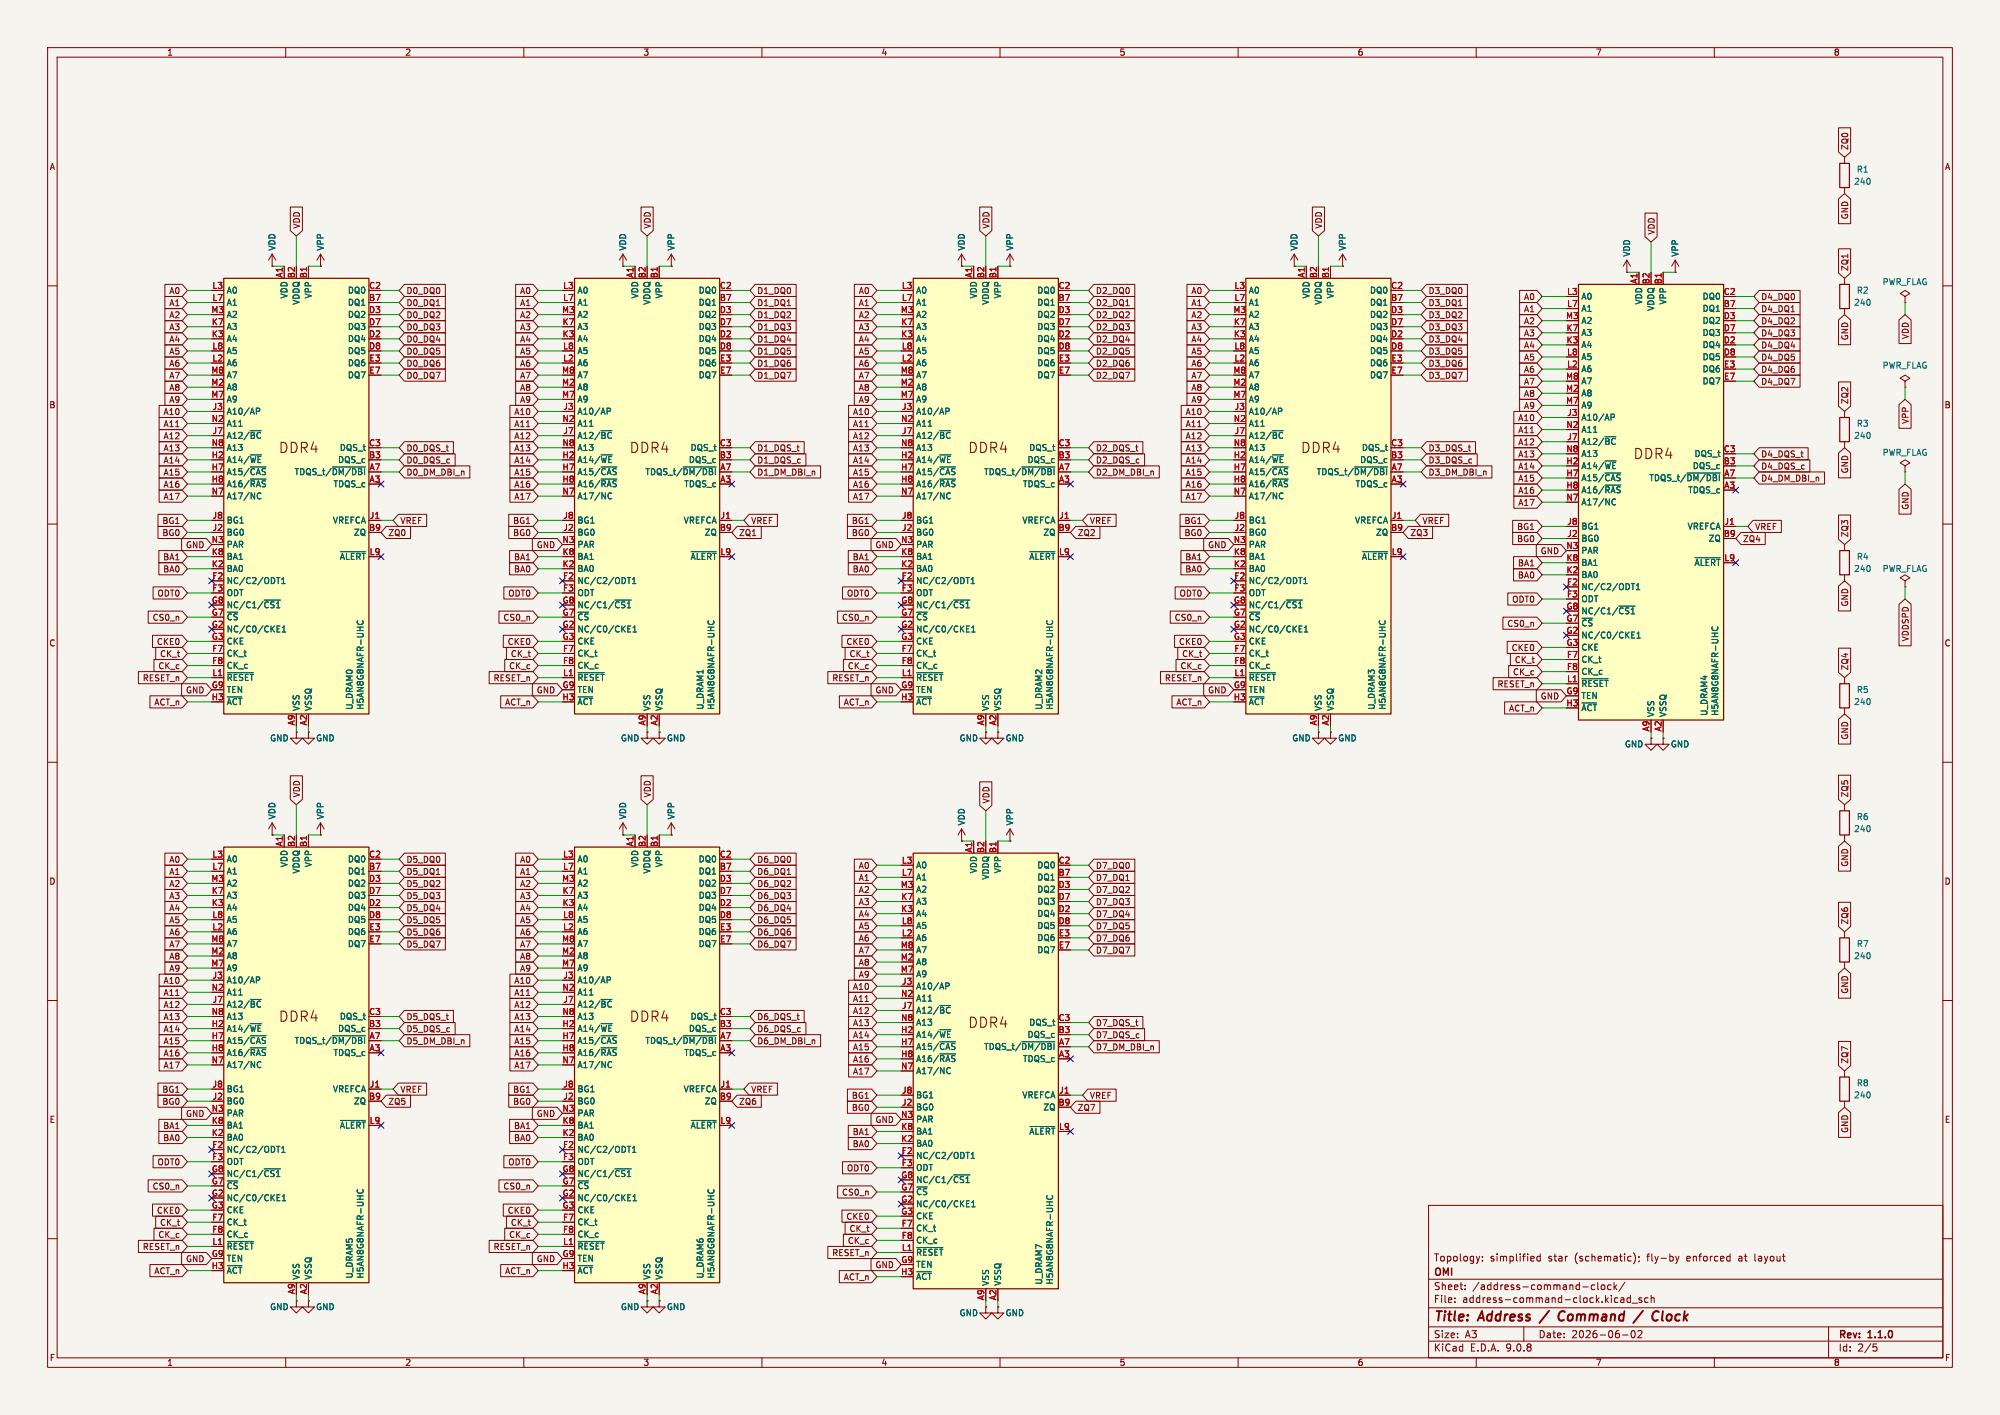
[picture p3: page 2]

Id: 2/5 Title: Address / Command / Clock

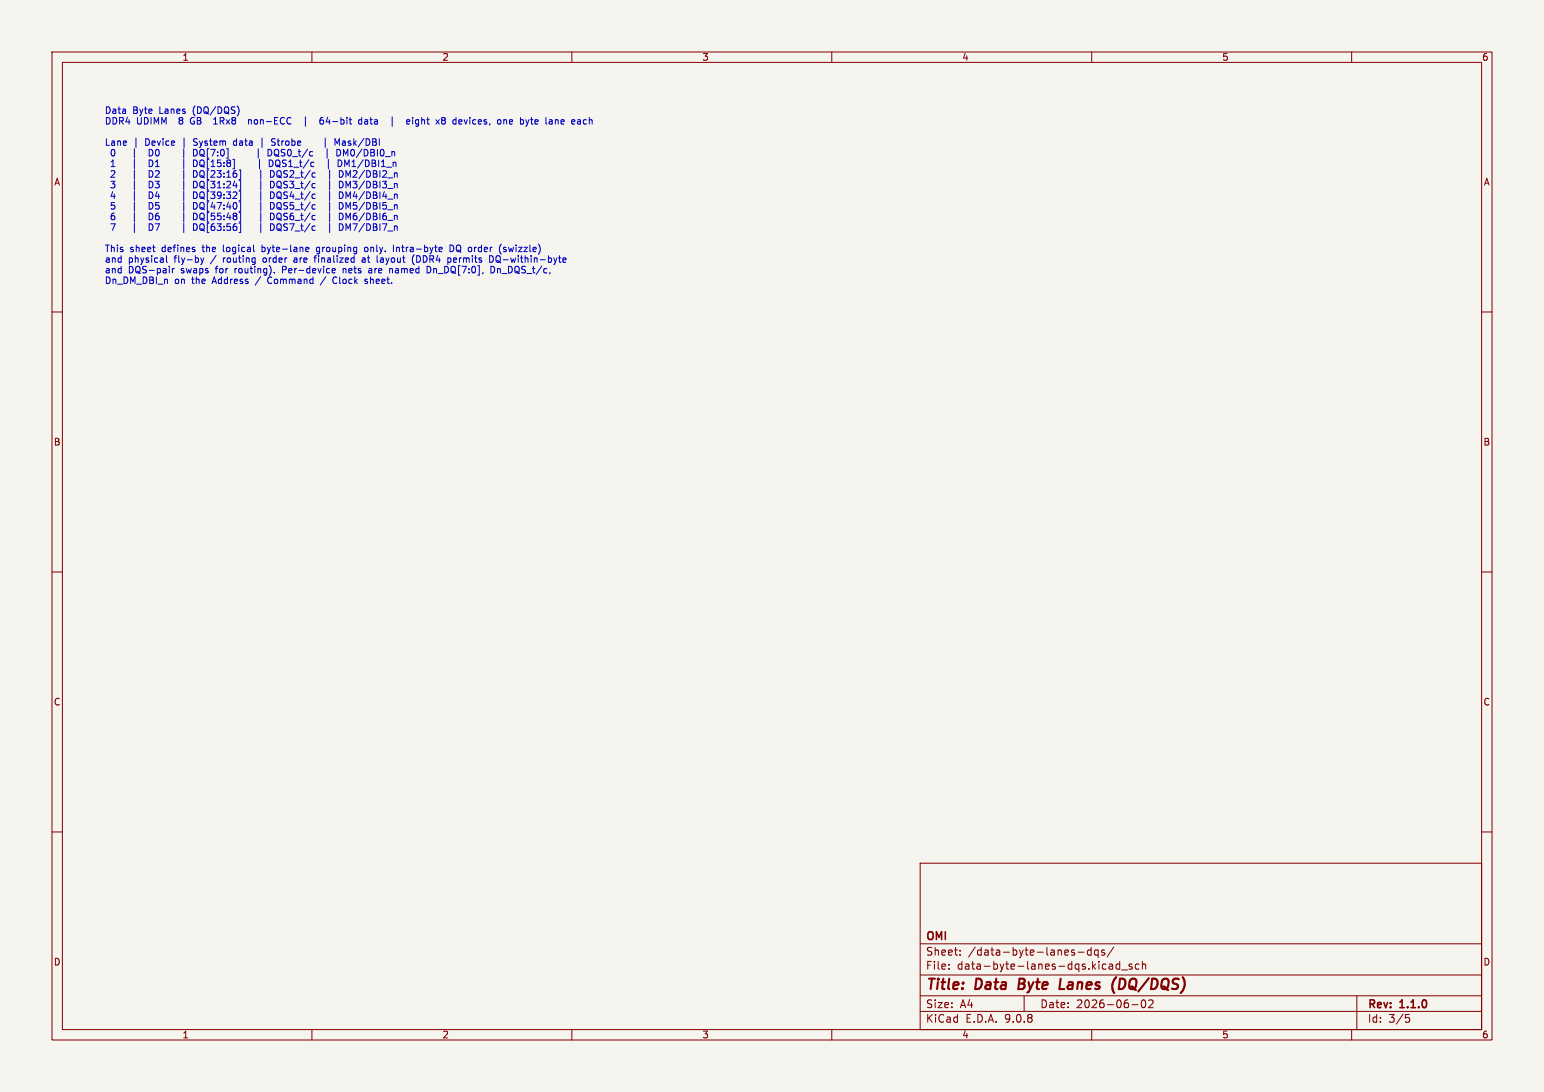
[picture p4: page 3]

Id: 3/5 Title: Data Byte Lanes (DQ/DQS) File: data-byte-lanes-dqs.kicad_sch Sheet: /data-byte-lanes-dqs/ OMI

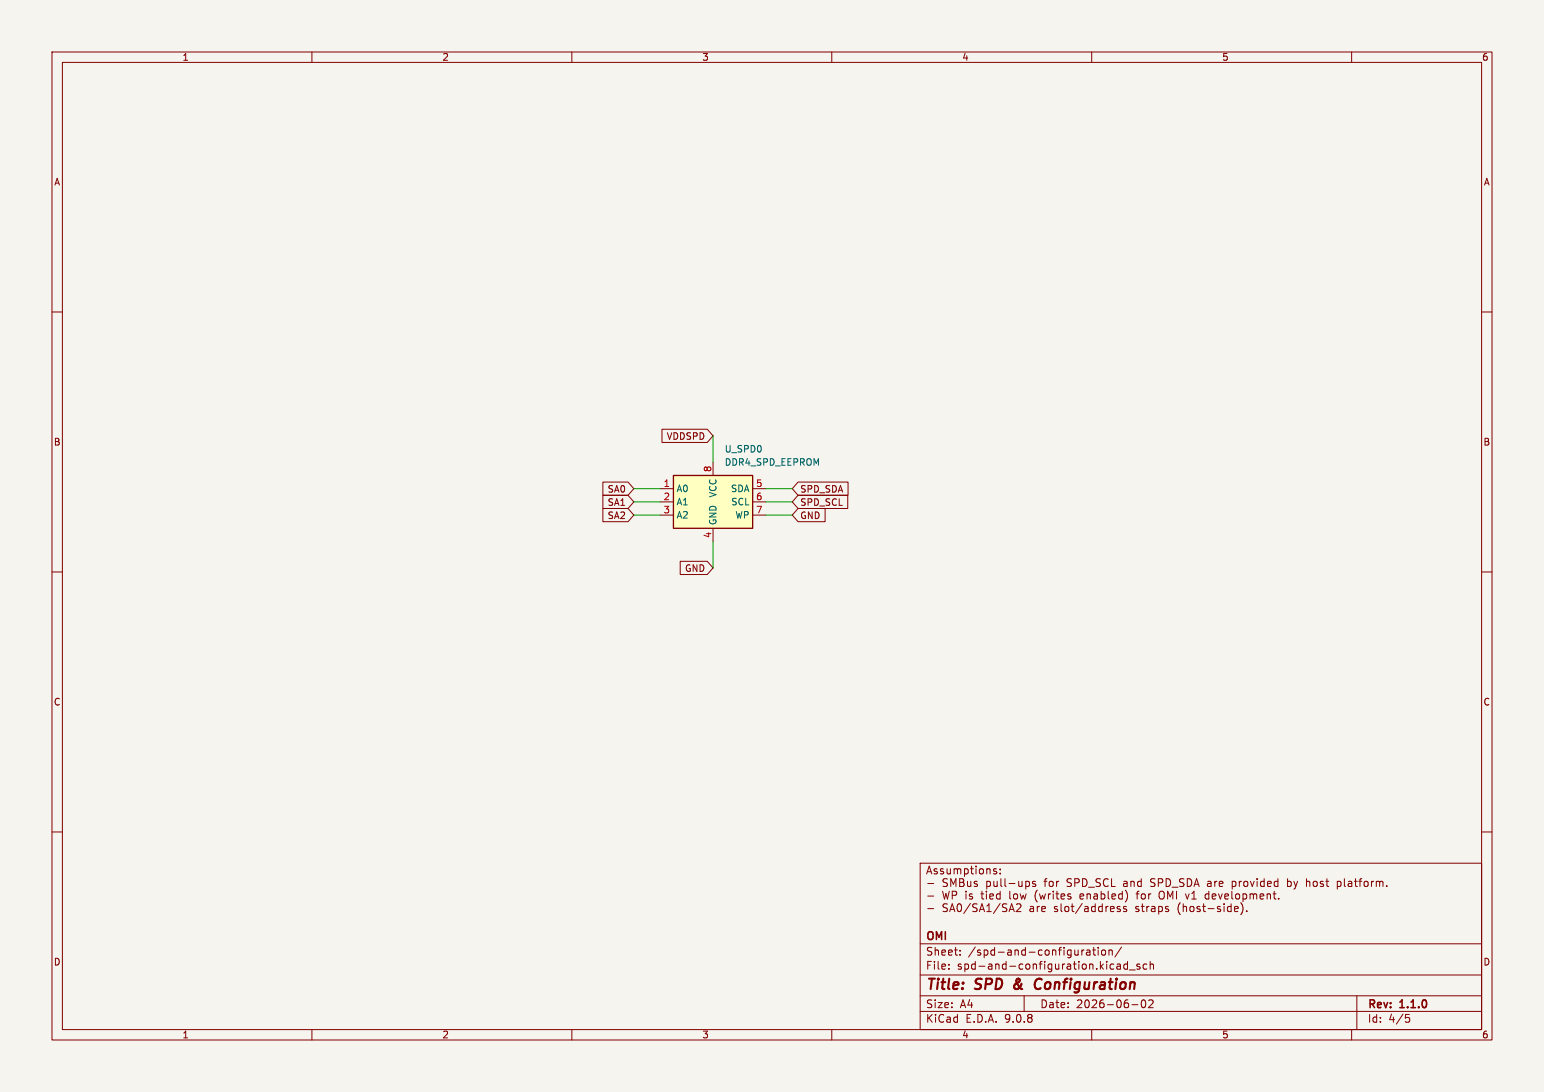
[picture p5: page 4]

File: spd-and-configuration.kicad_sch Sheet: /spd-and-configuration/ OMI Assumptions:

Id: 4/5 Title: SPD & Configuration

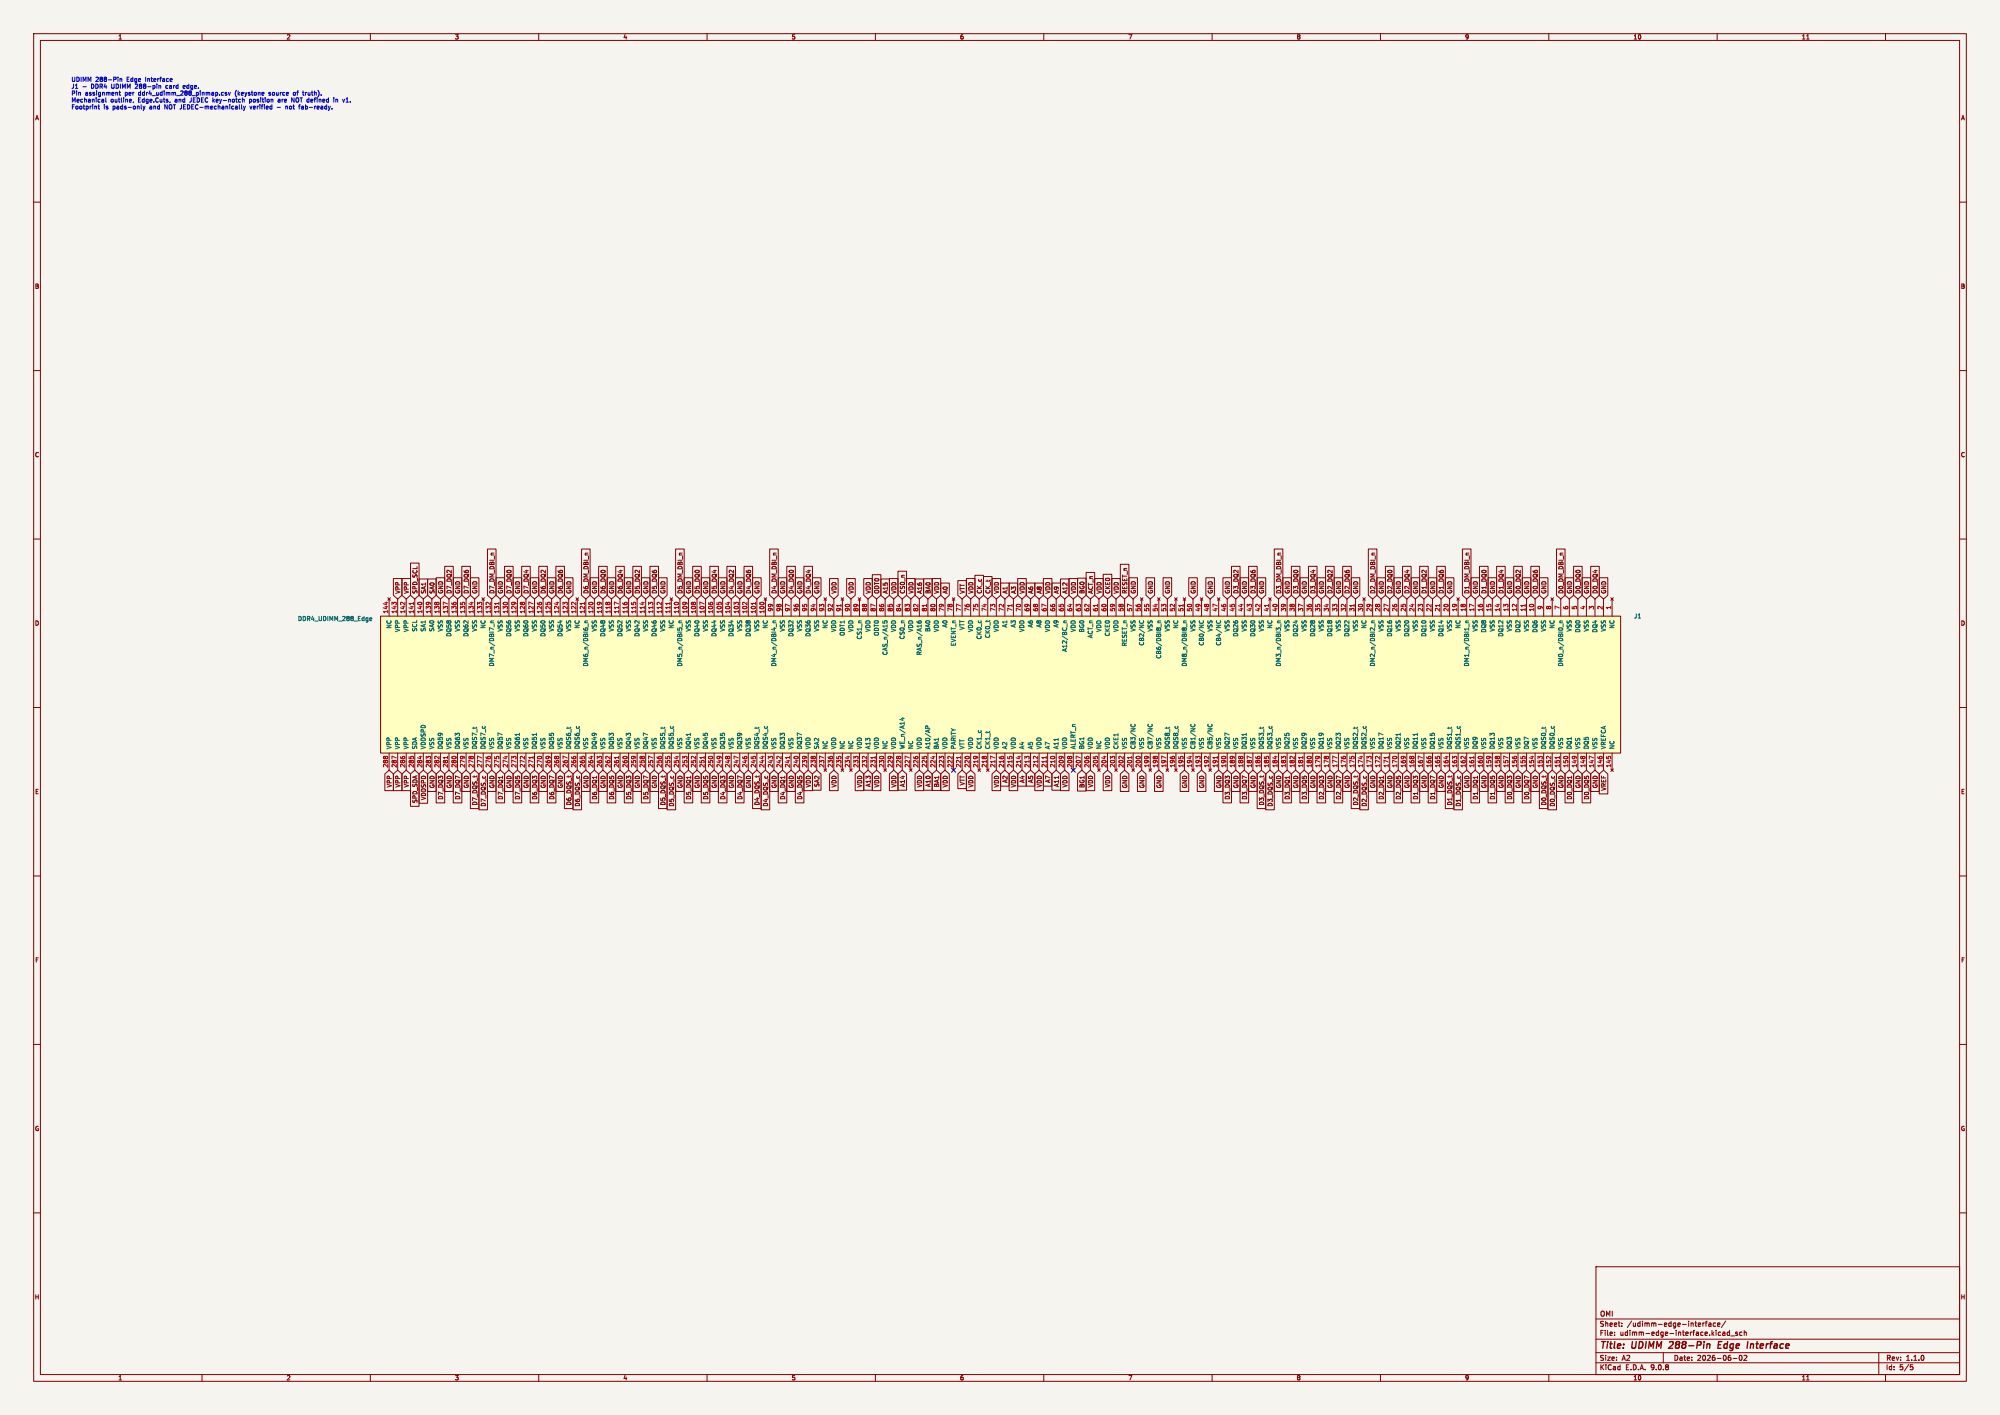
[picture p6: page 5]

9 DQ6 10 VSS 11 DQ2 12 VSS 13 DQ12 14 VSS 15 DQ8 16 VSS 17 DM1_n/DBI1_n 18 NC 19 VSS 20 DQ14 21 VSS 22 DQ10 23 VSS 24 DQ20 25 VSS 26 DQ16 27 VSS 28 DM2_n/DBI2_n 29 NC 30 VSS 31 DQ22 32 VSS 33 DQ18 34 VSS 35 DQ28 36 VSS 37 DQ24 38 VSS 39 DM3_n/DBI3_n 40 NC 41 VSS 42 DQ30 43 VSS 44 DQ26 45 VSS 46 CB4/NC 47 VSS 48 CB0/NC 49 VSS 50 DM8_n/DBI8_n 51 NC 52 VSS 53 CB6/DBI8_n 54 VSS 55 CB2/NC 56 VSS 57 RESET_n 58 VDD 59 CKE0 60 VDD 61 ACT_n 62 BG0 63 VDD 64 A12/BC_n 65 A9 66 VDD 67 A8 68 A6 69 VDD 70 A3 71 A1 72 VDD 73 CK0_t 74 CK0_c 75 VDD 76 VTT 77 EVENT_n 78 A0 79 VDD 80 BA0 81 RAS_n/A16 82 VDD 83 CS0_n 84 VDD 85 CAS_n/A15 86 ODT0 87 VDD 88 CS1_n 89 VDD 90 ODT1 91 VDD 92 NC 93 VSS 94 DQ36 95 VSS 96 DQ32 97 VSS 98 DM4_n/DBI4_n 99 NC 100 VSS 101 DQ38 102 VSS 103 DQ34 104 VSS 105 DQ44 106 VSS 107 DQ40 108 VSS 109 DM5_n/DBI5_n 110 NC 111 VSS 112 DQ46 113 VSS 114 DQ42 115 VSS 116 DQ52 117 VSS 118 DQ48 119 VSS 120 DM6_n/DBI6_n 121 NC 122 VSS 123 DQ54 124 VSS 125 DQ50 126 VSS 127 DQ60 128 VSS 129 DQ56 130 VSS 131 DM7_n/DBI7_n 132 NC 133 VSS 134 DQ62 135 VSS 136 DQ58 137 VSS 138 SA0 139 SA1 140 SCL 141 VPP 142 VPP 143 NC 144 NC 145 VREFCA 146 VSS 147 DQ5 148 VSS 149 DQ1 150 VSS 151 DQS0_c 152 DQS0_t 153 VSS 154 DQ7 155 VSS 156 DQ3 157 VSS 158 DQ13 159 VSS 160 DQ9 161 VSS 162 DQS1_c 163 DQS1_t 164 VSS 165 DQ15 166 VSS 167 DQ11 168 VSS 169 DQ21 170 VSS 171 DQ17 172 VSS 173 DQS2_c 174 DQS2_t 175 VSS 176 DQ23 177 VSS 178 DQ19 179 VSS 180 DQ29 181 VSS 182 DQ25 183 VSS 184 DQS3_c 185 DQS3_t 186 VSS 187 DQ31 188 VSS 189 DQ27 190 VSS 191 CB5/NC 192 VSS 193 CB1/NC 194 VSS 195 DQS8_c 196 DQS8_t 197 VSS 198 CB7/NC 199 VSS 200 CB3/NC 201 VSS 202 CKE1 203 VDD 204 NC 205 VDD 206 BG1 207 ALERT_n 208 VDD 209 A11 210 A7 211 VDD 212 A5 213 A4 214 VDD 215 A2 216 VDD 217 CK1_t 218 CK1_c 219 VDD 220 VTT 221 PARITY 222 VDD 223 BA1 224 A10/AP 225 VDD 226 NC 227 WE_n/A14 228 VDD 229 NC 230 VDD 231 A13 232 VDD 233 NC 234 NC 235 VDD 236 NC 237 SA2 238 VDD 239 DQ37 240 VSS 241 DQ33 242 VSS 243 DQS4_c 244 DQS4_t 245 VSS 246 DQ39 247 VSS 248 DQ35 249 VSS 250 DQ45 251 VSS 252 DQ41 253 VSS 254 DQS5_c 255 DQS5_t 256 VSS 257 DQ47 258 VSS 259 DQ43 260 VSS 261 DQ53 262 VSS 263 DQ49 264 VSS 265 DQS6_c 266 DQS6_t 267 VSS 268 DQ55 269 VSS 270 DQ51 271 VSS 272 DQ61 273 VSS 274 DQ57 275 VSS 276 DQS7_c 277 DQS7_t 278 VSS 279 DQ63 280 VSS 281 DQ59 282 VSS 283 VDDSPD 284 SDA 285 VPP 286 VPP 287 VPP 288

1 VSS
File: udimm-edge-interface.kicad_sch Sheet: /udimm-edge-interface/ OMI NC

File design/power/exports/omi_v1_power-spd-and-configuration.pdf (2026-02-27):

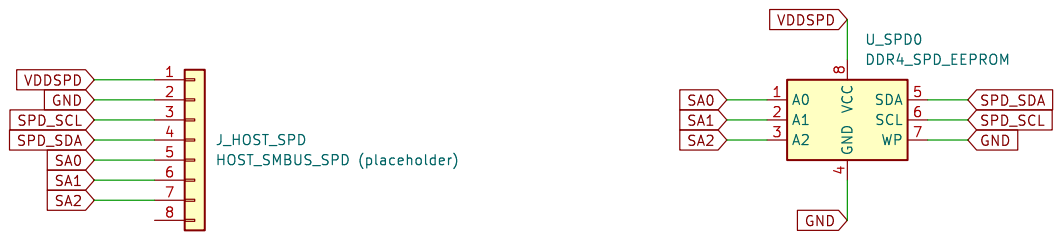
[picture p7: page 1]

File: spd-and-configuration.kicad_sch Sheet: /spd-and-configuration/ OMI Assumptions:

Id: 4/4 Title: Stage 7.4 þÿ SPD & Configuration

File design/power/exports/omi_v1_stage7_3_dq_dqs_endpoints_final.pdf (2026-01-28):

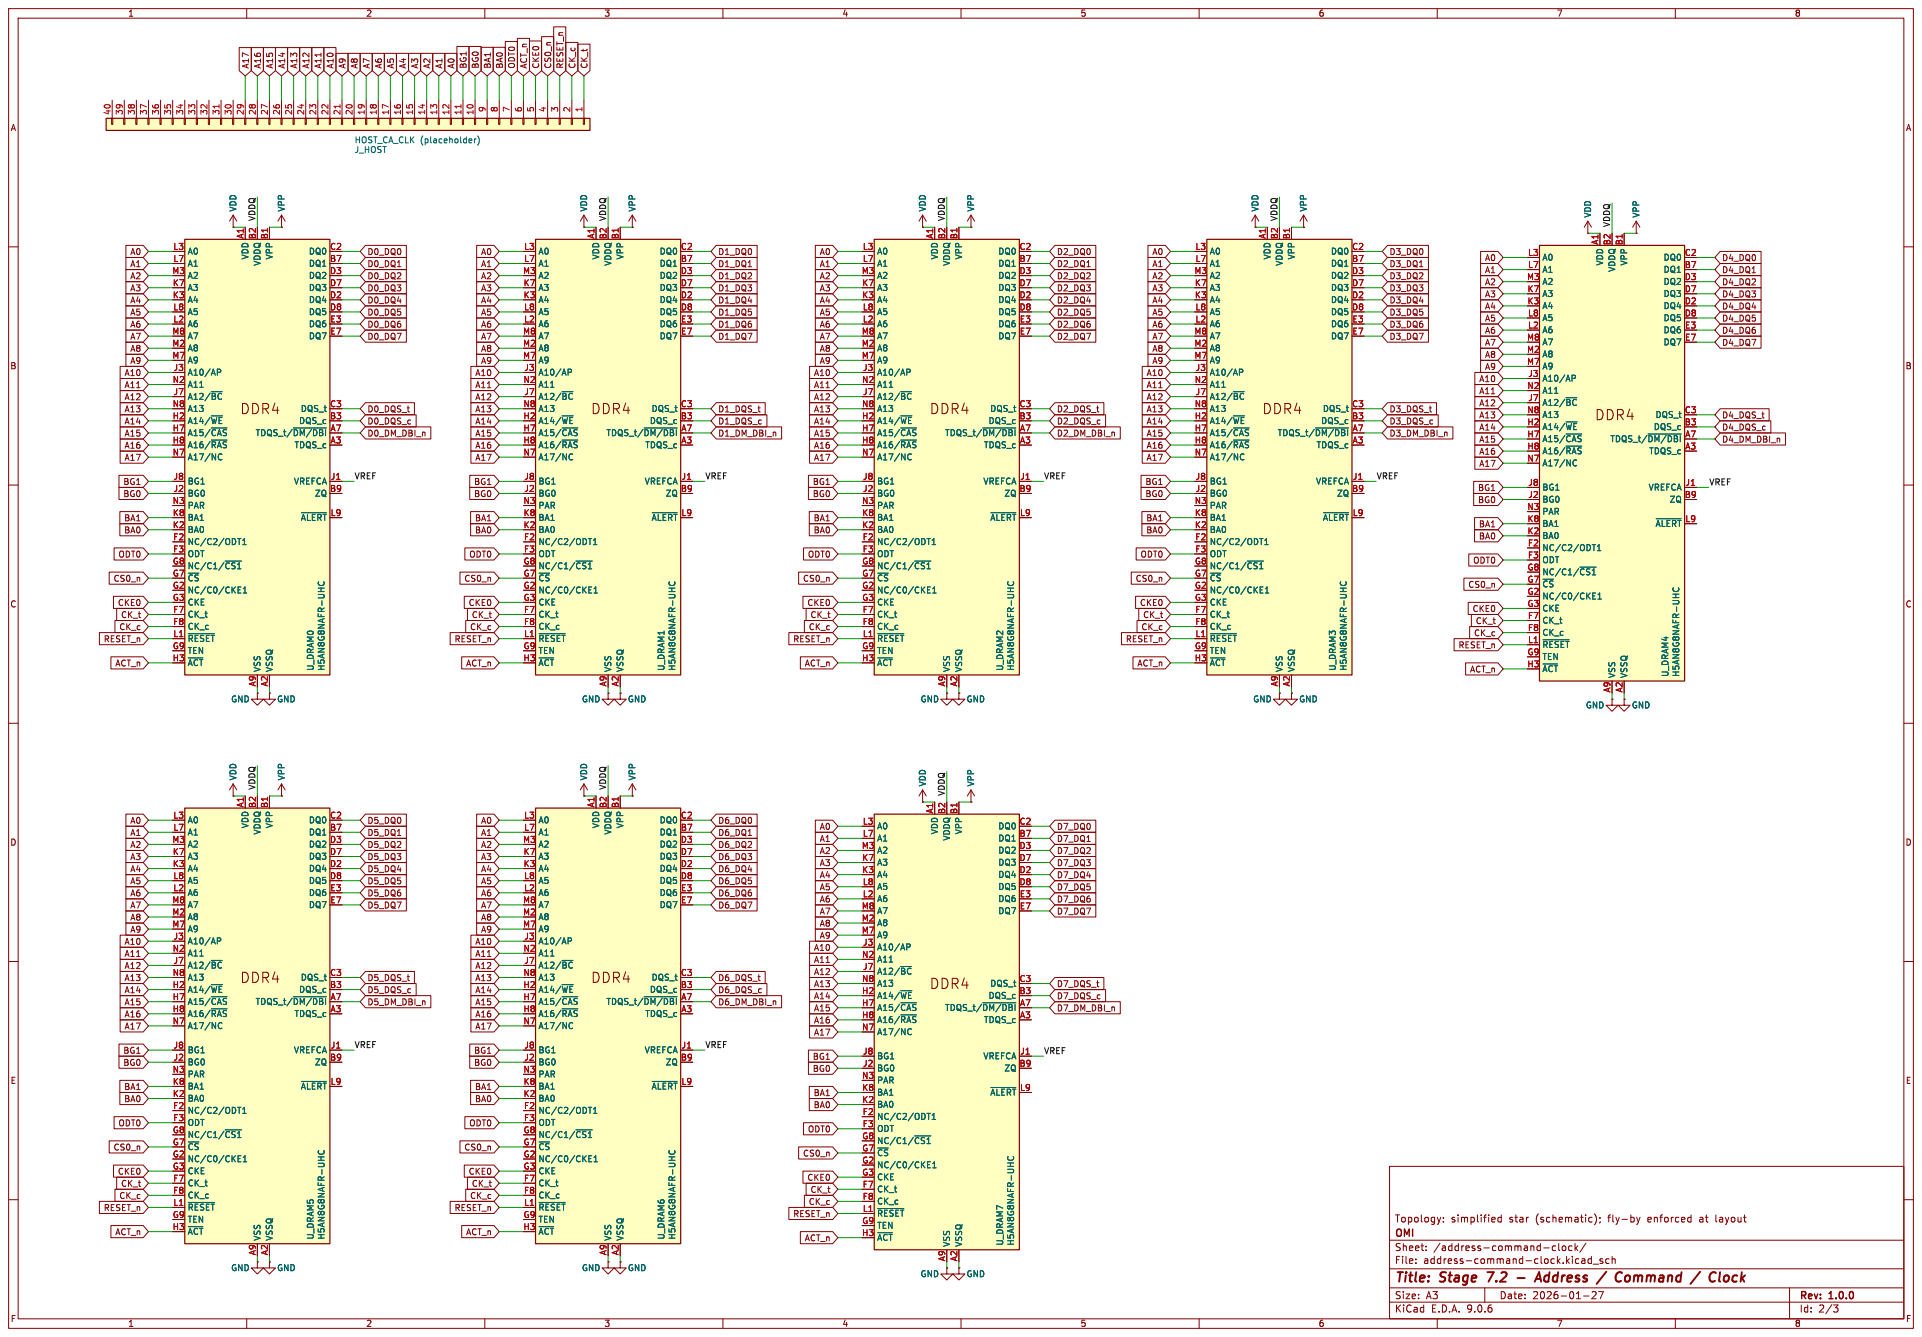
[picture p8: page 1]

Id: 2/3 Title: Stage 7.2 - Address / Command / Clock

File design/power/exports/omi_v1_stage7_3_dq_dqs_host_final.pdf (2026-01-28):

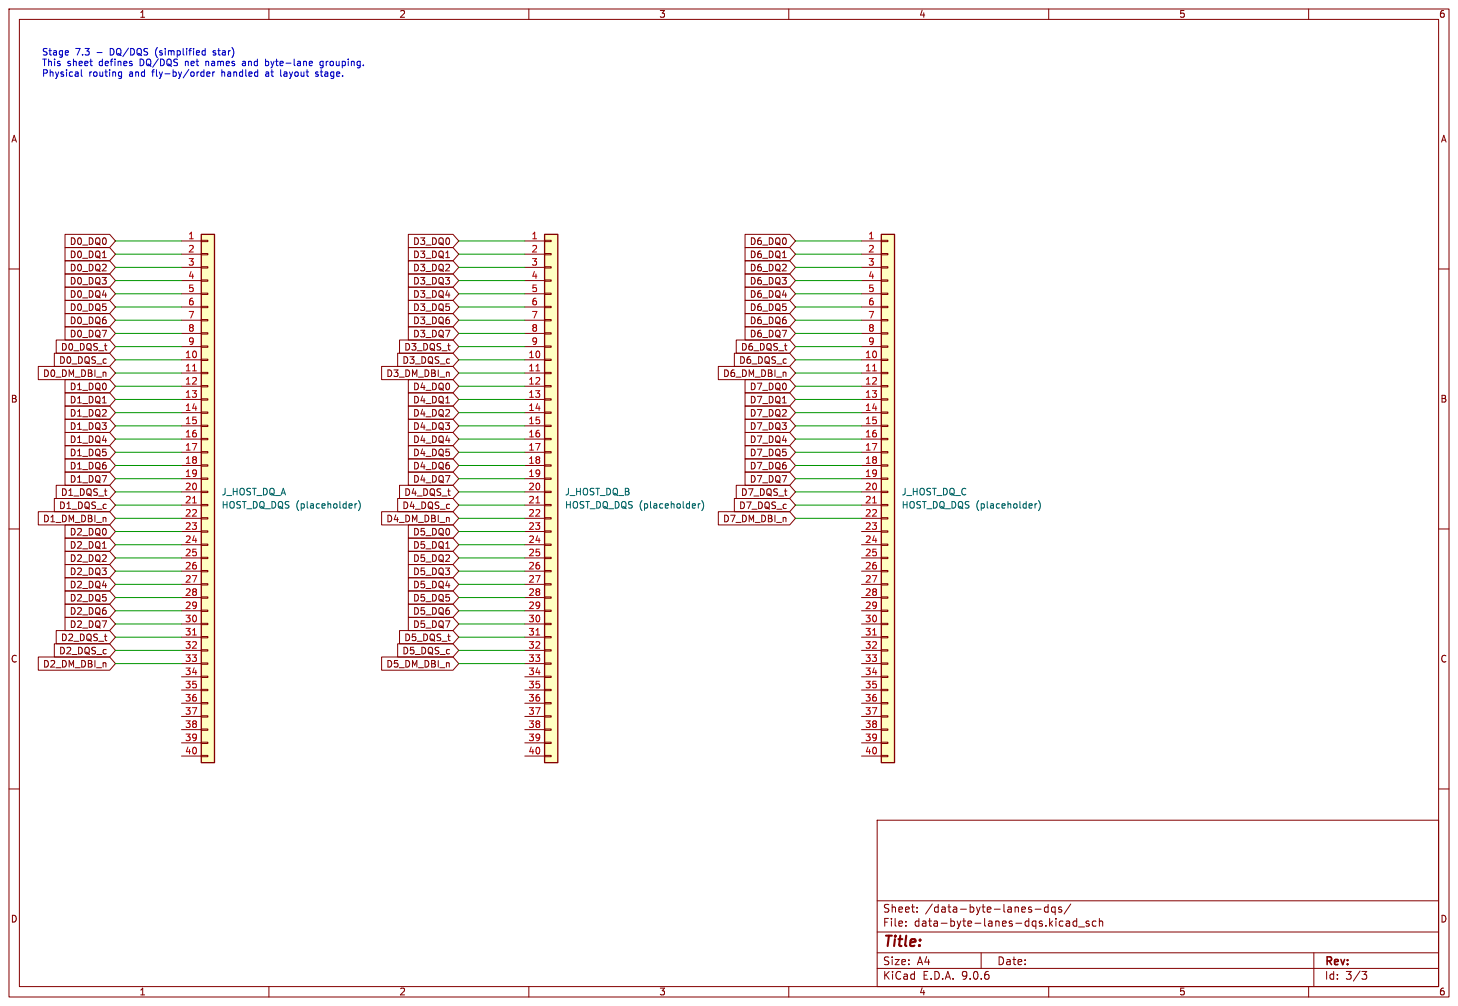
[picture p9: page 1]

Id: 3/3 Title: File: data-byte-lanes-dqs.kicad_sch Sheet: /data-byte-lanes-dqs/ 123456789

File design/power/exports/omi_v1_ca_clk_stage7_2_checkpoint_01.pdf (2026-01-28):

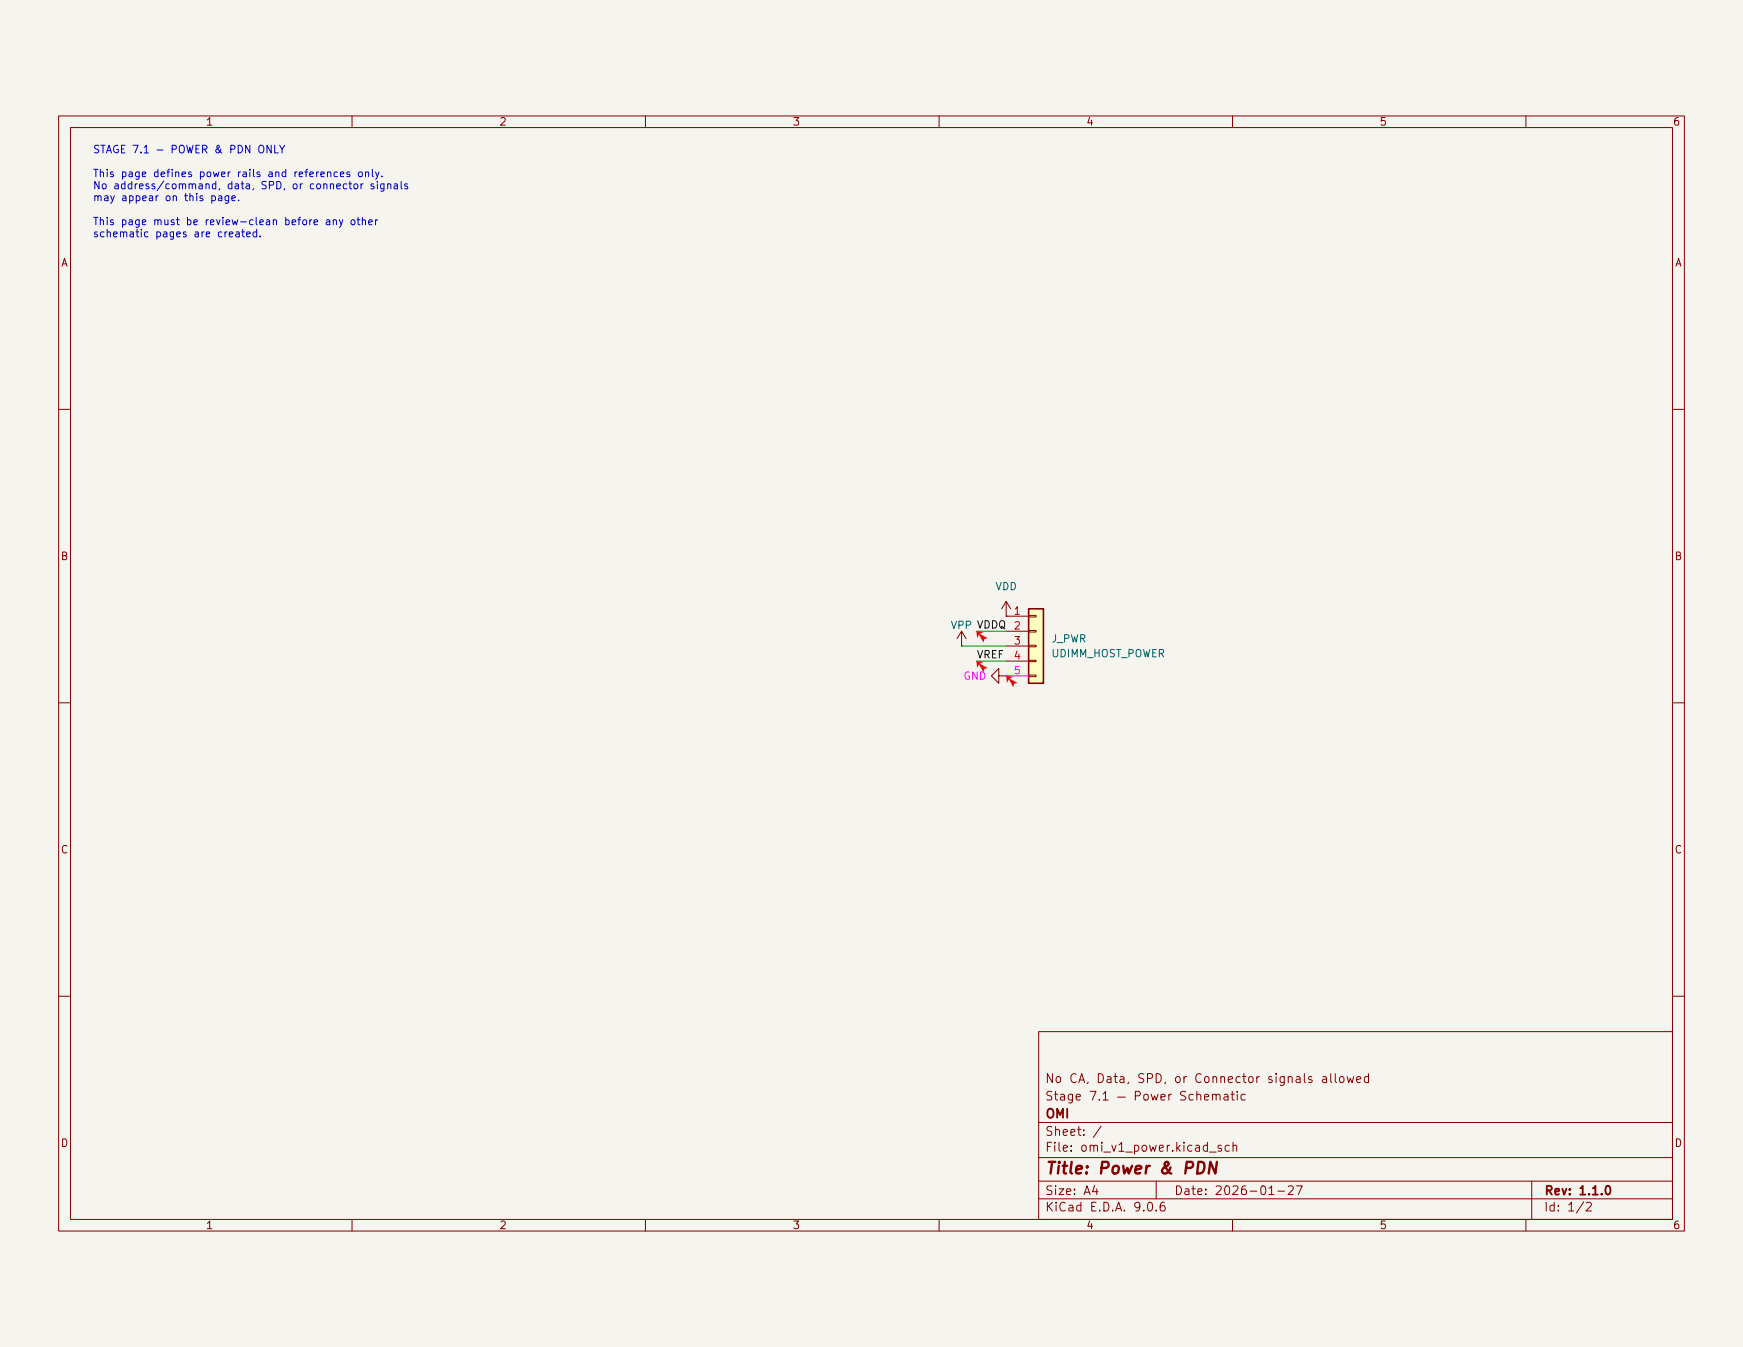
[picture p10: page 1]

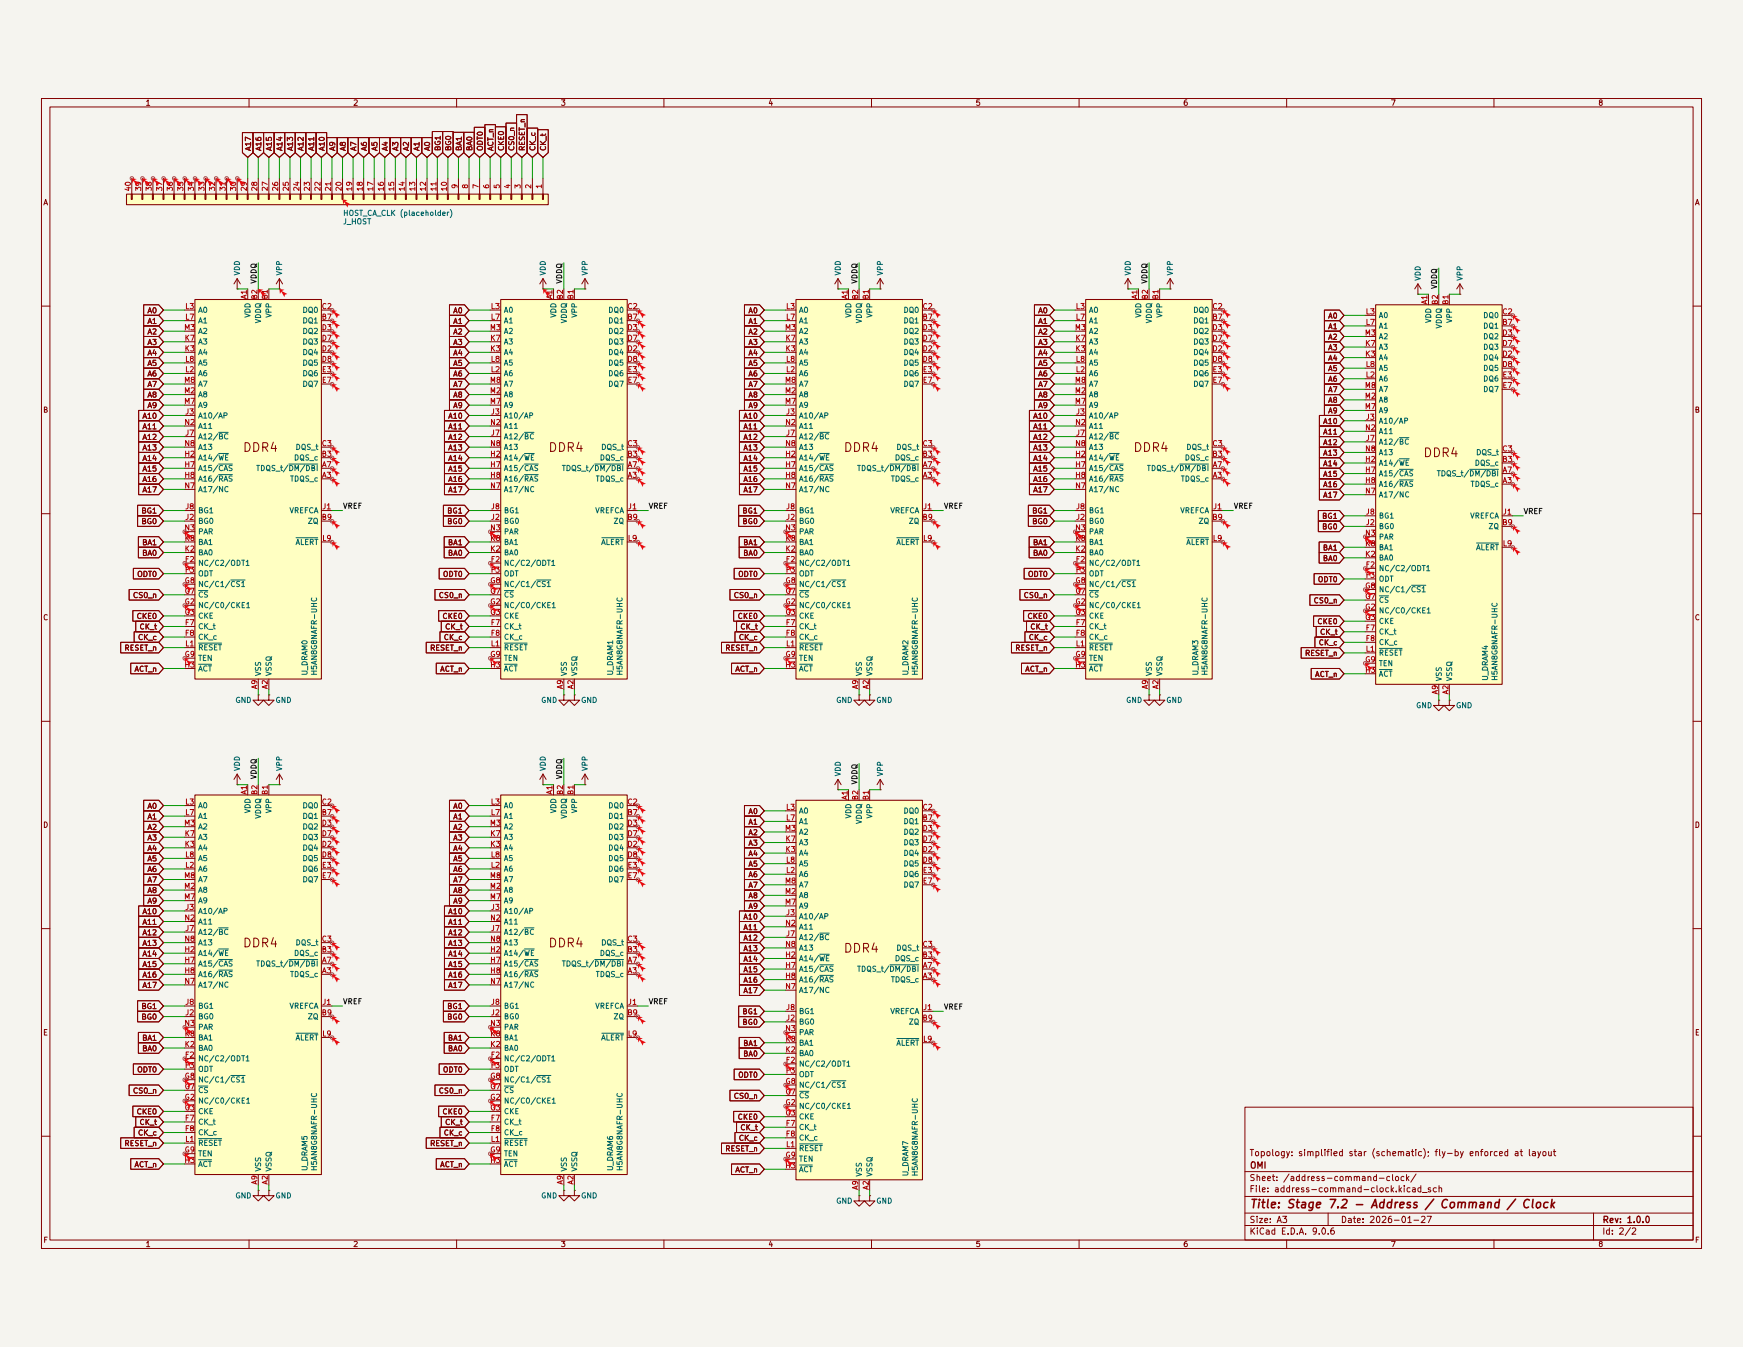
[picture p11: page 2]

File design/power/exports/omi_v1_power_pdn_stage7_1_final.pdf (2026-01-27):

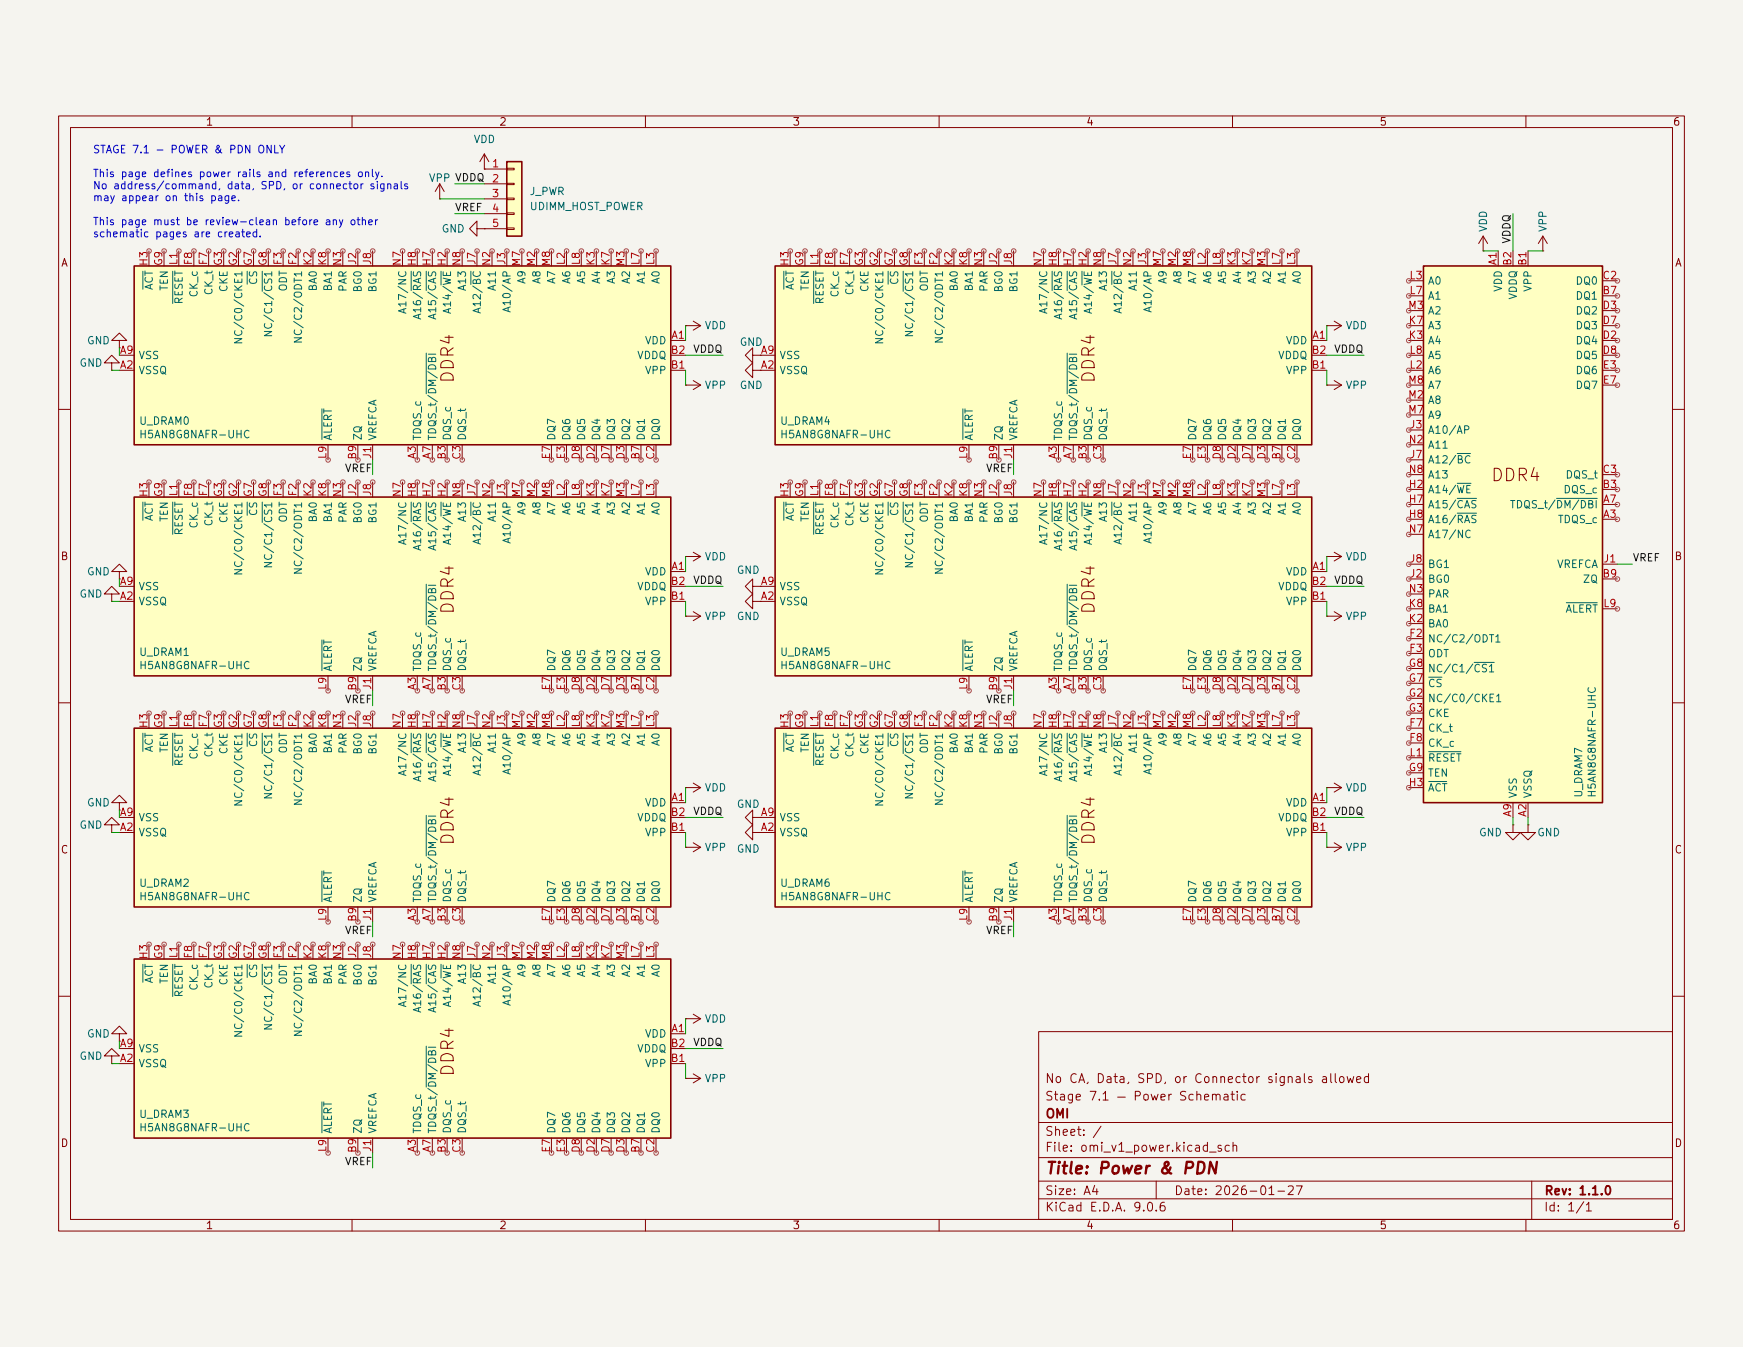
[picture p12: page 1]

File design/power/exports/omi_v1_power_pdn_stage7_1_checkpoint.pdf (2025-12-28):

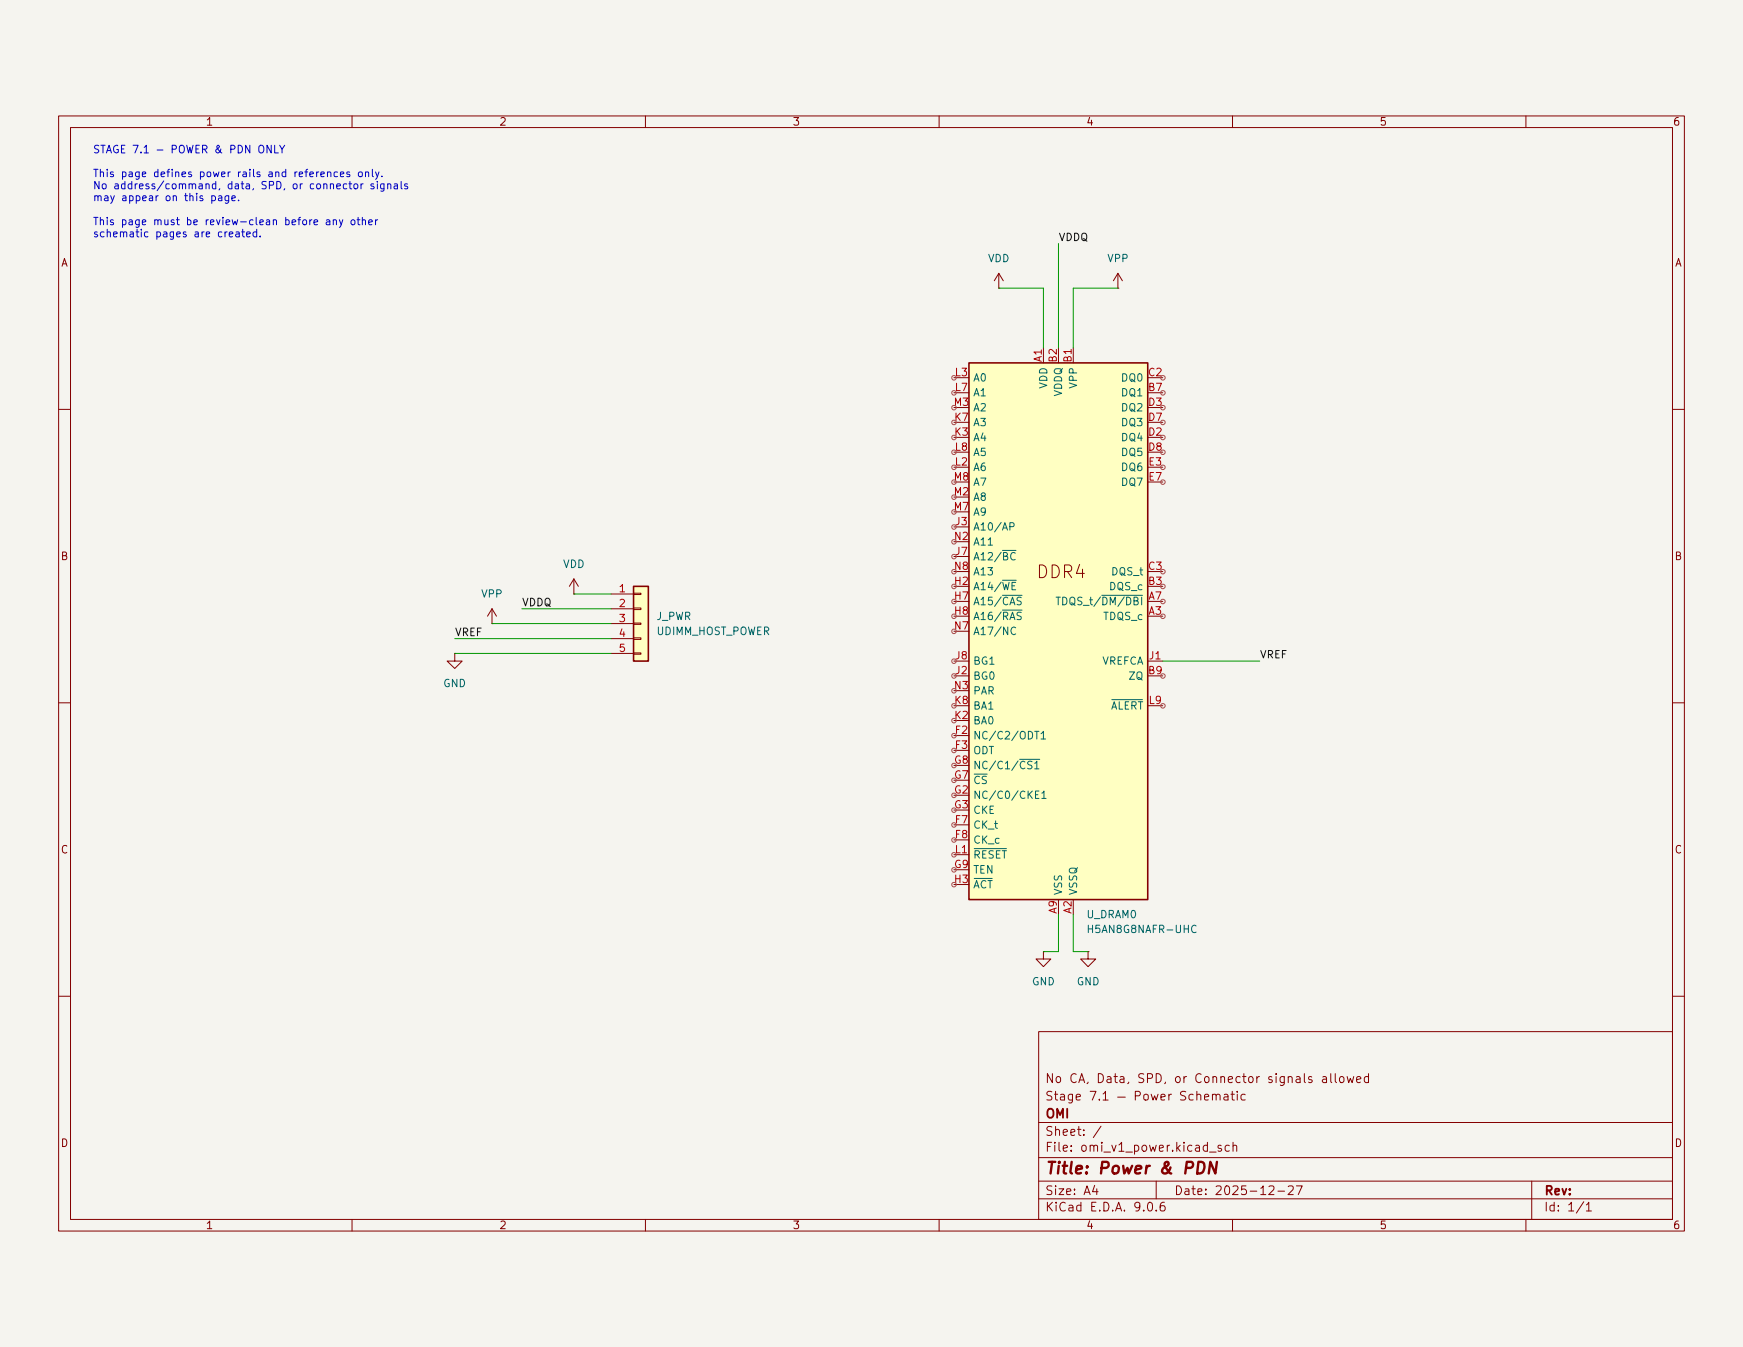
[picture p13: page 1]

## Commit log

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2025-12-27 feat: Add initial KiCad project files for omi_v1_power schematic and PCB, including related documentation.
    [omi_v1_power.kicad_pcb, omi_v1_power.kicad_sch]
2025-12-28 feat: add initial OMI v1 power and PDN schematic with PDF documentation
    [omi_v1_power.kicad_sch]
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2026-01-27 feat: Add OMI v1 Stage 7.1 Power & PDN final documentation and PDF artifact.
    [omi_v1_power.kicad_sch]
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2026-01-28 feat: Add OMI v1 Stage 7.2 CA/CLK checkpoint 01 documentation and PDF artifact.
    [address-command-clock.kicad_sch, omi_v1_power.kicad_sch]
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2026-02-27 feat: Implement OMI v1 power SPD and configuration schematic with accompanying documentation.
    [omi_v1_power.kicad_sch, spd-and-configuration.kicad_sch]
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2026-02-27 feat: Add initial KiCad power schematic, related sub-schematics, and documentation for schematic capture stage 7.
    [omi_v1_power.kicad_sch, spd-and-configuration.kicad_sch, udimm-edge-interface.kicad_sch]
2026-02-28 feat: Add OMI v1 DDR4 UDIMM net manifest documentation and connector pin mapping.
    [ddr4_udimm_288_pinmap.csv]
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2026-02-28 feat: Add DDR4 UDIMM 288-pin pinmap CSV and its corresponding reference documentation.
    [ddr4_udimm_288_pinmap.csv]
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2026-03-06 feat: Introduce L0 artifact integrity validation including pinmap verification, naming rules, and review templates.
    9 new files implementing the L0 validation infrastructure:
    File Purpose
    docs/08_validation_and_review/scripts/verify_pinmap.py 288/288 pin map verification (6-7 checks)
    docs/08_validation_and_review/scripts/verify_naming.py Byte-lane isolation & naming audit (9 checks)
    docs/08_validation_and_review/scripts/l0_runner.py Master orchestrator with evidence generation
    docs/08_validation_and_review/L0_artifact_integrity/naming_rules.md Regex patterns & naming conventions
    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
    [lane_matrix.csv]
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2026-03-07 feat: Add L1 bench electrical validation assets, including documentation, templates, scripts, and evidence files.
    [measurement_log_template.csv, probe_sequence.csv, probe_sequence_reference.csv]
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2026-06-01 chore(phase1): capture kicad-cli baseline artifacts (ERC, netlist, BOM)
    Read-only kicad-cli 9.0.8 run against the unmodified root schematic
    design/power/omi_v1_power/omi_v1_power.kicad_sch:
    - erc_report.json / erc_report.txt (--severity-all; 131 violations)
    - netlist.kicadxml.xml / netlist.net (kicadxml + s-expr)
    - bom.csv
    - _console_log.txt (commands + warnings; note: "annotation errors")
    No design files modified; no PCB commands run.
    [bom.csv]
2026-06-01 docs(phase1): add PHASE1_BASELINE.md synthesis + gap list
    Measurement-only baseline of the unmodified schematic (kicad-cli 9.0.8):
    environment, ERC tally (131 violations by type/sheet), netlist/BOM
    summary (15 components, 238 nets, 9/15 footprints, 8 DRAM), pinmap
    cross-check (121/123 intended signal nets named), and a phase-tagged
    gap list. Key measured corrections to the audit: DRAM count is 8 (not
    9); footprints mostly assigned; net naming ~98% aligned with the edge
    pinmap (the real gap is the missing 288-pin edge connector).
2026-06-01 fix(phase1): correct ERC and pinmap tallies from authoritative re-parse
    A direct ConvertFrom-Json / [xml] re-parse of the artifacts corrected
    three counts that the analysis subagents had reported imprecisely
    (totals were always right; the splits were not):
    - ERC by type: 108 not-connected / 16 not-driven / 5 power-not-driven / 2 dangling (was 98/18/13/2).
    - ERC by sheet: acc 94, data 32, spd 2, root 3, edge 0 (was 100/28/2/1/0).
    - Pinmap: 130 unique omi_net names, 125 present verbatim (96.2%), 5 absent
    (ALERT_n, PARITY, NC, VREF, VTT) (was 121/123, 2 absent).
    Totals (131 ERC, 15 comps, 238 nets, 8 DRAM, 9/15 footprints) unchanged.
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2026-06-01 feat(phase2): place J1 edge connector on the edge sheet + ERC/netlist evidence
    Fills the previously-empty udimm-edge-interface.kicad_sch with one J1 instance
    of omi:DDR4_UDIMM_288_Edge and a global_label (the design's dominant label type)
    on every non-NC pin, so the omi_net names merge across sheets. NC pins are left
    unconnected per their no_connect type. Only the edge sheet is modified.
    Validated: ERC + netlist run; sheet renders. Netlist shows J1 with all 288 pins
    on the expected nets (79->A0, 2->GND, 59->VDD, 3->D0_DQ4, ...); 125 nets merge
    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
    [udimm-edge-interface.kicad_sch]
2026-06-01 docs(phase2): implementation doc for the edge-connector symbol + placement
    Records problem/motivation, the CSV->symbol mapping, the verified symbol-local
    ->sheet transform math, design decisions (passive power default, NC=no_connect,
    upgrade-to-copy reproducibility), the full verification suite, and the +4 ERC
    delta with the Phase-3 handoff list.
2026-06-01 feat(phase3): mark J1 ALERT_n as intentional no-connect (edge sheet)
    CSV marks ALERT_n host-supplied / not-enabled-in-v1; only J1 referenced it, so
    its global label dangled. Replace the dangling global_label at the J1 pin
    endpoint (177.8,170.18) with a sheet-level no_connect flag (symbol untouched).
    ERC 135 -> 134 (root global_label_dangling 3 -> 2). Netlist parses.
    [udimm-edge-interface.kicad_sch]
2026-06-01 feat(phase3): mark J1 PARITY as intentional no-connect (edge sheet)
    CSV marks PARITY host-supplied / not-enabled-in-v1; its global label dangled.
    Replace it with a sheet-level no_connect flag at the J1 pin endpoint
    (177.8,205.74). ERC 134 -> 133 (root global_label_dangling 2 -> 1; VREF remains,
    handled by the VREF merge). Netlist parses.
    [udimm-edge-interface.kicad_sch]
2026-06-01 feat(phase3): remove redundant J_HOST_SPD placeholder connector
    J1 now carries every SPD net (VDDSPD/GND/SPD_SCL/SPD_SDA/SA0-2), each verified
    to still hold {J1, U_SPD0} after removal. Removed the symbol + its 7 pin global
    labels + 7 wire stubs; U_SPD0 and its labels keep the nets. Not a jumper.
    ERC 133 -> 132 (spd pin_not_connected 1 -> 0). No new dangling. Netlist parses.
    [spd-and-configuration.kicad_sch]
2026-06-01 feat(phase3): remove redundant J_HOST_DQ_A placeholder (byte lanes D0-D2)
    J1 carries every D0/D1/D2 DQ/DQS/DM net; each verified to still hold
    {J1, U_DRAMn} after removal (e.g. D0_DQ0 -> {J1, U_DRAM0}). Removed symbol + its
    33 pin global labels + 33 wire stubs. J_HOST_DQ_B/C intact (verified: 33/22
    labels, nets unchanged). ERC 132 -> 125 (data pin_not_connected 32 -> 25).
    [data-byte-lanes-dqs.kicad_sch]
2026-06-01 feat(phase3): remove redundant J_HOST_DQ_B placeholder (byte lanes D3-D5)
    J1 carries every D3/D4/D5 net; D3_DQ0 verified {J1, U_DRAM3} after removal.
    Removed symbol + 33 labels + 33 wires. J_HOST_DQ_C intact. ERC 125 -> 118.
    [data-byte-lanes-dqs.kicad_sch]
2026-06-01 feat(phase3): remove redundant J_HOST_DQ_C placeholder (byte lanes D6-D7)
    J1 carries every D6/D7 net; D6_DQ0 -> {J1, U_DRAM6}, D7_DQ7 -> {J1, U_DRAM7}
    after removal. Removed symbol + 22 labels + 22 wires. The data sheet now holds
    only its descriptive text note; DQ/DQS connectivity rides J1 (edge) <-> DRAM
    (acc) via global labels. ERC 118 -> 100 (data sheet now 0 violations).
    [data-byte-lanes-dqs.kicad_sch]
2026-06-01 feat(phase3): remove redundant J_HOST placeholder (CA/CLK/control)
    J1 carries every CK/CA/control net; CK_t and CS0_n verified {J1, 8 DRAMs} after
    removal. A17 (which J1 omits, per CSV "A17 NC for 8Gb") stays an 8-DRAM net,
    not split. Removed symbol + 29 pin global labels (y=24.13) + 29 wire stubs;
    8 DRAMs kept. ERC 100 -> 89 (acc pin_not_connected 75 -> 64; pin_not_driven
    unchanged at 16, no regression).
    [address-command-clock.kicad_sch]
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2026-06-01 feat(phase3): remove redundant root host-power placeholder block (J_PWR + power syms)
    J_PWR (UDIMM_HOST_POWER) and its power-distribution symbols #PWR04/05/06
    (VPP/VDD/GND) + wires + VREF/VDDQ stub labels were a host-power placeholder
    cartoon, now fully superseded by J1 which carries VDD/VPP/GND on real pins
    (verified VDD=91, VPP=21, GND=200, VREF=9 nodes, all {J1, DRAMs(+SPD)}).
    Removing J_PWR alone orphaned #PWR04/05/06 (3 new pin_not_connected + 1
    unconnected_wire_endpoint), so the whole block is removed as one unit. Clears
    both root label_dangling (VREF/VDDQ stubs) + the same_local_global (last local
    VREF gone) + the "schematic has annotation errors" warning (last non-numeric
    ref gone).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
    [omi_v1_power.kicad_sch]
2026-06-01 docs(phase3): final verification — ERC 135->85, connectivity sanity, P5 handoff
    Records per-step ERC deltas, the resolved +4 (ALERT_n/PARITY/VREF x2), the
    placeholder-removal reductions, final connectivity sampling (J1<->DRAM DQ/DQS/CK,
    rails, SPD), and the explicit P4/P5 remainder. Adds final ERC + netlist evidence.
2026-06-01 docs(phase4): plan + baseline (ERC 85) for footprint assignment
    Documentation-first checkpoint before edits. Records the audit (DRAM FBGA-78 +
    SPD DFN-8 both confirmed correct/pad-matched; no 288-pin UDIMM card-edge in
    stock libs -> J1 footprint will be generated) and the per-step plan + mandatory
    mechanical caveat.
2026-06-01 feat(phase4): generate 288-pad DDR4 UDIMM card-edge footprint + project fp-lib-table
    Stdlib-only generator (tools/edge_footprint/gen_edge_footprint.py, Apache-2.0)
    reads the keystone CSV and emits omi.pretty/DDR4_UDIMM_288_Edge.kicad_mod:
    288 connect-rect edge fingers, pad number = CSV pin (1..288), 144 front (F.Cu) +
    144 back (B.Cu) at 0.85mm NOMINAL pitch. Deterministic uuid5; --verify asserts
    288 pads == CSV pins. kicad-cli validated: fp upgrade clean (already canonical),
    fp export svg renders. Registers project fp-lib-table (nickname omi -> omi.pretty).
    MECHANICAL CAVEAT (in the footprint descr/tags + impl doc): pad<->pin numbering
    is correct + kicad-cli-validated, but this is NOT a JED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
2026-06-01 feat(phase4): assign J1 card-edge footprint on the schematic instance
    Set the Footprint property on the placed J1 symbol (edge sheet) to
    omi:DDR4_UDIMM_288_Edge (NOT in omi.kicad_sym -> symbol stays frozen). Validated:
    netlist shows footprints for all 10 real components (J1 + U_DRAM0-7 + U_SPD0);
    power symbols correctly carry none; J1 footprint pads {1..288} == symbol pins
    {1..288} (sets exactly equal); ERC unchanged at 85; omi.kicad_sym +
    tools/edge_symbol untouched. DRAM (FBGA-78) + SPD (DFN-8) confirmed correct,
    no change needed.
    [udimm-edge-interface.kicad_sch]
2026-06-01 docs(phase4): final verification — footprints complete, ERC 85 unchanged
    J1 footprint generated (288 pads == CSV pins, kicad-cli validated) + assigned on
    instance; DRAM/SPD confirmed correct; 10/10 real components footprinted; pad<->pin
    288<->288; ERC unchanged; symbol invariant intact. P5/P7 handoff recorded.
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2026-06-01 feat(phase5): resolve unconnected DRAM balls - genuine NC flags + VSS ties
    Per the datasheet-backed classification (1Rx8 non-ECC, non-3DS, DM enabled,
    C/A parity disabled): no_connect flags on the genuinely-unused balls A3 (TDQS_c,
    DM enabled), F2/G2/G8 (3DS stack-ID + 2nd-rank C0/C1/C2/CKE1/CS1/ODT1), L9
    (ALERT, open-drain error output unused in v1) = 40 flags; and global-label VSS
    ties on G9 (TEN, test-enable input held low) + N3 (PAR, unused C/A-parity input
    tied low rather than floated) = 16 ties (TEN/PAR verified now on GND).
    Honest dispositions only: nothing a functional module would connect is silenced.
    ERC 85 -> 13 (the 8 ZQ + 5 power remain, resolved next). Netlist parses.
    Co-Auth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
    [address-command-clock.kicad_sch]
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2026-06-01 feat(phase5): power drive - VDDQ->VDD merge + PWR_FLAGs (ERC -> 0)
    VDDQ: the local /address-command-clock/VDDQ net (48 DRAM VDDQ balls) had no
    source and no J1 pin (a DDR4 edge has VDD, not VDDQ). Merge it into VDD by
    relabeling the 8 VDDQ locals to global VDD (on a DDR4 UDIMM VDD==VDDQ, bridged
    on-module) -> VDD now 139 nodes. PWR_FLAGs: J1 is the off-board power source but
    its many same-rail pins cannot all be power_output (would multi-drive-conflict;
    a directional retype also broke J1's label-on-pin connectivity, verified +
    reverted). So one PWR_FLAG per rail (VDD/VPP/GND/VDDSPD) marks the supply, each
    via a wire (driver pins need a wire, not a label-on-pin). ERC 5 -> 0 honestly.
    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
    [address-command-clock.kicad_sch]
2026-06-01 docs(phase5): ERC-resolution ledger + frozen-J1 finding (genuine ERC 0)
    Records the 85->0 ledger (40 genuine-NC flags, 16 VSS ties clearing 32 items,
    8 ZQ resistors, 4 PWR_FLAGs, VDDQ->VDD merge), the directional-J1 attempt that
    broke J1's label-on-pin connectivity (reverted; frozen-J1 alternative), the
    integrity self-audit, and final invariant/connectivity evidence.
2026-06-02 feat(phase6): ERC-gated export pipeline (netlist + BOM + PDF + provenance manifest)
    Add tools/export/export.ps1 — a repeatable powershell.exe pipeline that, from the
    ERC-clean schematic, runs ERC as a MANDATORY gate (aborts non-zero, exports never
    come from an unclean design) and then exports the netlist (kicadxml + kicadsexpr),
    a grouped BOM (CSV), and the combined 5-page schematic PDF, finishing with an HONEST
    export-provenance MANIFEST.txt (UTC time, git HEAD, kicad-cli 9.0.8,
    "ERC: 0 violations (clean)", SHA-256 per artifact). Auto-detects KiCad 9.0 (rejects
    10.x); idempotent; exits non-zero on the gate or any failure.
    Additive only — the design is read-only (no *.kicad_sch / symbol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
    [omi_v1.bom.csv]
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2026-06-02 docs(phase7): correct legacy "L1 Bench PASS" - framework dry-run, not a measurement
    The single biggest legacy credibility risk: the "L1 Bench Electrical - PASS" was
    a procedure/tooling dry-run over a BLANK measurement template, not a hardware test.
    - l1_summary.md retitled "FRAMEWORK DRY-RUN (NOT a bench measurement)" with a
    read-first honesty notice (no board built/populated/powered/probed; no
    measurements). Body "PASS" reframed to "ran OK"; measurements row marked BLANK
    TEMPLATE; continuity_report.json annotated as a template-structure check, not a
    continuity measurement. Pointer to exports/erc.json (genuine ERC 0) added.
    - l1_summary.json gets a top-level _HONESTY_NOTE; existing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
2026-06-02 docs(phase7): START_HERE + CHARTER consistency - schematic milestone reached, hardware future
    - START_HERE: intro and the stage table now show the earned completion (Stage 7
    complete - real 288-pin J1, ERC-0, 18/18 footprinted, exports/; Stage 8 L0+ERC
    satisfied, physical L1-L4 await a board; Stages 9-10 not started, beyond the
    wall). Broken docs/05//06 links fixed; repo map adds the real KiCad source
    (design/power/omi_v1_power/) and exports/; "validation" wording scoped.
    - CHARTER: bounded dated status note at 8.1 (Minimum Viable Success) - the
    schematic milestone is reached, but a physically manufactured/bench-tested
    module with measured results remains future/aspirational. No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
2026-06-02 docs(phase7): implementation doc - claim->correction list, decisions, hash-chain integrity note
    Records the P7 honesty pass: motivation (the inverted framing), the full
    claim->correction table, per-file approach, design decisions (branch base =
    phase6-exports; relabel-not-delete for L1; continuity_report.json + evidence
    README left intact for hash integrity; bounded CHARTER note), the evidence
    hash-chain integrity note, and runnable verification steps.
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
